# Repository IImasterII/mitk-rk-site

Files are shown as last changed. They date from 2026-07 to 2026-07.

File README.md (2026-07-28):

# Сайт проекта МИТК‑РК

**Гибридное рабочее колесо. Композитно‑металлическая архитектура для высоконапорных центробежных компрессоров.**

Завершённый многостраничный сайт конкурсного инженерного проекта МИТК‑РК.

## Запуск

Сайт автономный: откройте `index.html` в браузере. Интерактивные STL‑модели и визуальные материалы включены в пакет.

При необходимости используется локальный HTTP‑сервер:

```bash
python3 -m http.server 8080
```

После запуска откройте `http://localhost:8080`.

## Фактическая конфигурация проекта

- наружный диаметр рабочего колеса — 200 мм;
- РК‑200‑Э — 10 основных + 10 сплиттерных лопаток;
- РК‑200‑Д — 13 основных + 13 сплиттерных лопаток;
- расчётный режим — 12 000 мин⁻¹;
- стендовый режим — до 3 000 мин⁻¹;
- два варианта геометрии: РК‑200‑Э (приоритет КПД) и РК‑200‑Д (приоритет полного давления);
- два материальных исполнения: М1 — PA12‑CF10 с втулкой из стали 40Х Ø30/Ø22×49,5 мм; М2 — М1 с одним наружным слоем углеродной ткани 0,2 мм в эпоксидной матрице;
- команда — 8 участников, Санкт‑Петербург.

## Страницы

- `index.html` — главная и краткая сводка;
- `project.html` — задача, состав проекта, параметры и матрица образцов;
- `software.html` — параметрическое проектирование;
- `models.html` — конструкции РК‑200‑Э и РК‑200‑Д;
- `drawings.html` — галерея всех 9 чертежей с точными превью и скачиванием CDW/DWG;
- `stand.html` — архитектура испытательного стенда РК‑200;
- `stand-schemes.html` — электрическая и функциональная схемы с полноразмерным просмотром;
- `stand-budget.html` — ведомость из 41 позиции и подтверждённая смета проекта;
- `technology.html` — материалы и производственный маршрут;
- `validation.html` — расчёты, стендовый режим и контур верификации;
- `economics.html` — расчётная экономическая модель НИОКР;
- `documents.html` — полный комплект: 18 PDF, редактируемые DOCX, схемы, чертежи, CAD, STEP/STL, ANSYS и исходные материалы конкурса.

## Структура полного комплекта

- `documents/` — документация EMTH.19.01.02.59.00.000, позиции 0001–0018;
- `drawings/` — CDW и DWG;
- `cad/` — STEP, SLDPRT и производственные STL;
- `calculations/` — отчёты и видеоматериалы ANSYS;
- `project-materials/` — техническое задание, критерии оценивания и ведомость покупных изделий;
- `downloads/` — основные STEP‑модели и Python‑генератор.

Сайт не использует внешние CDN. Основной ракурс 3D‑моделей — сверху; также доступны вид спереди и свободное вращение.

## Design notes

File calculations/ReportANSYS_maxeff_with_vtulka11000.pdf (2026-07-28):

# Project

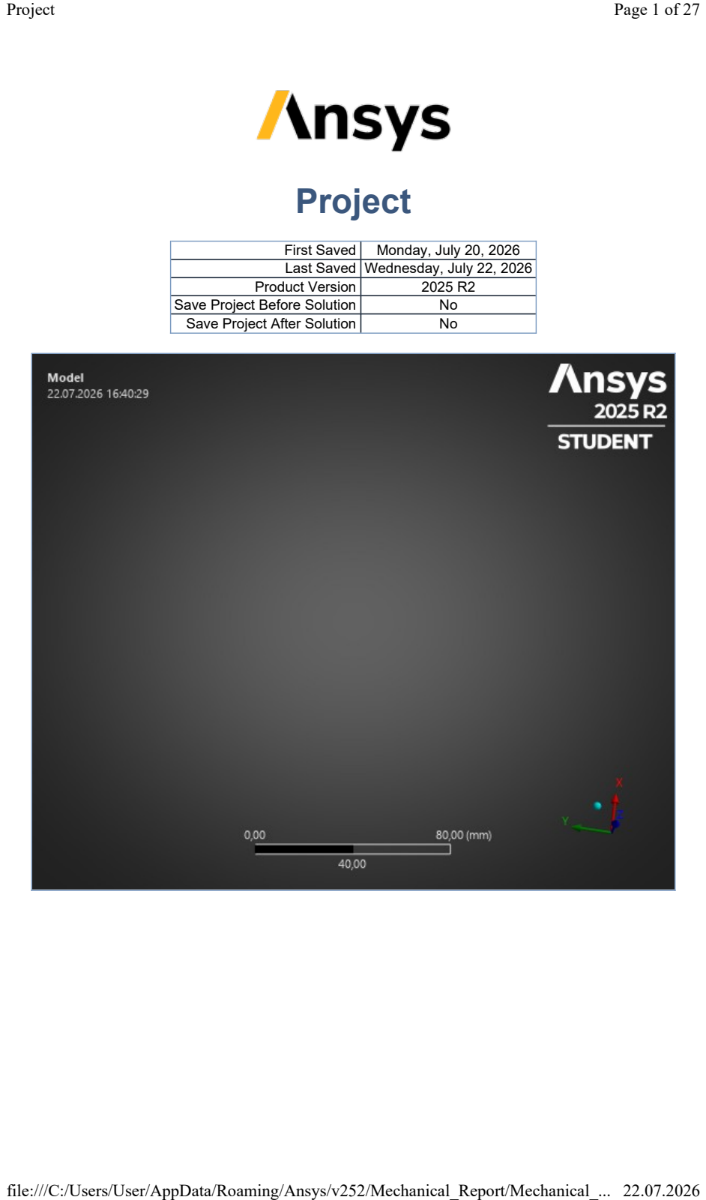
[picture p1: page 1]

First Saved | Monday, July 20, 2026
Last Saved | Wednesday, July 22, 2026
Product Version | 2025 R2
Save Project Before Solution | No
Save Project After Solution | No
Project | Page 1 of 27

file:///C:/Users/User/AppData/Roaming/Ansys/v252/Mechanical_Report/Mechanical_... 22.07.2026

# Contents

l Units

l Model (B4)
¡ Geometry Imports
n Geometry Import (B3)
¡ Geometry
n Parts
¡ Materials
¡ Coordinate Systems
¡ Connections
n Contacts
n Frictional - SYS-1\Твердое тело To Втулка\Solid ¡ Mesh
n Face Sizing
¡ Static Structural (B5)
n Analysis Settings
n Rotational Velocity
n Loads
n Solution (B6)
n Solution Information
n Results
n Stress Tool
n Safety Factor
n Stress Tool 2
n Safety Factor

l Material Data
¡ Steel 40X Gost
¡ PA12-CF10

# Units

TABLE 1

# Model (B4)

TABLE 2
Model (B4) > Geometry Imports

TABLE 3
Model (B4) > Geometry Imports > Geometry Import (B3)
Unit System | Metric (mm, kg, N, s, mV, mA) Degrees rad/s Celsius
Angle | Degrees
Rotational Velocity | rad/s
Temperature | Celsius
Object Name | Geometry Imports
State | Solved
Object Name | Geometry Import (B3)
State | Solved
Definition
Source | C:\Users\User\Desktop\Прочностные характеристики\All_work_files\dp0 \SYS-1\DM\SYS-1.scdocx
Project | Page 2 of 27

Type | SpaceClaim Basic Geometry Options
Solid Bodies | Yes
Surface Bodies | Yes
Line Bodies | Yes
Parameters | Independent
Parameter Key
Attributes | Yes
Attribute Key
Named Selections | Yes
Named Selection Key
Material Properties | Yes
Advanced Geometry Options
Use Associativity | Yes
Coordinate Systems | Yes
Coordinate System Key
Reader Mode Saves Updated File | No
Use Instances | Yes
Smart CAD Update | Yes
Compare Parts On Update | No
Analysis Type | 3-D
Mixed Import Resolution | None
Import Facet Quality | Source
Clean Bodies On Import | No
Stitch Surfaces On Import | None
Decompose Disjoint Geometry | Yes
Enclosure and Symmetry Processing | Yes

## Geometry

TABLE 4
Model (B4) > Geometry
Object Name | Geometry
State | Fully Defined
Definition
Source | C:\Users\User\Desktop\Прочностные характеристики\All_work_files\dp0\SYS-1\DM\SYS-1.scdocx
Type | SpaceClaim
Length Unit | Meters
Element Control | Program Controlled
Display Style | Body Color
Bounding Box
Length X | 200, mm
Length Y | 200, mm
Length Z | 50,512 mm
Properties
Volume | 6,9256e+005 mm³
Mass | 0,8257 kg
Scale Factor Value | 1,
Statistics
Bodies | 2
Active Bodies | 2
Nodes | 127233
Elements | 70153
Project | Page 3 of 27

TABLE 5
Model (B4) > Geometry > Parts
Mesh Metric | None
Update Options
Assign Default Material | No
Basic Geometry Options
Solid Bodies | Yes
Surface Bodies | Yes
Line Bodies | Yes
Parameters | Independent
Parameter Key
Attributes | Yes
Attribute Key
Named Selections | Yes
Named Selection Key
Material Properties | Yes
Advanced Geometry Options
Use Associativity | Yes
Coordinate Systems | Yes
Coordinate System Key
Reader Mode Saves Updated File | No
Use Instances | Yes
Smart CAD Update | Yes
Compare Parts On Update | No
Analysis Type | 3-D
Mixed Import Resolution | None
Import Facet Quality | Source
Clean Bodies On Import | No
Stitch Surfaces On Import | None
Decompose Disjoint Geometry | Yes
ID_GeometryPrefProcessPhysicsDefinition | No
Enclosure and Symmetry Processing | Yes
Object Name | Втулка\Solid | SYS-1\Твердое тело
State | Meshed
Graphics Properties
Visible | Yes
Transparency | 1
Definition
Suppressed | No
Stiffness Behavior | Flexible
Coordinate System | Default Coordinate System
Reference Temperature | By Environment
Treatment | None
Material
Assignment | Steel 40X Gost | PA12-CF10
Nonlinear Effects | Yes
Thermal Strain Effects | Yes
Bounding Box
Length X | 30,04 mm | 200, mm
Length Y | 30,04 mm | 200, mm
Length Z | 49,5 mm | 50,512 mm
Properties
Volume | 15483 mm³ | 6,7708e+005 mm³
Mass | 0,12154 kg | 0,70416 kg
Centroid X | -1,0201e-015 mm | -3,1788e-004 mm
Project | Page 4 of 27

TABLE 6
Model (B4) > Materials
Centroid Y | -0,61774 mm | -1,5158e-005 mm
Centroid Z | 21,75 mm | 12,6 mm
Moment of Inertia Ip1 | 34,891 kg·mm² | 1322,2 kg·mm²
Moment of Inertia Ip2 | 35,835 kg·mm² | 1322,2 kg·mm²
Moment of Inertia Ip3 | 21,119 kg·mm² | 2449,5 kg·mm²
Statistics
Nodes | 4113 | 123120
Elements | 731 | 69422
Mesh Metric | None
CAD Attributes
PartTolerance: | 0,00000001
Color:143.149.175
SCRootPartComponent
Object Name | Materials
State | Fully Defined
Statistics
Materials | 4
Material Assignments | 0

## Coordinate Systems

TABLE 7
Model (B4) > Coordinate Systems > Coordinate System
Object Name | Global Coordinate System
State | Fully Defined
Definition
Type | Cartesian
Coordinate System ID | 0,
Origin
Origin X | 0, mm
Origin Y | 0, mm
Origin Z | 0, mm
Directional Vectors
X Axis Data | [ 1, 0, 0, ]
Y Axis Data | [ 0, 1, 0, ]
Z Axis Data | [ 0, 0, 1, ]
Transfer Properties
Source
Read Only | No

## Connections

TABLE 8
Model (B4) > Connections
Object Name | Connections
State | Fully Defined
Auto Detection
Generate Automatic Connection On Refresh Yes Transparency
Enabled Yes
Statistics
Contacts | 1
Active Contacts | 1
Project | Page 5 of 27

TABLE 9
Model (B4) > Connections > Contacts

TABLE 10
Model (B4) > Connections > Contacts > Contact Regions
Joints | 0
Active Joints | 0
Beams | 0
Active Beams | 0
Bearings | 0
Active Bearings | 0
Springs | 0
Active Springs | 0
Body Interactions | 0
Active Body Interactions | 0
Object Name | Contacts
State | Fully Defined
Definition
Connection Type Contact
Scope
Scoping Method | Geometry Selection
Geometry | All Bodies
Auto Detection
Tolerance Type | Slider
Tolerance Slider | 0,
Tolerance Value | 0,71829 mm
Use Range | No
Face/Face | Yes
Face-Face Angle Tolerance | 75, °
Face Overlap Tolerance | Off
Cylindrical Faces | Include
Face/Edge | No
Edge/Edge | No
Priority | Include All
Group By | Bodies
Search Across | Bodies
Statistics
Connections | 1
Active Connections | 1
Object Name | Frictional - SYS-1\Твердое тело To Втулка\Solid
State | Fully Defined
Scope
Scoping Method | Geometry Selection
Contact | 2 Faces
Target | 1 Face
Contact Bodies | SYS-1\Твердое тело
Target Bodies | Втулка\Solid
Protected | No
Definition
Type | Frictional
Friction Coefficient | 0,2
Scope Mode | Manual
Behavior | Asymmetric
Trim Contact | Off
Contact APDL Name
Project | Page 6 of 27

Target APDL Name
Suppressed | No
Display
Element Normals | No
Advanced
Formulation | Program Controlled
Small Sliding | Program Controlled
Detection Method | Program Controlled
Penetration Tolerance | Program Controlled
Elastic Slip Tolerance | Program Controlled
Normal Stiffness | Program Controlled
Update Stiffness | Program Controlled
Stabilization Damping Factor | 0,
Pinball Region | Program Controlled
Time Step Controls | None
Geometric Modification
Interface Treatment | Add Offset, Ramped Effects
Offset | 0, mm
Contact Geometry Correction | None
Target Geometry Correction | None

## Mesh

TABLE 11
Model (B4) > Mesh
Object Name | Mesh
State | Solved
Display
Display Style Use Geometry Setting Defaults
Physics Preference | Mechanical
Element Order | Program Controlled
Element Size | 3,615 mm
Sizing
Use Adaptive Sizing | Yes
Resolution | Default (2)
Mesh Defeaturing | Yes
Defeature Size | Default
Transition | Fast
Span Angle Center | Coarse
Initial Size Seed | Assembly
Bounding Box Diagonal | 287,32 mm
Average Surface Area | 833,96 mm²
Minimum Edge Length | 2,3673e-004 mm
Quality
Check Mesh Quality | Yes, Errors
Error Limits | Aggressive Mechanical
Target Element Quality | Default (5,e-002)
Smoothing | Medium
Mesh Metric | None
Inflation
Use Automatic Inflation | None
Inflation Option | Smooth Transition
Transition Ratio | 0,272
Maximum Layers | 5
Growth Rate | 1,2
Project | Page 7 of 27

TABLE 12
Model (B4) > Mesh > Mesh Controls

# Static Structural (B5)

TABLE 13
Model (B4) > Analysis

TABLE 14
Model (B4) > Static Structural (B5) > Analysis Settings
Inflation Algorithm | Pre
Inflation Element Type | Wedges
View Advanced Options | No
Advanced
Number of CPUs for Parallel Part Meshing | Program Controlled
Straight Sided Elements | No
Rigid Body Behavior | Dimensionally Reduced
Triangle Surface Mesher | Program Controlled
Topology Checking | Yes
Pinch Tolerance | Please Define
Generate Pinch on Refresh | No
Auto-Map Fillets | No
Automatic Methods
Sheet Body Method | Prime Quad Dominant
Sweepable Body Method | Sweep
Statistics
Nodes | 127233
Elements | 70153
Show Detailed Statistics | No
Object Name | Face Sizing
State | Fully Defined
Scope
Scoping Method | Geometry Selection
Geometry | 60 Faces
Definition
Suppressed | No
Type | Element Size
Element Size | 2,52 mm
Advanced
Defeature Size | Default
Influence Volume | No
Behavior | Soft
Object Name | Static Structural (B5)
State | Solved
Definition
Physics Type | Structural
Analysis Type | Static Structural
Solver Target | Mechanical APDL
Options
Environment Temperature | 22, °C
Generate Input Only | No
Object Name | Analysis Settings
State | Fully Defined
Step Controls
Number Of Steps | 1,
Project | Page 8 of 27

Current Step Number | 1,
Step End Time | 1, s
Auto Time Stepping | On
Define By | Substeps
Initial Substeps | 20,
Minimum Substeps | 10,
Maximum Substeps | 200,
Solver Controls
Solver Type | Program Controlled
Weak Springs | Program Controlled
Solver Pivot Checking | Program Controlled
Large Deflection | On
Inertia Relief | Off
Quasi-Static Solution | On
Rotordynamics Controls
Coriolis Effect | Off
Restart Controls
Generate Restart Points | Program Controlled
Retain Files After Full Solve | No
Combine Restart Files | Program Controlled
Nonlinear Controls
Newton-Raphson Option | Program Controlled
Force Convergence | Program Controlled
Moment Convergence | Program Controlled
Displacement Convergence | Program Controlled
Rotation Convergence | Program Controlled
Line Search | Program Controlled
Stabilization | Program Controlled
Advanced
Inverse Option | No
Contact Split (DMP) | Program Controlled
Output Controls
Output Selection | None
Stress | Yes
Back Stress | No
Strain | Yes
Contact Data | Yes
Nonlinear Data | No
Nodal Forces | No
Volume and Energy | Yes
Euler Angles | Yes
General Miscellaneous | No
Contact Miscellaneous | No
Store Results At | All Time Points
Result File Compression | Program Controlled
Analysis Data Management
Solver Files Directory | C:\Users\User\Desktop\Прочностные характеристики\All_work_files\dp0\SYS-1\MECH\
Future Analysis | None
Scratch Solver Files Directory
Save MAPDL db | No
Contact Summary | Program Controlled
Delete Unneeded Files | Yes
Nonlinear Solution | Yes
Project | Page 9 of 27

TABLE 15
Model (B4) > Static Structural (B5) > Rotations

FIGURE 1
Model (B4) > Static Structural (B5) > Rotational Velocity

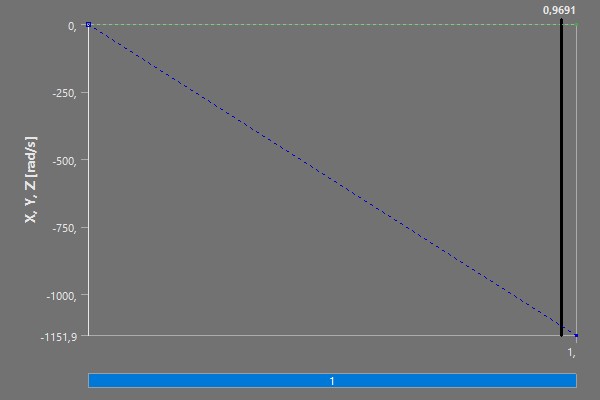
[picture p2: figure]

TABLE 16
Model (B4) > Static Structural (B5) > Loads
Solver Units | Active System
Solver Unit System | nmm
Object Name | Rotational Velocity
State | Fully Defined
Scope
Scoping Method | Geometry Selection
Geometry | All Bodies
Definition
Define By | Components
Coordinate System | Global Coordinate System
X Component | 0, rad/s (ramped)
Y Component | 0, rad/s (ramped)
Z Component | -1151,9 rad/s (ramped)
X Coordinate | 1,0191e-015 mm
Y Coordinate | -0,61961 mm
Z Coordinate | 46,5 mm
Suppressed | No
Object Name | Condition Thermal | Pressure | Cylindrical Support | Remote Displacement
State | Fully Defined | | Suppressed | Fully Defined
Scope
Scoping Method | Geometry Selection
Geometry | 2 Bodies | 60 Faces | 1 Face
Coordinate System | | Global Coordinate System
Project | Page 10 of 27

FIGURE 2
Model (B4) > Static Structural (B5) > Thermal Condition

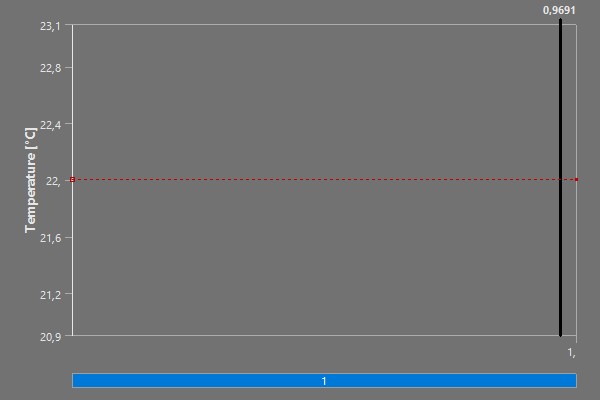
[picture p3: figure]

FIGURE 3
Model (B4) > Static Structural (B5) > Pressure
X Coordinate | 2,7818e-016 mm
Y Coordinate | 2,6427e-016 mm
Z Coordinate | 21,75 mm
Location | Defined
Definition
Type | Condition Thermal | Pressure | Cylindrical Support | Remote Displacement
Magnitude | 22, °C (ramped) | 0,10132 MPa (ramped)
Suppressed | No | | Yes | No
Define By | | Normal To
Applied By | | Surface Effect
Loaded Area | | Deformed
Radial | | | Fixed
Axial | | | Fixed
Tangential | | | Fixed
X Component | | | | 0, mm (ramped)
Y Component | | | | 0, mm (ramped)
Z Component | | | | 0, mm (ramped)
Rotation X | | | | 0, ° (ramped)
Rotation Y | | | | 0, ° (ramped)
Rotation Z | | | | 0, ° (ramped)
Behavior | | | | Deformable
Advanced
Pinball Region | All
Project | Page 11 of 27

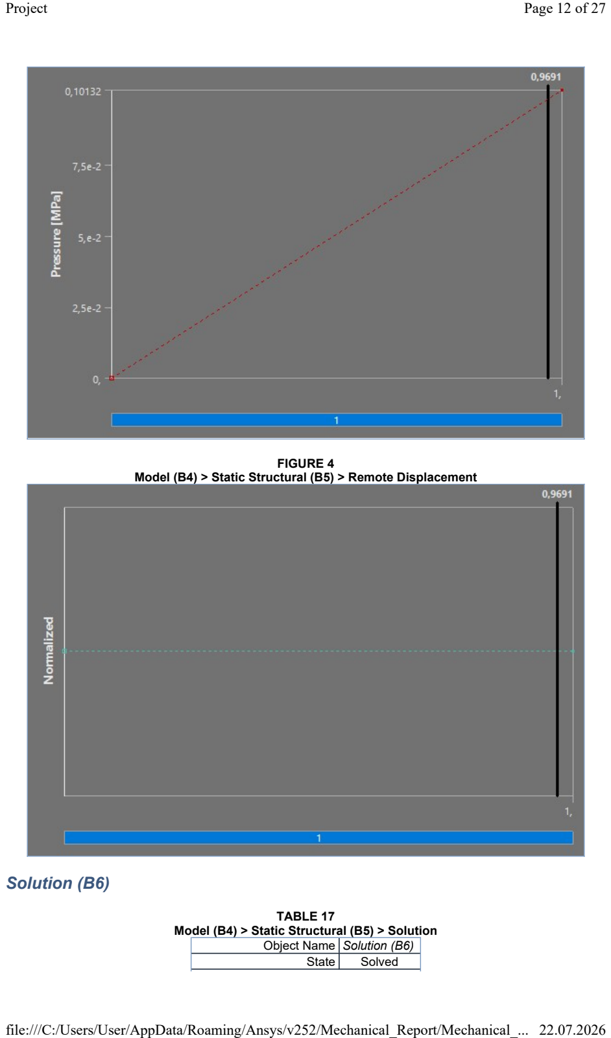
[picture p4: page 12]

FIGURE 4
Model (B4) > Static Structural (B5) > Remote Displacement

## Solution (B6)

TABLE 17
Model (B4) > Static Structural (B5) > Solution
Object Name | Solution (B6)
State | Solved
Project | Page 12 of 27

TABLE 18
Model (B4) > Static Structural (B5) > Solution (B6) > Solution Information

TABLE 19
Model (B4) > Static Structural (B5) > Solution (B6) > Results

Adaptive Mesh Refinement
Max Refinement Loops | 1,
Refinement Depth | 2,
Information
Status | Done
MAPDL Elapsed Time | 3 h 42 m
MAPDL Memory Used | 5,6309 GB
MAPDL Result File Size | 3,0167 GB
Post Processing
Beam Section Results | No
On Demand Stress/Strain | No
Object Name | Solution Information
State | Solved
Solution Information
Solution Output | Solver Output
Newton-Raphson Residuals | 0
Identify Element Violations | 5
Update Interval | 2,5 s
Display Points | All
FE Connection Visibility
Activate Visibility | Yes
Display | All FE Connectors
Draw Connections Attached To | All Nodes
Line Color | Connection Type
Visible on Results | No
Line Thickness | Single
Display Type | Lines
Object Name | Total Deformation | Equivalent Stress | Equivalent Stress 2
State | Solved
Scope
Scoping Method | Geometry Selection
Geometry | All Bodies | 148 Faces
Definition
Type | Total Deformation | Equivalent (von-Mises) Stress
By | Time
Display Time | Last
Separate Data by Entity | No
Calculate Time History | Yes
Identifier
Suppressed | No
Results
Minimum | 1,4279e-004 mm | 1,7846e-002 MPa
Maximum | 1,0777e+005 mm | 10,986 MPa
Average | 1,0429e+005 mm | 2,1044 MPa | 2,3405 MPa
Minimum Occurs On | Втулка\Solid | SYS-1\Твердое тело
Maximum Occurs On | SYS-1\Твердое тело
Minimum Value Over Time
Minimum | 1,2398e-006 mm | 7,3146e-005 MPa
Maximum | 1,4279e-004 mm | 1,7846e-002 MPa
Maximum Value Over Time
Project | Page 13 of 27

FIGURE 5
Model (B4) > Static Structural (B5) > Solution (B6) > Total Deformation

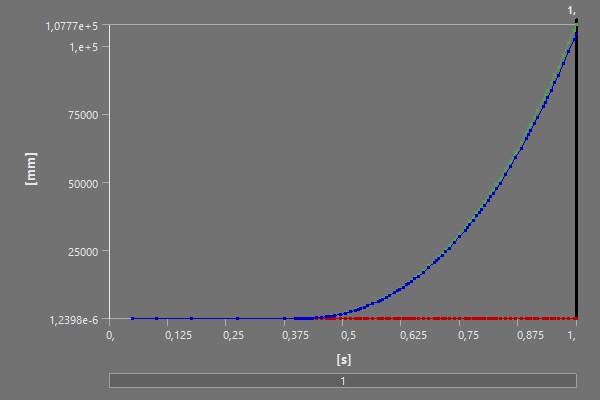
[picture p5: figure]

TABLE 20
Model (B4) > Static Structural (B5) > Solution (B6) > Total Deformation
Minimum | 1,4328e-003 mm | 1,9866 MPa | 0,23765 MPa
Maximum | 1,0777e+005 mm | 15,439 MPa | 10,986 MPa
Information
Time | 1, s
Load Step | 1
Substep | 84
Iteration Number | 1024
Integration Point Results
Display Option | Averaged
Average Across Bodies | No
Time [s] | Minimum [mm] | Maximum [mm] | Average [mm]
5,e-002 | 1,2398e-006 | 1,4328e-003 | 1,0855e-003
0,1 | 2,2123e-006 | 2,9874e-003 | 2,0608e-003
0,175 | 1,7719e-006 | 6,2115e-003 | 3,4405e-003
0,275 | 3,0775e-006 | 1,3459e-002 | 5,4998e-003
0,375 | 1,2482e-005 | 2,4413e-002 | 8,2398e-003
0,3975 | 1,425e-005 | 2,6847e-002 | 9,1412e-003
0,4025 | 2,0849e-006 | 1,0426 | 0,97608
0,4075 | 2,2201e-006 | 4,2316 | 4,004
0,4125 | 1,1519e-005 | 10,612 | 10,103
0,4175 | 1,1515e-005 | 21,418 | 20,468
0,4225 | 1,004e-005 | 38,019 | 36,283
0,4275 | 2,6089e-005 | 65,218 | 62,57
0,435 | 2,7002e-005 | 130,82 | 126,
0,4425 | 2,7931e-005 | 221,78 | 213,87
0,45375 | 2,9355e-005 | 416,49 | 402,03
0,465 | 3,0814e-005 | 670,76 | 647,87
Project | Page 14 of 27

0,47 | 3,1482e-005 | 795,7 | 768,66
0,475 | 3,2157e-005 | 932,68 | 901,11
0,4825 | 3,3183e-005 | 1165,6 | 1126,4
0,49375 | 3,4753e-005 | 1578,4 | 1525,5
0,505 | 3,6358e-005 | 2055,8 | 1987,3
0,51625 | 3,7999e-005 | 2599,2 | 2513,
0,5275 | 3,9677e-005 | 3210, | 3104,1
0,5325 | 4,0434e-005 | 3494,9 | 3379,8
0,5375 | 4,1199e-005 | 3793,4 | 3668,6
0,545 | 4,2359e-005 | 4272,1 | 4131,9
0,5525 | 4,3535e-005 | 4782,2 | 4625,6
0,56375 | 4,5329e-005 | 5619,4 | 5435,9
0,575 | 4,7159e-005 | 6530,1 | 6317,4
0,58 | 4,7984e-005 | 6949,5 | 6723,4
0,585 | 4,8816e-005 | 7383,7 | 7143,6
0,5925 | 5,0078e-005 | 8068,5 | 7806,5
0,6 | 5,1356e-005 | 8787,5 | 8502,5
0,61125 | 5,3303e-005 | 9944,1 | 9622,
0,61625 | 5,4179e-005 | 10474 | 10135
0,62125 | 5,5063e-005 | 11019 | 10662
0,62875 | 5,6403e-005 | 11873 | 11489
0,63625 | 5,7758e-005 | 12763 | 12350
0,64125 | 5,8671e-005 | 13372 | 12940
0,64625 | 5,9591e-005 | 13998 | 13545
0,65375 | 6,0984e-005 | 14974 | 14490
0,66125 | 6,2393e-005 | 15987 | 15470
0,6725 | 6,4536e-005 | 17593 | 17024
0,68375 | 6,6716e-005 | 19286 | 18663
0,695 | 6,8932e-005 | 21068 | 20387
0,7 | 6,9929e-005 | 21877 | 21170
0,705 | 7,0932e-005 | 22705 | 21970
0,7125 | 7,2451e-005 | 23986 | 23210
0,72 | 7,3986e-005 | 25307 | 24489
0,7275 | 7,5537e-005 | 26670 | 25808
0,73875 | 7,7893e-005 | 28809 | 27877
0,75 | 8,0286e-005 | 31042 | 30039
0,76125 | 8,2715e-005 | 33373 | 32293
0,76625 | 8,3806e-005 | 34427 | 33314
0,77125 | 8,4904e-005 | 35502 | 34354
0,77875 | 8,6565e-005 | 37157 | 35955
0,78625 | 8,8242e-005 | 38856 | 37600
0,79125 | 8,9369e-005 | 40009 | 38716
0,79625 | 9,0503e-005 | 41182 | 39850
0,80375 | 9,2217e-005 | 42986 | 41597
0,81125 | 9,3948e-005 | 44836 | 43387
0,81625 | 9,511e-005 | 46090 | 44600
0,82125 | 9,628e-005 | 47365 | 45833
0,82875 | 9,8048e-005 | 49323 | 47728
0,83625 | 9,9832e-005 | 51328 | 49669
0,8475 | 1,0254e-004 | 54443 | 52683
0,85875 | 1,0528e-004 | 57666 | 55802
0,87 | 1,0806e-004 | 60999 | 59028
0,88125 | 1,1087e-004 | 64444 | 62361
0,8925 | 1,1372e-004 | 68001 | 65802
0,8975 | 1,15e-004 | 69604 | 67354
0,9025 | 1,1629e-004 | 71230 | 68927
0,91
Project | Page 15 of 27

FIGURE 6
Model (B4) > Static Structural (B5) > Solution (B6) > Equivalent Stress

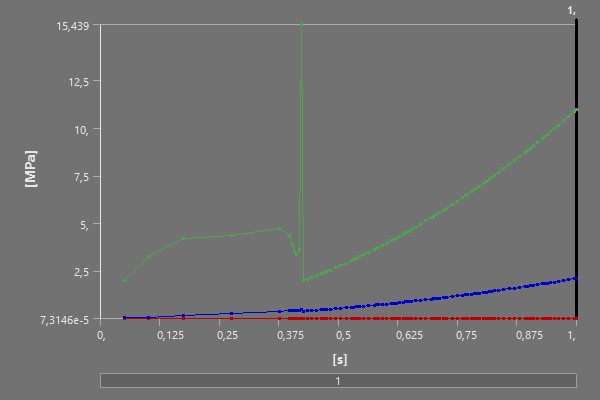
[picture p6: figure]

TABLE 21
Model (B4) > Static Structural (B5) > Solution (B6) > Equivalent Stress
1,1823e-004 | 73719 | 71336
0,9175 | 1,2019e-004 | 76260 | 73794
0,92875 | 1,2315e-004 | 80187 | 77595
0,93375 | 1,2448e-004 | 81956 | 79307
0,93875 | 1,2582e-004 | 83748 | 81041
0,94625 | 1,2784e-004 | 86489 | 83693
0,95375 | 1,2988e-004 | 89284 | 86397
0,96125 | 1,3193e-004 | 92131 | 89153
0,9725 | 1,3504e-004 | 96525 | 93405
0,98375 | 1,3818e-004 | 1,0104e+005 | 97776
0,995 | 1,4136e-004 | 1,0568e+005 | 1,0227e+005
1, | 1,4279e-004 | 1,0777e+005 | 1,0429e+005
Time [s] | Minimum [MPa] | Maximum [MPa] | Average [MPa]
5,e-002 | 7,3146e-005 | 1,9964 | 3,5494e-002
0,1 | 2,2397e-004 | 3,2765 | 7,2371e-002
0,175 | 3,6712e-004 | 4,2101 | 0,13727
0,275 | 8,8443e-004 | 4,3543 | 0,24391
0,375 | 1,8378e-003 | 4,7236 | 0,37386
0,3975 | 2,004e-003 | 4,3431 | 0,40014
0,4025 | 2,0147e-003 | 3,8929 | 0,40027
0,4075 | 2,1143e-003 | 3,5418 | 0,40188
0,4125 | 2,2809e-003 | 3,3372 | 0,40633
0,4175 | 2,3603e-003 | 3,6235 | 0,41341
0,4225 | 1,6322e-003 | 15,439 | 0,45151
0,4275 | 2,5876e-003 | 1,9866 | 0,38542
0,435 | 2,703e-003 | 2,0574 | 0,39897
0,4425 | 2,8822e-003 | 2,1298 | 0,41287
Project | Page 16 of 27

0,45375 | 2,9273e-003 | 2,2404 | 0,43415
0,465 | 3,2618e-003 | 2,3534 | 0,45632
0,47 | 3,144e-003 | 2,4069 | 0,466
0,475 | 3,2452e-003 | 2,4578 | 0,47569
0,4825 | 3,5754e-003 | 2,5366 | 0,49149
0,49375 | 3,495e-003 | 2,6572 | 0,51402
0,505 | 3,7197e-003 | 2,7818 | 0,53799
0,51625 | 3,9879e-003 | 2,9085 | 0,56232
0,5275 | 4,4284e-003 | 3,0384 | 0,58854
0,5325 | 4,4132e-003 | 3,0982 | 0,59852
0,5375 | 4,5706e-003 | 3,154 | 0,60894
0,545 | 4,6835e-003 | 3,2429 | 0,62594
0,5525 | 4,9027e-003 | 3,3348 | 0,64361
0,56375 | 5,3755e-003 | 3,4724 | 0,67036
0,575 | 5,6832e-003 | 3,6146 | 0,69757
0,58 | 5,6618e-003 | 3,6829 | 0,71047
0,585 | 5,5391e-003 | 3,7418 | 0,72162
0,5925 | 5,8065e-003 | 3,838 | 0,73994
0,6 | 6,3535e-003 | 3,9388 | 0,75973
0,61125 | 6,4307e-003 | 4,0867 | 0,78789
0,61625 | 6,3227e-003 | 4,1615 | 0,80168
0,62125 | 6,4632e-003 | 4,2237 | 0,8137
0,62875 | 6,893e-003 | 4,3259 | 0,83367
0,63625 | 7,0567e-003 | 4,4321 | 0,85397
0,64125 | 6,8828e-003 | 4,5046 | 0,86726
0,64625 | 6,9775e-003 | 4,573 | 0,88028
0,65375 | 7,2085e-003 | 4,6786 | 0,90065
0,66125 | 7,3746e-003 | 4,7891 | 0,92172
0,6725 | 7,8068e-003 | 4,952 | 0,95326
0,68375 | 8,2441e-003 | 5,1215 | 0,98602
0,695 | 8,2489e-003 | 5,2904 | 1,019
0,7 | 8,2747e-003 | 5,3711 | 1,0327
0,705 | 8,4189e-003 | 5,443 | 1,0473
0,7125 | 8,9486e-003 | 5,5596 | 1,0698
0,72 | 8,8011e-003 | 5,6789 | 1,0916
0,7275 | 9,2115e-003 | 5,7998 | 1,1156
0,73875 | 9,4895e-003 | 5,9787 | 1,1493
0,75 | 9,7908e-003 | 6,1651 | 1,1855
0,76125 | 9,6867e-003 | 6,3483 | 1,2205
0,76625 | 1,0067e-002 | 6,4382 | 1,2364
0,77125 | 1,0156e-002 | 6,5175 | 1,2524
0,77875 | 1,0587e-002 | 6,6449 | 1,2765
0,78625 | 1,0659e-002 | 6,776 | 1,3011
0,79125 | 1,0878e-002 | 6,8664 | 1,3185
0,79625 | 1,1036e-002 | 6,9515 | 1,3348
0,80375 | 1,1442e-002 | 7,0826 | 1,3605
0,81125 | 1,1338e-002 | 7,2191 | 1,3882
0,81625 | 1,1533e-002 | 7,3082 | 1,4026
0,82125 | 1,1809e-002 | 7,3964 | 1,4197
0,82875 | 1,22e-002 | 7,5313 | 1,446
0,83625 | 1,2089e-002 | 7,6724 | 1,4748
0,8475 | 1,269e-002 | 7,8761 | 1,5121
0,85875 | 1,3114e-002 | 8,0889 | 1,5524
0,87 | 1,2954e-002 | 8,3035 | 1,5944
0,88125 | 1,3458e-002 | 8,5197 | 1,6353
0,8925 | 1,3554e-002 | 8,7271 | 1,6745
0,8975
Project | Page 17 of 27

FIGURE 7
Model (B4) > Static Structural (B5) > Solution (B6) > Equivalent Stress 2

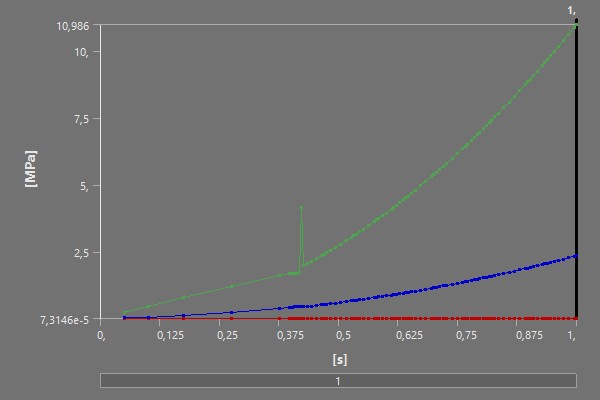
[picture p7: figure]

TABLE 22
Model (B4) > Static Structural (B5) > Solution (B6) > Equivalent Stress 2
1,4286e-002 | 8,8418 | 1,6953
0,9025 | 1,4356e-002 | 8,9351 | 1,7145
0,91 | 1,4663e-002 | 9,0836 | 1,7419
0,9175 | 1,4646e-002 | 9,2384 | 1,7723
0,92875 | 1,4937e-002 | 9,463 | 1,8161
0,93375 | 1,5381e-002 | 9,5729 | 1,8345
0,93875 | 1,5662e-002 | 9,6706 | 1,8537
0,94625 | 1,5841e-002 | 9,826 | 1,8843
0,95375 | 1,6046e-002 | 9,9845 | 1,9133
0,96125 | 1,6284e-002 | 10,146 | 1,9472
0,9725 | 1,6806e-002 | 10,38 | 1,99
0,98375 | 1,7114e-002 | 10,625 | 2,037
0,995 | 1,7241e-002 | 10,87 | 2,0839
1, | 1,7846e-002 | 10,986 | 2,1044
Time [s] | Minimum [MPa] | Maximum [MPa] | Average [MPa]
5,e-002 | 7,3146e-005 | 0,23765 | 2,0517e-002
0,1 | 2,2397e-004 | 0,45237 | 4,8273e-002
0,175 | 3,6712e-004 | 0,77114 | 0,10802
0,275 | 8,8443e-004 | 1,197 | 0,22325
0,375 | 1,8378e-003 | 1,6209 | 0,37955
0,3975 | 2,004e-003 | 1,6845 | 0,41792
0,4025 | 2,0147e-003 | 1,6709 | 0,42403
0,4075 | 2,1143e-003 | 1,6684 | 0,43017
0,4125 | 2,2809e-003 | 1,6835 | 0,43659
0,4175 | 2,3603e-003 | 1,7268 | 0,44262
0,4225 | 1,6322e-003 | 4,1404 | 0,46066
0,4275 | 2,5876e-003 | 1,9866 | 0,42996
Project | Page 18 of 27

0,435 | 2,703e-003 | 2,0574 | 0,44504
0,4425 | 2,8822e-003 | 2,1298 | 0,4605
0,45375 | 2,9273e-003 | 2,2404 | 0,48414
0,465 | 3,2618e-003 | 2,3534 | 0,50976
0,47 | 3,144e-003 | 2,4069 | 0,51958
0,475 | 3,2452e-003 | 2,4578 | 0,53037
0,4825 | 3,5754e-003 | 2,5366 | 0,54826
0,49375 | 3,495e-003 | 2,6572 | 0,57295
0,505 | 3,7197e-003 | 2,7818 | 0,59957
0,51625 | 3,9879e-003 | 2,9085 | 0,62661
0,5275 | 4,4284e-003 | 3,0384 | 0,65705
0,5325 | 4,4132e-003 | 3,0982 | 0,66692
0,5375 | 4,5706e-003 | 3,154 | 0,67861
0,545 | 4,6835e-003 | 3,2429 | 0,69741
0,5525 | 4,9027e-003 | 3,3348 | 0,71705
0,56375 | 5,3755e-003 | 3,4724 | 0,74665
0,575 | 5,6832e-003 | 3,6146 | 0,77689
0,58 | 5,6618e-003 | 3,6829 | 0,79137
0,585 | 5,5391e-003 | 3,7418 | 0,804
0,5925 | 5,8065e-003 | 3,838 | 0,82411
0,6 | 6,3535e-003 | 3,9388 | 0,84595
0,61125 | 6,4307e-003 | 4,0867 | 0,87732
0,61625 | 6,3227e-003 | 4,1615 | 0,89283
0,62125 | 6,4632e-003 | 4,2237 | 0,90611
0,62875 | 6,893e-003 | 4,3259 | 0,92818
0,63625 | 7,0567e-003 | 4,4321 | 0,95078
0,64125 | 6,8828e-003 | 4,5046 | 0,96571
0,64625 | 6,9775e-003 | 4,573 | 0,98017
0,65375 | 7,2085e-003 | 4,6786 | 1,0028
0,66125 | 7,3746e-003 | 4,7891 | 1,0262
0,6725 | 7,8068e-003 | 4,952 | 1,0612
0,68375 | 8,2441e-003 | 5,1215 | 1,0974
0,695 | 8,2489e-003 | 5,2904 | 1,1349
0,7 | 8,2747e-003 | 5,3711 | 1,1497
0,705 | 8,4189e-003 | 5,443 | 1,1662
0,7125 | 8,9486e-003 | 5,5596 | 1,1906
0,72 | 8,8011e-003 | 5,6789 | 1,2151
0,7275 | 9,2115e-003 | 5,7998 | 1,2415
0,73875 | 9,4895e-003 | 5,9787 | 1,2791
0,75 | 9,7908e-003 | 6,1651 | 1,3192
0,76125 | 9,6867e-003 | 6,3483 | 1,3598
0,76625 | 1,0067e-002 | 6,4382 | 1,376
0,77125 | 1,0156e-002 | 6,5175 | 1,3942
0,77875 | 1,0587e-002 | 6,6449 | 1,4205
0,78625 | 1,0659e-002 | 6,776 | 1,4479
0,79125 | 1,0878e-002 | 6,8664 | 1,4673
0,79625 | 1,1036e-002 | 6,9515 | 1,4853
0,80375 | 1,1442e-002 | 7,0826 | 1,5137
0,81125 | 1,1338e-002 | 7,2191 | 1,5464
0,81625 | 1,1533e-002 | 7,3082 | 1,5608
0,82125 | 1,1809e-002 | 7,3964 | 1,5797
0,82875 | 1,22e-002 | 7,5313 | 1,6088
0,83625 | 1,2089e-002 | 7,6724 | 1,6427
0,8475 | 1,269e-002 | 7,8761 | 1,6822
0,85875 | 1,3114e-002 | 8,0889 | 1,7271
0,87 | 1,2954e-002 | 8,3035 | 1,7734
0,88125
Project | Page 19 of 27

TABLE 23
Model (B4) > Static Structural (B5) > Solution (B6) > Stress Safety Tools

TABLE 24
Model (B4) > Static Structural (B5) > Solution (B6) > Stress Tool > Results
1,3458e-002 | 8,5197 | 1,819
0,8925 | 1,3554e-002 | 8,7271 | 1,865
0,8975 | 1,4286e-002 | 8,8418 | 1,8859
0,9025 | 1,4356e-002 | 8,9351 | 1,9079
0,91 | 1,4663e-002 | 9,0836 | 1,9376
0,9175 | 1,4646e-002 | 9,2384 | 1,9711
0,92875 | 1,4937e-002 | 9,463 | 2,0218
0,93375 | 1,5381e-002 | 9,5729 | 2,0407
0,93875 | 1,5662e-002 | 9,6706 | 2,0619
0,94625 | 1,5841e-002 | 9,826 | 2,0957
0,95375 | 1,6046e-002 | 9,9845 | 2,1282
0,96125 | 1,6284e-002 | 10,146 | 2,168
0,9725 | 1,6806e-002 | 10,38 | 2,2132
0,98375 | 1,7114e-002 | 10,625 | 2,2655
0,995 | 1,7241e-002 | 10,87 | 2,3173
1, | 1,7846e-002 | 10,986 | 2,3405
Object Name | Stress Tool
State | Solved
Definition
Theory | Max Equivalent Stress
Stress Limit Type | Tensile Yield Per Material
Object Name | Safety Factor
State | Solved
Scope
Scoping Method | Geometry Selection
Geometry | All Bodies
Definition
Type | Safety Factor
By | Time
Display Time | Last
Separate Data by Entity | No
Calculate Time History | Yes
Identifier
Suppressed | No
Integration Point Results
Display Option | Averaged
Average Across Bodies | No
Results
Minimum | 7,0455
Minimum Occurs On | SYS-1\Твердое тело
Minimum Value Over Time
Minimum | 7,0455
Maximum | 15,
Maximum Value Over Time
Minimum | 15,
Maximum | 15,
Information
Time | 1, s
Load Step | 1
Substep | 84
Project | Page 20 of 27

FIGURE 8
Model (B4) > Static Structural (B5) > Solution (B6) > Stress Tool > Safety Factor

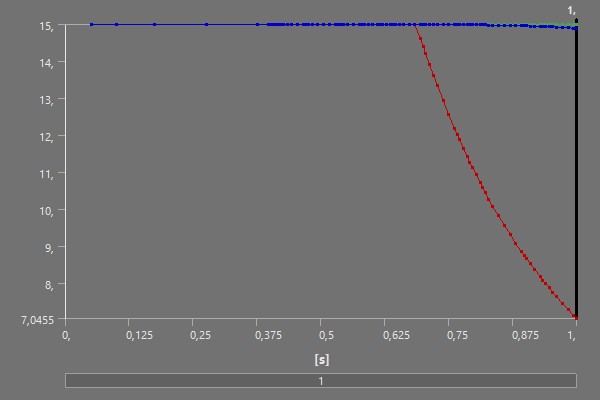
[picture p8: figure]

TABLE 25
Model (B4) > Static Structural (B5) > Solution (B6) > Stress Tool > Safety Factor
Iteration Number | 1024
Time [s] | Minimum | Maximum | Average
5,e-002
15, | 15,

0,1
0,175
0,275
0,375
0,3975
0,4025
0,4075
0,4125
0,4175
0,4225
0,4275
0,435
0,4425
0,45375
0,465
0,47
0,475
0,4825
0,49375
0,505
0,51625
0,5275
0,5325
0,5375
Project | Page 21 of 27

0,545

15,

0,5525
0,56375
0,575
0,58
0,585
0,5925
0,6
0,61125
0,61625
0,62125
0,62875
0,63625
0,64125
0,64625
0,65375
0,66125
0,6725
0,68375
0,695 | 14,63
0,7 | 14,41
0,705 | 14,22
0,7125 | 13,922
0,72 | 13,629 | 14,999
0,7275 | 13,345
0,73875 | 12,946 | 14,998
0,75 | 12,554 | 14,997
0,76125 | 12,192 | 14,996
0,76625 | 12,022 | 14,995 0,77125 | 11,876
0,77875 | 11,648 | 14,994
0,78625 | 11,423 | 14,993
0,79125 | 11,272 | 14,992
0,79625 | 11,134 | 14,991
0,80375 | 10,928 | 14,99
0,81125 | 10,722 | 14,988 0,81625 | 10,591
0,82125 | 10,465 | 14,987
0,82875 | 10,277 | 14,985
0,83625 | 10,088 | 14,983
0,8475 | 9,8272 | 14,981
0,85875 | 9,5687 | 14,978
0,87 | 9,3213 | 14,974
0,88125 | 9,0848 | 14,971
0,8925 | 8,8689 | 14,967
0,8975 | 8,7539 | 14,964
0,9025 | 8,6625 | 14,962
0,91 | 8,5208 | 14,959
0,9175 | 8,3781 | 14,955
0,92875 | 8,1792 | 14,949
0,93375 | 8,0853 | 14,946
0,93875 | 8,0036 | 14,944
0,94625 | 7,8771 | 14,939
0,95375 | 7,752 | 14,934
0,96125 | 7,6288 | 14,927
0,9725 | 7,4568 | 14,919
Project | Page 22 of 27

TABLE 26
Model (B4) > Static Structural (B5) > Solution (B6) > Stress Safety Tools

TABLE 27
Model (B4) > Static Structural (B5) > Solution (B6) > Stress Tool 2 > Results

FIGURE 9
Model (B4) > Static Structural (B5) > Solution (B6) > Stress Tool 2 > Safety Factor
0,98375 | 7,285 | 14,909
0,995 | 7,1208 | 14,898
1, | 7,0455 | 14,893
Object Name | Stress Tool 2
State | Solved
Definition
Theory | Max Equivalent Stress
Stress Limit Type | Tensile Yield Per Material
Object Name | Safety Factor
State | Solved
Scope
Scoping Method | Geometry Selection
Geometry | 148 Faces
Definition
Type | Safety Factor
By | Time
Display Time | Last
Separate Data by Entity | No
Calculate Time History | Yes
Identifier
Suppressed | No
Integration Point Results
Display Option | Averaged
Average Across Bodies | No
Results
Minimum | 7,0455
Minimum Occurs On | SYS-1\Твердое тело
Minimum Value Over Time
Minimum | 7,0455
Maximum | 15,
Maximum Value Over Time
Minimum | 15,
Maximum | 15,
Information
Time | 1, s
Load Step | 1
Substep | 84
Iteration Number | 1024
Project | Page 23 of 27

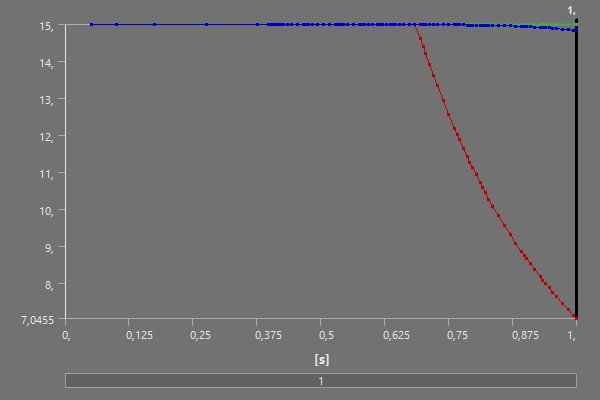
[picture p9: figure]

TABLE 28
Model (B4) > Static Structural (B5) > Solution (B6) > Stress Tool 2 > Safety Factor
Time [s] | Minimum | Maximum | Average
5,e-002
15, | 15,

0,1
0,175
0,275
0,375
0,3975
0,4025
0,4075
0,4125
0,4175
0,4225
0,4275
0,435
0,4425
0,45375
0,465
0,47
0,475
0,4825
0,49375
0,505
0,51625
0,5275
0,5325
0,5375
0,545
0,5525
0,56375
0,575
Project | Page 24 of 27

0,58

15,

0,585
0,5925
0,6
0,61125
0,61625
0,62125
0,62875
0,63625
0,64125
0,64625
0,65375
0,66125
0,6725
0,68375
0,695 | 14,63
0,7 | 14,41
0,705 | 14,22 | 14,999 0,7125 | 13,922
0,72 | 13,629 | 14,998
0,7275 | 13,345 | 14,997
0,73875 | 12,946 | 14,996
0,75 | 12,554 | 14,994
0,76125 | 12,192 | 14,992
0,76625 | 12,022 | 14,991
0,77125 | 11,876 | 14,99
0,77875 | 11,648 | 14,988
0,78625 | 11,423 | 14,986
0,79125 | 11,272 | 14,985
0,79625 | 11,134 | 14,984
0,80375 | 10,928 | 14,982
0,81125 | 10,722 | 14,98
0,81625 | 10,591 | 14,978
0,82125 | 10,465 | 14,977
0,82875 | 10,277 | 14,975
0,83625 | 10,088 | 14,972
0,8475 | 9,8272 | 14,968
0,85875 | 9,5687 | 14,964
0,87 | 9,3213 | 14,96
0,88125 | 9,0848 | 14,954
0,8925 | 8,8689 | 14,949
0,8975 | 8,7539 | 14,945
0,9025 | 8,6625 | 14,942
0,91 | 8,5208 | 14,938
0,9175 | 8,3781 | 14,932
0,92875 | 8,1792 | 14,922
0,93375 | 8,0853 | 14,919
0,93875 | 8,0036 | 14,914
0,94625 | 7,8771 | 14,906
0,95375 | 7,752 | 14,898
0,96125 | 7,6288 | 14,888
0,9725 | 7,4568 | 14,874
0,98375 | 7,285 | 14,858
0,995 | 7,1208 | 14,839
1, | 7,0455 | 14,83
Project | Page 25 of 27

# Material Data

## Steel 40X Gost

TABLE 29
Steel 40X Gost > Constants

TABLE 30
Steel 40X Gost > Color

TABLE 31
Steel 40X Gost > Isotropic Elasticity

TABLE 32
Steel 40X Gost > Tensile Yield Strength

TABLE 33
Steel 40X Gost > Compressive Yield Strength

TABLE 34
Steel 40X Gost > Tensile Ultimate Strength
Density | 7,85e-006 kg mm^-3
Coefficient of Thermal Expansion | 1,2e-005 K^-1
Red | Green | Blue
181, | 155, | 130,
Young's Modulus MPa | Poisson's Ratio | Bulk Modulus MPa | Shear Modulus MPa | Temperature K
2,e+005 | 0,3 | 1,6667e+005 | 76923

Tensile Yield Strength MPa 785,

Compressive Yield Strength MPa 785,

Tensile Ultimate Strength MPa 980,

## PA12-CF10

TABLE 35
PA12-CF10 > Constants

TABLE 36
PA12-CF10 > Color

TABLE 37
PA12-CF10 > Isotropic Elasticity

TABLE 38
PA12-CF10 > Tensile Yield Strength

TABLE 39

Density | 1,04e-006 kg mm^-3
Coefficient of Thermal Expansion | 7,e-005 K^-1
Red | Green | Blue
235, | 222, | 222,
Young's Modulus MPa | Poisson's Ratio | Bulk Modulus MPa | Shear Modulus MPa | Temperature K
3311, | 0,38 | 4598,6 | 1199,6

Tensile Yield Strength MPa 77,4

Project | Page 26 of 27

PA12-CF10 > Compressive Ultimate Strength Compressive Ultimate Strength MPa
90,
Project | Page 27 of 27

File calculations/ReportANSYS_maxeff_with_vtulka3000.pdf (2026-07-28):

# Project*

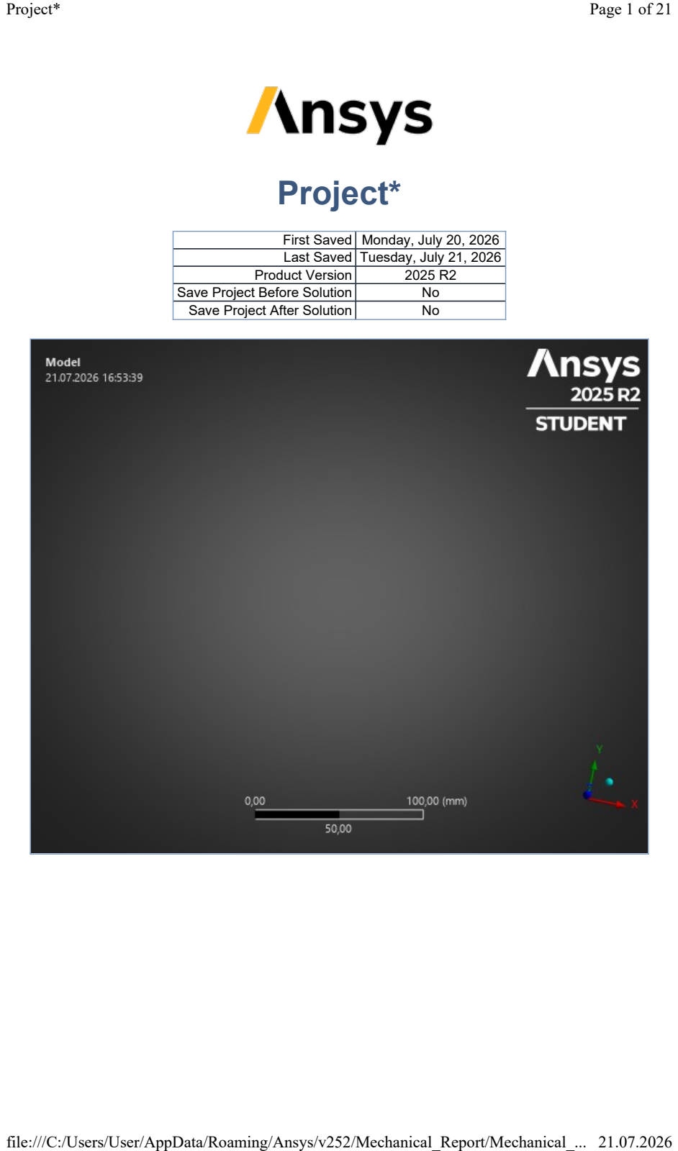
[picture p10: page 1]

First Saved | Monday, July 20, 2026
Last Saved | Tuesday, July 21, 2026
Product Version | 2025 R2
Save Project Before Solution | No
Save Project After Solution | No
Project* | Page 1 of 21

file:///C:/Users/User/AppData/Roaming/Ansys/v252/Mechanical_Report/Mechanical_... 21.07.2026

# Contents

l Units

l Model (B4)
¡ Geometry Imports
n Geometry Import (B3)
¡ Geometry
n Parts
¡ Materials
¡ Coordinate Systems
¡ Connections
n Contacts
n Frictional - SYS-1\Твердое тело To Втулка\Solid ¡ Mesh
n Face Sizing
¡ Static Structural (B5)
n Analysis Settings
n Rotational Velocity
n Loads
n Solution (B6)
n Solution Information
n Results
n Stress Tool
n Safety Factor
n Stress Tool 2
n Safety Factor

l Material Data
¡ Structural Steel
¡ PA12-CF10

# Units

TABLE 1

# Model (B4)

TABLE 2
Model (B4) > Geometry Imports

TABLE 3
Model (B4) > Geometry Imports > Geometry Import (B3)
Unit System | Metric (mm, kg, N, s, mV, mA) Degrees rad/s Celsius
Angle | Degrees
Rotational Velocity | rad/s
Temperature | Celsius
Object Name | Geometry Imports
State | Solved
Object Name | Geometry Import (B3)
State | Solved
Definition
Source | C:\Users\User\Desktop\Прочностные характеристики\All_work_files\dp0 \SYS-1\DM\SYS-1.scdocx
Project* | Page 2 of 21

Type | SpaceClaim Basic Geometry Options
Solid Bodies | Yes
Surface Bodies | Yes
Line Bodies | Yes
Parameters | Independent
Parameter Key
Attributes | Yes
Attribute Key
Named Selections | Yes
Named Selection Key
Material Properties | Yes
Advanced Geometry Options
Use Associativity | Yes
Coordinate Systems | Yes
Coordinate System Key
Reader Mode Saves Updated File | No
Use Instances | Yes
Smart CAD Update | Yes
Compare Parts On Update | No
Analysis Type | 3-D
Mixed Import Resolution | None
Import Facet Quality | Source
Clean Bodies On Import | No
Stitch Surfaces On Import | None
Decompose Disjoint Geometry | Yes
Enclosure and Symmetry Processing | Yes

## Geometry

TABLE 4
Model (B4) > Geometry
Object Name | Geometry
State | Fully Defined
Definition
Source | C:\Users\User\Desktop\Прочностные характеристики\All_work_files\dp0\SYS-1\DM\SYS-1.scdocx
Type | SpaceClaim
Length Unit | Meters
Element Control | Program Controlled
Display Style | Body Color
Bounding Box
Length X | 200, mm
Length Y | 200, mm
Length Z | 50,512 mm
Properties
Volume | 6,9256e+005 mm³
Mass | 0,8257 kg
Scale Factor Value | 1,
Statistics
Bodies | 2
Active Bodies | 2
Nodes | 127233
Elements | 70153
Project* | Page 3 of 21

TABLE 5
Model (B4) > Geometry > Parts
Mesh Metric | None
Update Options
Assign Default Material | No
Basic Geometry Options
Solid Bodies | Yes
Surface Bodies | Yes
Line Bodies | Yes
Parameters | Independent
Parameter Key
Attributes | Yes
Attribute Key
Named Selections | Yes
Named Selection Key
Material Properties | Yes
Advanced Geometry Options
Use Associativity | Yes
Coordinate Systems | Yes
Coordinate System Key
Reader Mode Saves Updated File | No
Use Instances | Yes
Smart CAD Update | Yes
Compare Parts On Update | No
Analysis Type | 3-D
Mixed Import Resolution | None
Import Facet Quality | Source
Clean Bodies On Import | No
Stitch Surfaces On Import | None
Decompose Disjoint Geometry | Yes
ID_GeometryPrefProcessPhysicsDefinition | No
Enclosure and Symmetry Processing | Yes
Object Name | Втулка\Solid | SYS-1\Твердое тело
State | Meshed
Graphics Properties
Visible | Yes
Transparency | 1
Definition
Suppressed | No
Stiffness Behavior | Flexible
Coordinate System | Default Coordinate System
Reference Temperature | By Environment
Treatment | None
Material
Assignment | Structural Steel | PA12-CF10
Nonlinear Effects | Yes
Thermal Strain Effects | Yes
Bounding Box
Length X | 30,04 mm | 200, mm
Length Y | 30,04 mm | 200, mm
Length Z | 49,5 mm | 50,512 mm
Properties
Volume | 15483 mm³ | 6,7708e+005 mm³
Mass | 0,12154 kg | 0,70416 kg
Centroid X | -1,0201e-015 mm | -3,1788e-004 mm
Project* | Page 4 of 21

TABLE 6
Model (B4) > Materials
Centroid Y | -0,61774 mm | -1,5158e-005 mm
Centroid Z | 21,75 mm | 12,6 mm
Moment of Inertia Ip1 | 34,891 kg·mm² | 1322,2 kg·mm²
Moment of Inertia Ip2 | 35,835 kg·mm² | 1322,2 kg·mm²
Moment of Inertia Ip3 | 21,119 kg·mm² | 2449,5 kg·mm²
Statistics
Nodes | 4113 | 123120
Elements | 731 | 69422
Mesh Metric | None
CAD Attributes
PartTolerance: | 0,00000001
Color:143.149.175
SCRootPartComponent
Object Name | Materials
State | Fully Defined
Statistics
Materials | 3
Material Assignments | 0

## Coordinate Systems

TABLE 7
Model (B4) > Coordinate Systems > Coordinate System
Object Name | Global Coordinate System
State | Fully Defined
Definition
Type | Cartesian
Coordinate System ID | 0,
Origin
Origin X | 0, mm
Origin Y | 0, mm
Origin Z | 0, mm
Directional Vectors
X Axis Data | [ 1, 0, 0, ]
Y Axis Data | [ 0, 1, 0, ]
Z Axis Data | [ 0, 0, 1, ]
Transfer Properties
Source
Read Only | No

## Connections

TABLE 8
Model (B4) > Connections
Object Name | Connections
State | Fully Defined
Auto Detection
Generate Automatic Connection On Refresh Yes Transparency
Enabled Yes
Statistics
Contacts | 1
Active Contacts | 1
Project* | Page 5 of 21

TABLE 9
Model (B4) > Connections > Contacts

TABLE 10
Model (B4) > Connections > Contacts > Contact Regions
Joints | 0
Active Joints | 0
Beams | 0
Active Beams | 0
Bearings | 0
Active Bearings | 0
Springs | 0
Active Springs | 0
Body Interactions | 0
Active Body Interactions | 0
Object Name | Contacts
State | Fully Defined
Definition
Connection Type Contact
Scope
Scoping Method | Geometry Selection
Geometry | All Bodies
Auto Detection
Tolerance Type | Slider
Tolerance Slider | 0,
Tolerance Value | 0,71829 mm
Use Range | No
Face/Face | Yes
Face-Face Angle Tolerance | 75, °
Face Overlap Tolerance | Off
Cylindrical Faces | Include
Face/Edge | No
Edge/Edge | No
Priority | Include All
Group By | Bodies
Search Across | Bodies
Statistics
Connections | 1
Active Connections | 1
Object Name | Frictional - SYS-1\Твердое тело To Втулка\Solid
State | Fully Defined
Scope
Scoping Method | Geometry Selection
Contact | 2 Faces
Target | 1 Face
Contact Bodies | SYS-1\Твердое тело
Target Bodies | Втулка\Solid
Protected | No
Definition
Type | Frictional
Friction Coefficient | 0,2
Scope Mode | Manual
Behavior | Asymmetric
Trim Contact | Off
Contact APDL Name
Project* | Page 6 of 21

Target APDL Name
Suppressed | No
Display
Element Normals | No
Advanced
Formulation | Program Controlled
Small Sliding | Program Controlled
Detection Method | Program Controlled
Penetration Tolerance | Program Controlled
Elastic Slip Tolerance | Program Controlled
Normal Stiffness | Program Controlled
Update Stiffness | Program Controlled
Stabilization Damping Factor | 0,
Pinball Region | Program Controlled
Time Step Controls | None
Geometric Modification
Interface Treatment | Add Offset, Ramped Effects
Offset | 0, mm
Contact Geometry Correction | None
Target Geometry Correction | None

## Mesh

TABLE 11
Model (B4) > Mesh
Object Name | Mesh
State | Solved
Display
Display Style Use Geometry Setting Defaults
Physics Preference | Mechanical
Element Order | Program Controlled
Element Size | 3,615 mm
Sizing
Use Adaptive Sizing | Yes
Resolution | Default (2)
Mesh Defeaturing | Yes
Defeature Size | Default
Transition | Fast
Span Angle Center | Coarse
Initial Size Seed | Assembly
Bounding Box Diagonal | 287,32 mm
Average Surface Area | 833,96 mm²
Minimum Edge Length | 2,3673e-004 mm
Quality
Check Mesh Quality | Yes, Errors
Error Limits | Aggressive Mechanical
Target Element Quality | Default (5,e-002)
Smoothing | Medium
Mesh Metric | None
Inflation
Use Automatic Inflation | None
Inflation Option | Smooth Transition
Transition Ratio | 0,272
Maximum Layers | 5
Growth Rate | 1,2
Project* | Page 7 of 21

TABLE 12
Model (B4) > Mesh > Mesh Controls

# Static Structural (B5)

TABLE 13
Model (B4) > Analysis

TABLE 14
Model (B4) > Static Structural (B5) > Analysis Settings
Inflation Algorithm | Pre
Inflation Element Type | Wedges
View Advanced Options | No
Advanced
Number of CPUs for Parallel Part Meshing | Program Controlled
Straight Sided Elements | No
Rigid Body Behavior | Dimensionally Reduced
Triangle Surface Mesher | Program Controlled
Topology Checking | Yes
Pinch Tolerance | Please Define
Generate Pinch on Refresh | No
Auto-Map Fillets | No
Automatic Methods
Sheet Body Method | Prime Quad Dominant
Sweepable Body Method | Sweep
Statistics
Nodes | 127233
Elements | 70153
Show Detailed Statistics | No
Object Name | Face Sizing
State | Fully Defined
Scope
Scoping Method | Geometry Selection
Geometry | 60 Faces
Definition
Suppressed | No
Type | Element Size
Element Size | 2,52 mm
Advanced
Defeature Size | Default
Influence Volume | No
Behavior | Soft
Object Name | Static Structural (B5)
State | Solved
Definition
Physics Type | Structural
Analysis Type | Static Structural
Solver Target | Mechanical APDL
Options
Environment Temperature | 22, °C
Generate Input Only | No
Object Name | Analysis Settings
State | Fully Defined
Step Controls
Number Of Steps | 1,
Project* | Page 8 of 21

Current Step Number | 1,
Step End Time | 1, s
Auto Time Stepping | On
Define By | Substeps
Initial Substeps | 20,
Minimum Substeps | 10,
Maximum Substeps | 200,
Solver Controls
Solver Type | Program Controlled
Weak Springs | Program Controlled
Solver Pivot Checking | Program Controlled
Large Deflection | On
Inertia Relief | Off
Quasi-Static Solution | On
Rotordynamics Controls
Coriolis Effect | Off
Restart Controls
Generate Restart Points | Program Controlled
Retain Files After Full Solve | No
Combine Restart Files | Program Controlled
Nonlinear Controls
Newton-Raphson Option | Program Controlled
Force Convergence | Program Controlled
Moment Convergence | Program Controlled
Displacement Convergence | Program Controlled
Rotation Convergence | Program Controlled
Line Search | Program Controlled
Stabilization | Program Controlled
Advanced
Inverse Option | No
Contact Split (DMP) | Program Controlled
Output Controls
Output Selection | None
Stress | Yes
Back Stress | No
Strain | Yes
Contact Data | Yes
Nonlinear Data | No
Nodal Forces | No
Volume and Energy | Yes
Euler Angles | Yes
General Miscellaneous | No
Contact Miscellaneous | No
Store Results At | All Time Points
Result File Compression | Program Controlled
Analysis Data Management
Solver Files Directory | C:\Users\User\Desktop\Прочностные характеристики\All_work_files\dp0\SYS-1\MECH\
Future Analysis | None
Scratch Solver Files Directory
Save MAPDL db | No
Contact Summary | Program Controlled
Delete Unneeded Files | Yes
Nonlinear Solution | Yes
Project* | Page 9 of 21

TABLE 15
Model (B4) > Static Structural (B5) > Rotations

FIGURE 1
Model (B4) > Static Structural (B5) > Rotational Velocity

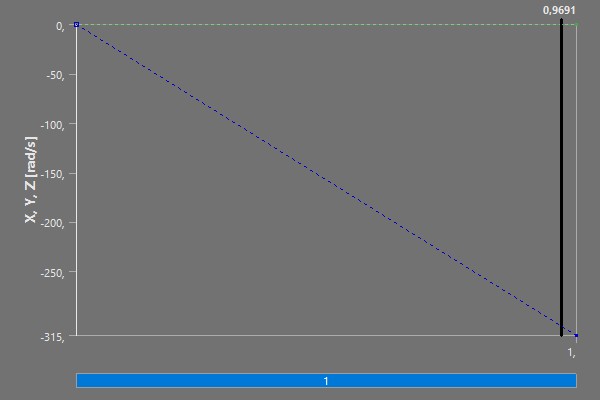
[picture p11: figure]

TABLE 16
Model (B4) > Static Structural (B5) > Loads
Solver Units | Active System
Solver Unit System | nmm
Object Name | Rotational Velocity
State | Fully Defined
Scope
Scoping Method | Geometry Selection
Geometry | All Bodies
Definition
Define By | Components
Coordinate System | Global Coordinate System
X Component | 0, rad/s (ramped)
Y Component | 0, rad/s (ramped)
Z Component | -315, rad/s (ramped)
X Coordinate | 1,0191e-015 mm
Y Coordinate | -0,61961 mm
Z Coordinate | 46,5 mm
Suppressed | No
Object Name | Condition Thermal | Pressure | Cylindrical Support | Remote Displacement
State | Fully Defined | | Suppressed | Fully Defined
Scope
Scoping Method | Geometry Selection
Geometry | 2 Bodies | 60 Faces | 1 Face
Coordinate System | | Global Coordinate System
Project* | Page 10 of 21

FIGURE 2
Model (B4) > Static Structural (B5) > Thermal Condition


FIGURE 3
Model (B4) > Static Structural (B5) > Pressure
X Coordinate | 2,7818e-016 mm
Y Coordinate | 2,6427e-016 mm
Z Coordinate | 21,75 mm
Location | Defined
Definition
Type | Condition Thermal | Pressure | Cylindrical Support | Remote Displacement
Magnitude | 22, °C (ramped) | 0,10132 MPa (ramped)
Suppressed | No | | Yes | No
Define By | | Normal To
Applied By | | Surface Effect
Loaded Area | | Deformed
Radial | | | Fixed
Axial | | | Fixed
Tangential | | | Fixed
X Component | | | | 0, mm (ramped)
Y Component | | | | 0, mm (ramped)
Z Component | | | | 0, mm (ramped)
Rotation X | | | | 0, ° (ramped)
Rotation Y | | | | 0, ° (ramped)
Rotation Z | | | | 0, ° (ramped)
Behavior | | | | Deformable
Advanced
Pinball Region | All
Project* | Page 11 of 21

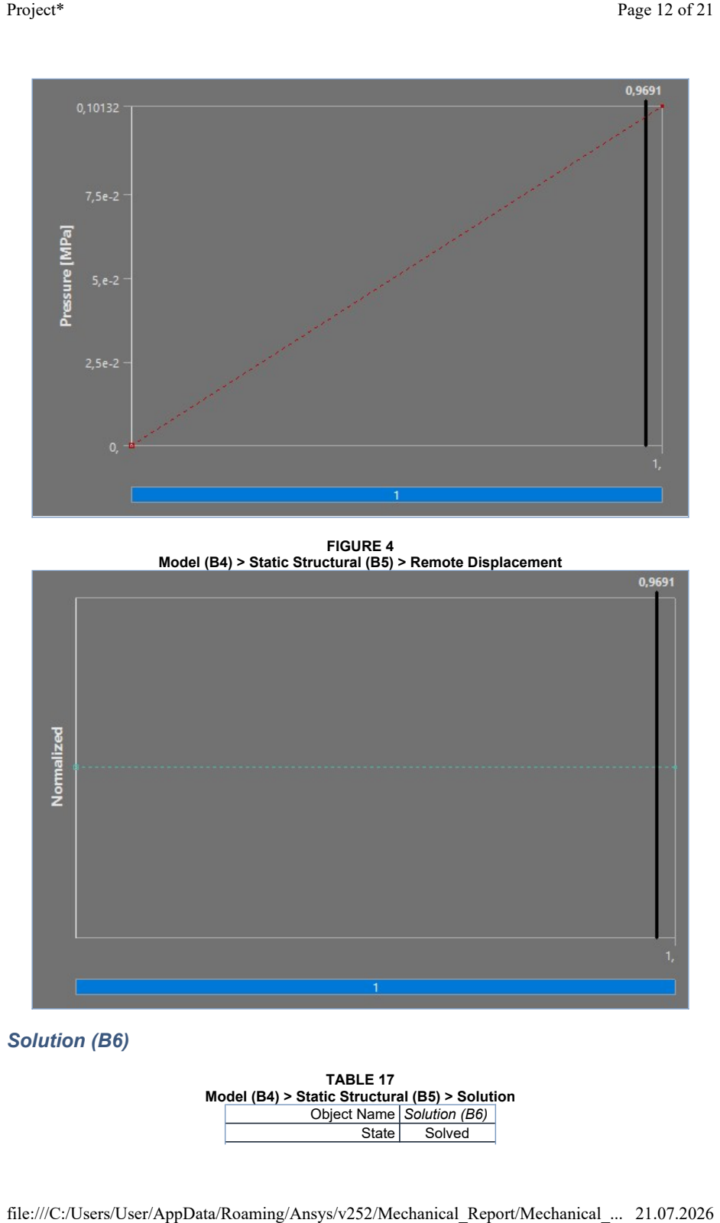
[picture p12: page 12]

FIGURE 4
Model (B4) > Static Structural (B5) > Remote Displacement

## Solution (B6)

TABLE 17
Model (B4) > Static Structural (B5) > Solution
Object Name | Solution (B6)
State | Solved
Project* | Page 12 of 21

TABLE 18
Model (B4) > Static Structural (B5) > Solution (B6) > Solution Information

TABLE 19
Model (B4) > Static Structural (B5) > Solution (B6) > Results

Adaptive Mesh Refinement
Max Refinement Loops | 1,
Refinement Depth | 2,
Information
Status | Done
MAPDL Elapsed Time | 11 m 57 s
MAPDL Memory Used | 5,4404 GB
MAPDL Result File Size | 461,5 MB
Post Processing
Beam Section Results | No
On Demand Stress/Strain | No
Object Name | Solution Information
State | Solved
Solution Information
Solution Output | Solver Output
Newton-Raphson Residuals | 0
Identify Element Violations | 0
Update Interval | 2,5 s
Display Points | All
FE Connection Visibility
Activate Visibility | Yes
Display | All FE Connectors
Draw Connections Attached To | All Nodes
Line Color | Connection Type
Visible on Results | No
Line Thickness | Single
Display Type | Lines
Object Name | Total Deformation | Equivalent Stress | Equivalent Stress 2
State | Solved
Scope
Scoping Method | Geometry Selection
Geometry | All Bodies | 148 Faces
Definition
Type | Total Deformation | Equivalent (von-Mises) Stress
By | Time
Display Time | Last
Separate Data by Entity | No
Calculate Time History | Yes
Identifier
Suppressed | No
Results
Minimum | 8,3535e-006 mm | 1,8623e-003 MPa
Maximum | 2,8294e-002 mm | 39,295 MPa | 4,9873 MPa
Average | 2,0327e-002 mm | 0,76225 MPa | 0,46475 MPa
Minimum Occurs On | Втулка\Solid | SYS-1\Твердое тело
Maximum Occurs On | SYS-1\Твердое тело | Втулка\Solid | SYS-1\Твердое тело
Minimum Value Over Time
Minimum | 1,0707e-006 mm | 7,8788e-005 MPa
Maximum | 3,2091e-005 mm | 1,8623e-003 MPa
Maximum Value Over Time
Project* | Page 13 of 21

FIGURE 5
Model (B4) > Static Structural (B5) > Solution (B6) > Total Deformation

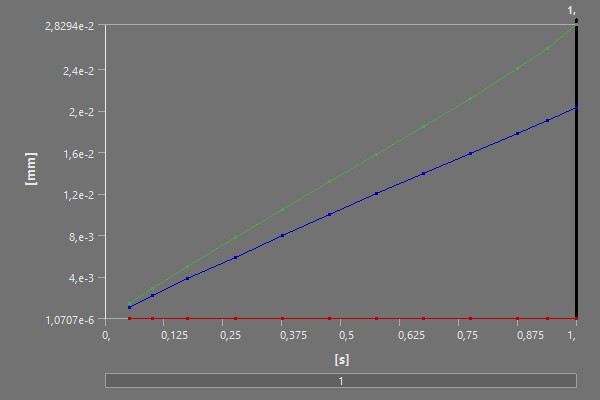
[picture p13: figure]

TABLE 20
Model (B4) > Static Structural (B5) > Solution (B6) > Total Deformation

FIGURE 6
Model (B4) > Static Structural (B5) > Solution (B6) > Equivalent Stress
Minimum | 1,469e-003 mm | 2,3274 MPa | 0,25458 MPa
Maximum | 2,8294e-002 mm | 39,295 MPa | 4,9873 MPa
| Information
Time | 1, s
Load Step | 1
Substep | 12
Iteration Number | 25
Integration Point Results
Display Option | Averaged
Average Across Bodies | No
Time [s] | Minimum [mm] | Maximum [mm] | Average [mm]
5,e-002 | 1,0707e-006 | 1,469e-003 | 1,0997e-003
0,1 | 3,3619e-006 | 2,9138e-003 | 2,1889e-003
0,175 | 6,8908e-006 | 5,0325e-003 | 3,8099e-003
0,275 | 1,1479e-005 | 7,7791e-003 | 5,9182e-003
0,375 | 1,6851e-005 | 1,0486e-002 | 7,9898e-003
0,475 | 2,2356e-005 | 1,315e-002 | 1,0018e-002
0,575 | 2,7312e-005 | 1,5794e-002 | 1,2006e-002
0,675 | 3,0931e-005 | 1,844e-002 | 1,3958e-002
0,775 | 3,2091e-005 | 2,1132e-002 | 1,5886e-002
0,875 | 2,8663e-005 | 2,4052e-002 | 1,7811e-002
0,9375 | 2,6014e-005 | 2,5982e-002 | 1,9007e-002
1, | 8,3535e-006 | 2,8294e-002 | 2,0327e-002
Project* | Page 14 of 21

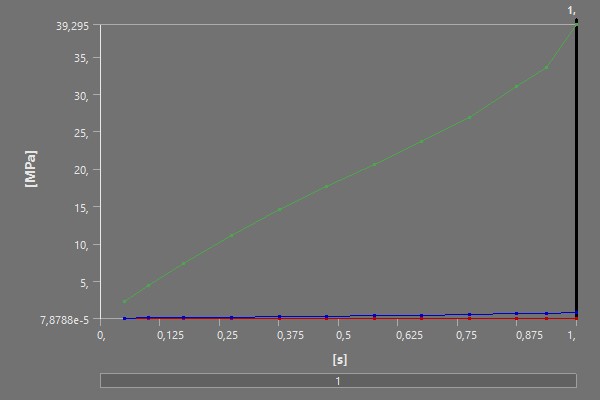
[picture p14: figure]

TABLE 21
Model (B4) > Static Structural (B5) > Solution (B6) > Equivalent Stress

FIGURE 7
Model (B4) > Static Structural (B5) > Solution (B6) > Equivalent Stress 2
Time [s] | Minimum [MPa] | Maximum [MPa] | Average [MPa]
5,e-002 | 7,8788e-005 | 2,3274 | 3,6153e-002
0,1 | 1,5849e-004 | 4,3944 | 6,9296e-002
0,175 | 2,5413e-004 | 7,3688 | 0,11846
0,275 | 3,4877e-004 | 11,132 | 0,18359
0,375 | 4,3608e-004 | 14,513 | 0,24636
0,475 | 5,2916e-004 | 17,625 | 0,30853
0,575 | 7,2954e-004 | 20,603 | 0,37201
0,675 | 9,811e-004 | 23,614 | 0,43919
0,775 | 8,7457e-004 | 26,908 | 0,51355
0,875 | 1,2404e-003 | 30,948 | 0,60154
0,9375 | 1,5947e-003 | 33,536 | 0,65902
1, | 1,8623e-003 | 39,295 | 0,76225
Project* | Page 15 of 21

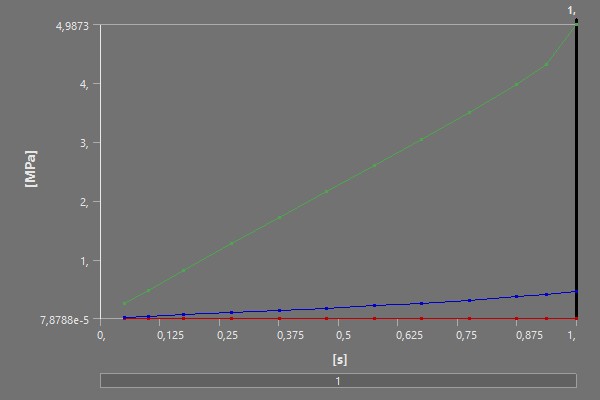
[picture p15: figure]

TABLE 22
Model (B4) > Static Structural (B5) > Solution (B6) > Equivalent Stress 2

TABLE 23
Model (B4) > Static Structural (B5) > Solution (B6) > Stress Safety Tools

TABLE 24
Model (B4) > Static Structural (B5) > Solution (B6) > Stress Tool > Results
Time [s] | Minimum [MPa] | Maximum [MPa] | Average [MPa]
5,e-002 | 7,8788e-005 | 0,25458 | 1,8493e-002
0,1 | 1,5849e-004 | 0,4794 | 3,5984e-002
0,175 | 2,5413e-004 | 0,81825 | 6,2564e-002
0,275 | 3,4877e-004 | 1,2653 | 9,9136e-002
0,375 | 4,3608e-004 | 1,7133 | 0,13637
0,475 | 5,2916e-004 | 2,1548 | 0,17516
0,575 | 7,2954e-004 | 2,5935 | 0,21644
0,675 | 9,811e-004 | 3,0356 | 0,26126
0,775 | 8,7457e-004 | 3,4908 | 0,31112
0,875 | 1,2404e-003 | 3,9767 | 0,36874
0,9375 | 1,5947e-003 | 4,3088 | 0,40686
1, | 1,8623e-003 | 4,9873 | 0,46475
Object Name | Stress Tool
State | Solved
Definition
Theory | Max Equivalent Stress
Stress Limit Type | Tensile Yield Per Material
Object Name | Safety Factor
State | Solved
Scope
Scoping Method | Geometry Selection
Geometry | All Bodies
Definition
Project* | Page 16 of 21

FIGURE 8
Model (B4) > Static Structural (B5) > Solution (B6) > Stress Tool > Safety Factor

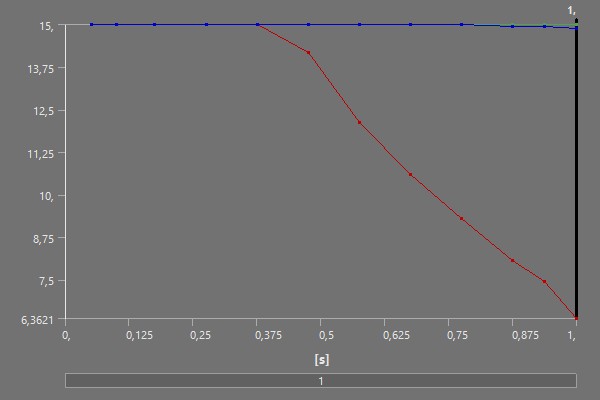
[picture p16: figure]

TABLE 25
Model (B4) > Static Structural (B5) > Solution (B6) > Stress Tool > Safety Factor
Type | Safety Factor
By | Time
Display Time | Last
Separate Data by Entity | No
Calculate Time History | Yes
Identifier
Suppressed | No
Integration Point Results
Display Option | Averaged
Average Across Bodies | No
Results
Minimum | 6,3621
Minimum Occurs On | Втулка\Solid
Minimum Value Over Time
Minimum | 6,3621
Maximum | 15,
Maximum Value Over Time
Minimum | 15,
Maximum | 15,
Information
Time | 1, s
Load Step | 1
Substep | 12
Iteration Number | 25
Time [s] | Minimum | Maximum | Average
5,e-002
0,1
Project* | Page 17 of 21

TABLE 26
Model (B4) > Static Structural (B5) > Solution (B6) > Stress Safety Tools

TABLE 27
Model (B4) > Static Structural (B5) > Solution (B6) > Stress Tool 2 > Results

FIGURE 9
Model (B4) > Static Structural (B5) > Solution (B6) > Stress Tool 2 > Safety Factor

0,175
15,

15,

15,

0,275
0,375
0,475 | 14,184
0,575 | 12,134
0,675 | 10,587 | 14,999
0,775 | 9,2911 | 14,988
0,875 | 8,0779 | 14,955
0,9375 | 7,4547 | 14,93
1, | 6,3621 | 14,882
Object Name | Stress Tool 2
State | Solved
Definition
Theory | Max Equivalent Stress
Stress Limit Type | Tensile Yield Per Material
Object Name | Safety Factor
State | Solved
Scope
Scoping Method | Geometry Selection
Geometry | 148 Faces
Definition
Type | Safety Factor
By | Time
Display Time | Last
Separate Data by Entity | No
Calculate Time History | Yes
Identifier
Suppressed | No
Integration Point Results
Display Option | Averaged
Average Across Bodies | No
Results
Minimum | 9,0229
Minimum Occurs On | SYS-1\Твердое тело
Minimum Value Over Time
Minimum | 9,0229
Maximum | 15,
Maximum Value Over Time
Minimum | 15,
Maximum | 15,
Information
Time | 1, s
Load Step | 1
Substep | 12
Iteration Number | 25
Project* | Page 18 of 21

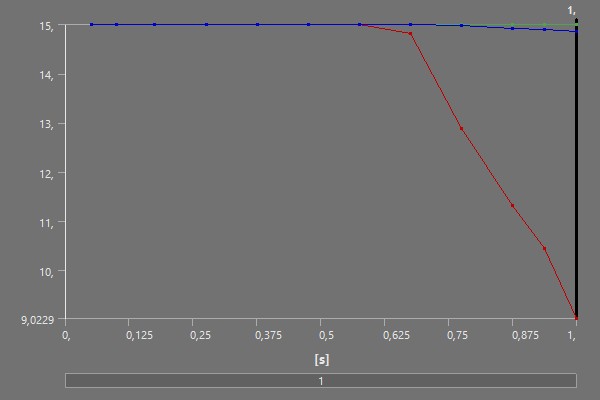
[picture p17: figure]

TABLE 28
Model (B4) > Static Structural (B5) > Solution (B6) > Stress Tool 2 > Safety Factor

# Material Data

Time [s] | Minimum | Maximum | Average
5,e-002 | 15, | 15, | 15,
0,1
0,175
0,275
0,375
0,475
0,575
0,675 | 14,824
0,775 | 12,891 | 14,978
0,875 | 11,316 | 14,925
0,9375 | 10,444 | 14,897
1, | 9,0229 | 14,853

## Structural Steel

TABLE 29
Structural Steel > Constants

TABLE 30
Structural Steel > Color
Density | 7,85e-006 kg mm^-3
Coefficient of Thermal Expansion | 1,2e-005 K^-1
Specific Heat | 4,34e+005 mJ kg^-1 K^-1
Thermal Conductivity | 6,05e-002 W mm^-1 K^-1
Resistivity | 1,7e-004 ohm mm
Red | Green | Blue
Project* | Page 19 of 21

TABLE 31
Structural Steel > Compressive Ultimate Strength

TABLE 32
Structural Steel > Compressive Yield Strength

TABLE 33
Structural Steel > Tensile Yield Strength

TABLE 34
Structural Steel > Tensile Ultimate Strength

TABLE 35
Structural Steel > Isotropic Secant Coefficient of Thermal Expansion

TABLE 36
Structural Steel > S-N Curve

TABLE 37
Structural Steel > Strain-Life Parameters

TABLE 38
Structural Steel > Isotropic Elasticity

TABLE 39
Structural Steel > Isotropic Relative Permeability
132, | 139, | 179,

Compressive Ultimate Strength MPa 0,

Compressive Yield Strength MPa 250,

Tensile Yield Strength MPa 250,

Tensile Ultimate Strength MPa 460,

Zero-Thermal-Strain Reference Temperature K 295,15

Alternating Stress MPa | Cycles | Mean Stress MPa
3999, | 10, | 0,
2827, | 20, | 0,
1896, | 50, | 0,
1413, | 100, | 0,
1069, | 200, | 0,
441, | 2000, | 0,
262, | 10000 | 0,
214, | 20000 | 0,
138, | 1,e+005 | 0,
114, | 2,e+005 | 0,
86,2 | 1,e+006 | 0,
Strength Coefficient MPa | Strength Exponent | Ductility Coefficient | Ductility Exponent | Cyclic Strength Coefficient MPa | Cyclic Strain Hardening Exponent
920, | -0,106 | 0,213 | -0,47 | 1000, | 0,2
Young's Modulus MPa | Poisson's Ratio | Bulk Modulus MPa | Shear Modulus MPa | Temperature K
2,e+005 | 0,3 | 1,6667e+005 | 76923

Relative Permeability
10000
Project* | Page 20 of 21

## PA12-CF10

TABLE 40
PA12-CF10 > Constants

TABLE 41
PA12-CF10 > Color

TABLE 42
PA12-CF10 > Isotropic Elasticity

TABLE 43
PA12-CF10 > Tensile Yield Strength

TABLE 44
PA12-CF10 > Compressive Ultimate Strength
Density | 1,04e-006 kg mm^-3
Coefficient of Thermal Expansion | 7,e-005 K^-1
Red | Green | Blue
235, | 222, | 222,
Young's Modulus MPa | Poisson's Ratio | Bulk Modulus MPa | Shear Modulus MPa | Temperature K
3500, | 0,38 | 4861,1 | 1268,1

Tensile Yield Strength MPa 45,

Compressive Ultimate Strength MPa 90,

Project* | Page 21 of 21

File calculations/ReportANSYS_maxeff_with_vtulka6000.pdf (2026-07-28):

# Project*

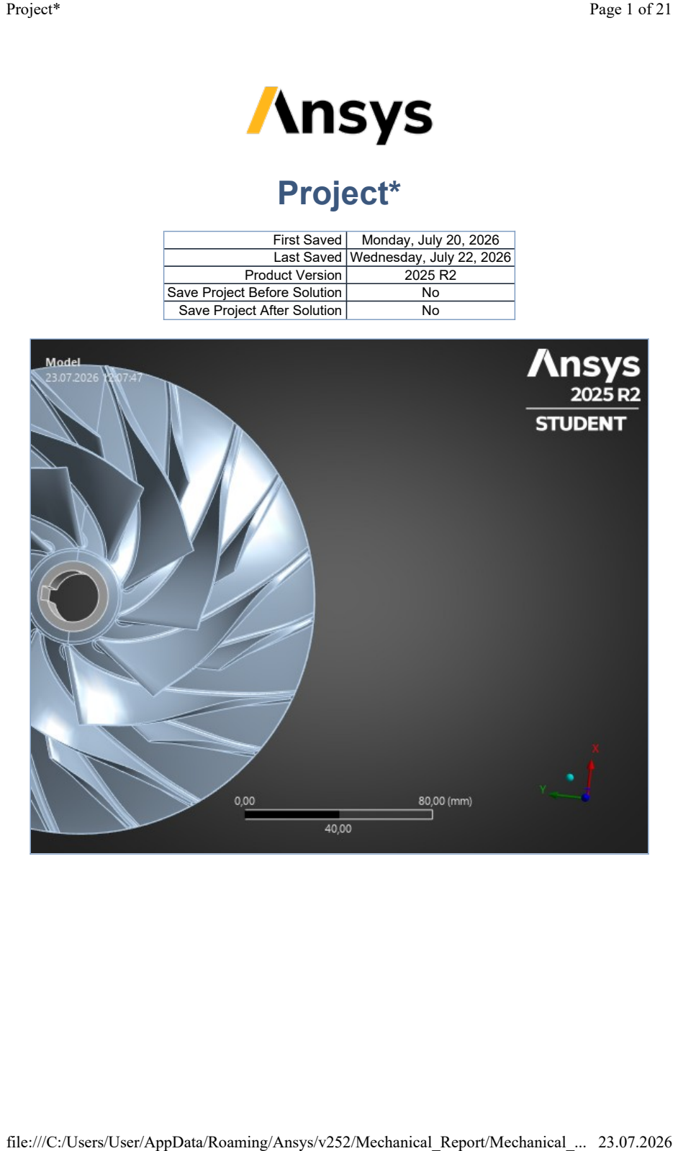
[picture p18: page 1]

First Saved | Monday, July 20, 2026
Last Saved | Wednesday, July 22, 2026
Product Version | 2025 R2
Save Project Before Solution | No
Save Project After Solution | No
Project* | Page 1 of 21

file:///C:/Users/User/AppData/Roaming/Ansys/v252/Mechanical_Report/Mechanical_... 23.07.2026

# Contents

l Units

l Model (B4)
¡ Geometry Imports
n Geometry Import (B3)
¡ Geometry
n Parts
¡ Materials
¡ Coordinate Systems
¡ Connections
n Contacts
n Frictional - SYS-1\Твердое тело To Втулка\Solid ¡ Mesh
n Face Sizing
¡ Static Structural (B5)
n Analysis Settings
n Rotational Velocity
n Loads
n Solution (B6)
n Solution Information
n Results
n Stress Tool
n Safety Factor
n Stress Tool 2
n Safety Factor

l Material Data
¡ Steel 40X Gost
¡ PA12-CF10

# Units

TABLE 1

# Model (B4)

TABLE 2
Model (B4) > Geometry Imports

TABLE 3
Model (B4) > Geometry Imports > Geometry Import (B3)
Unit System | Metric (mm, kg, N, s, mV, mA) Degrees rad/s Celsius
Angle | Degrees
Rotational Velocity | rad/s
Temperature | Celsius
Object Name | Geometry Imports
State | Solved
Object Name | Geometry Import (B3)
State | Solved
Definition
Source | C:\Users\User\Desktop\Прочностные характеристики\All_work_files\dp0 \SYS-1\DM\SYS-1.scdocx
Project* | Page 2 of 21

Type | SpaceClaim Basic Geometry Options
Solid Bodies | Yes
Surface Bodies | Yes
Line Bodies | Yes
Parameters | Independent
Parameter Key
Attributes | Yes
Attribute Key
Named Selections | Yes
Named Selection Key
Material Properties | Yes
Advanced Geometry Options
Use Associativity | Yes
Coordinate Systems | Yes
Coordinate System Key
Reader Mode Saves Updated File | No
Use Instances | Yes
Smart CAD Update | Yes
Compare Parts On Update | No
Analysis Type | 3-D
Mixed Import Resolution | None
Import Facet Quality | Source
Clean Bodies On Import | No
Stitch Surfaces On Import | None
Decompose Disjoint Geometry | Yes
Enclosure and Symmetry Processing | Yes

## Geometry

TABLE 4
Model (B4) > Geometry
Object Name | Geometry
State | Fully Defined
Definition
Source | C:\Users\User\Desktop\Прочностные характеристики\All_work_files\dp0\SYS-1\DM\SYS-1.scdocx
Type | SpaceClaim
Length Unit | Meters
Element Control | Program Controlled
Display Style | Body Color
Bounding Box
Length X | 200, mm
Length Y | 200, mm
Length Z | 50,512 mm
Properties
Volume | 6,9256e+005 mm³
Mass | 0,8257 kg
Scale Factor Value | 1,
Statistics
Bodies | 2
Active Bodies | 2
Nodes | 127233
Elements | 70153
Project* | Page 3 of 21

TABLE 5
Model (B4) > Geometry > Parts
Mesh Metric | None
Update Options
Assign Default Material | No
Basic Geometry Options
Solid Bodies | Yes
Surface Bodies | Yes
Line Bodies | Yes
Parameters | Independent
Parameter Key
Attributes | Yes
Attribute Key
Named Selections | Yes
Named Selection Key
Material Properties | Yes
Advanced Geometry Options
Use Associativity | Yes
Coordinate Systems | Yes
Coordinate System Key
Reader Mode Saves Updated File | No
Use Instances | Yes
Smart CAD Update | Yes
Compare Parts On Update | No
Analysis Type | 3-D
Mixed Import Resolution | None
Import Facet Quality | Source
Clean Bodies On Import | No
Stitch Surfaces On Import | None
Decompose Disjoint Geometry | Yes
ID_GeometryPrefProcessPhysicsDefinition | No
Enclosure and Symmetry Processing | Yes
Object Name | Втулка\Solid | SYS-1\Твердое тело
State | Meshed
Graphics Properties
Visible | Yes
Transparency | 1
Definition
Suppressed | No
Stiffness Behavior | Flexible
Coordinate System | Default Coordinate System
Reference Temperature | By Environment
Treatment | None
Material
Assignment | Steel 40X Gost | PA12-CF10
Nonlinear Effects | Yes
Thermal Strain Effects | Yes
Bounding Box
Length X | 30,04 mm | 200, mm
Length Y | 30,04 mm | 200, mm
Length Z | 49,5 mm | 50,512 mm
Properties
Volume | 15483 mm³ | 6,7708e+005 mm³
Mass | 0,12154 kg | 0,70416 kg
Centroid X | -1,0201e-015 mm | -3,1788e-004 mm
Project* | Page 4 of 21

TABLE 6
Model (B4) > Materials
Centroid Y | -0,61774 mm | -1,5158e-005 mm
Centroid Z | 21,75 mm | 12,6 mm
Moment of Inertia Ip1 | 34,891 kg·mm² | 1322,2 kg·mm²
Moment of Inertia Ip2 | 35,835 kg·mm² | 1322,2 kg·mm²
Moment of Inertia Ip3 | 21,119 kg·mm² | 2449,5 kg·mm²
Statistics
Nodes | 4113 | 123120
Elements | 731 | 69422
Mesh Metric | None
CAD Attributes
PartTolerance: | 0,00000001
Color:143.149.175
SCRootPartComponent
Object Name | Materials
State | Fully Defined
Statistics
Materials | 4
Material Assignments | 0

## Coordinate Systems

TABLE 7
Model (B4) > Coordinate Systems > Coordinate System
Object Name | Global Coordinate System
State | Fully Defined
Definition
Type | Cartesian
Coordinate System ID | 0,
Origin
Origin X | 0, mm
Origin Y | 0, mm
Origin Z | 0, mm
Directional Vectors
X Axis Data | [ 1, 0, 0, ]
Y Axis Data | [ 0, 1, 0, ]
Z Axis Data | [ 0, 0, 1, ]
Transfer Properties
Source
Read Only | No

## Connections

TABLE 8
Model (B4) > Connections
Object Name | Connections
State | Fully Defined
Auto Detection
Generate Automatic Connection On Refresh Yes Transparency
Enabled Yes
Statistics
Contacts | 1
Active Contacts | 1
Project* | Page 5 of 21

TABLE 9
Model (B4) > Connections > Contacts

TABLE 10
Model (B4) > Connections > Contacts > Contact Regions
Joints | 0
Active Joints | 0
Beams | 0
Active Beams | 0
Bearings | 0
Active Bearings | 0
Springs | 0
Active Springs | 0
Body Interactions | 0
Active Body Interactions | 0
Object Name | Contacts
State | Fully Defined
Definition
Connection Type Contact
Scope
Scoping Method | Geometry Selection
Geometry | All Bodies
Auto Detection
Tolerance Type | Slider
Tolerance Slider | 0,
Tolerance Value | 0,71829 mm
Use Range | No
Face/Face | Yes
Face-Face Angle Tolerance | 75, °
Face Overlap Tolerance | Off
Cylindrical Faces | Include
Face/Edge | No
Edge/Edge | No
Priority | Include All
Group By | Bodies
Search Across | Bodies
Statistics
Connections | 1
Active Connections | 1
Object Name | Frictional - SYS-1\Твердое тело To Втулка\Solid
State | Fully Defined
Scope
Scoping Method | Geometry Selection
Contact | 2 Faces
Target | 1 Face
Contact Bodies | SYS-1\Твердое тело
Target Bodies | Втулка\Solid
Protected | No
Definition
Type | Frictional
Friction Coefficient | 0,2
Scope Mode | Manual
Behavior | Asymmetric
Trim Contact | Off
Contact APDL Name
Project* | Page 6 of 21

Target APDL Name
Suppressed | No
Display
Element Normals | No
Advanced
Formulation | Program Controlled
Small Sliding | Program Controlled
Detection Method | Program Controlled
Penetration Tolerance | Program Controlled
Elastic Slip Tolerance | Program Controlled
Normal Stiffness | Program Controlled
Update Stiffness | Each Iteration
Stabilization Damping Factor | 0,
Pinball Region | Radius
Pinball Radius | 3, mm
Time Step Controls | None
Geometric Modification
Interface Treatment | Add Offset, Ramped Effects
Offset | 0, mm
Contact Geometry Correction | None
Target Geometry Correction | None

## Mesh

TABLE 11
Model (B4) > Mesh
Object Name | Mesh
State | Solved
Display
Display Style Use Geometry Setting Defaults
Physics Preference | Mechanical
Element Order | Program Controlled
Element Size | 3,615 mm
Sizing
Use Adaptive Sizing | Yes
Resolution | Default (2)
Mesh Defeaturing | Yes
Defeature Size | Default
Transition | Fast
Span Angle Center | Coarse
Initial Size Seed | Assembly
Bounding Box Diagonal | 287,32 mm
Average Surface Area | 833,96 mm²
Minimum Edge Length | 2,3673e-004 mm
Quality
Check Mesh Quality | Yes, Errors
Error Limits | Aggressive Mechanical
Target Element Quality | Default (5,e-002)
Smoothing | Medium
Mesh Metric | None
Inflation
Use Automatic Inflation | None
Inflation Option | Smooth Transition
Transition Ratio | 0,272
Maximum Layers | 5
Project* | Page 7 of 21

TABLE 12
Model (B4) > Mesh > Mesh Controls

# Static Structural (B5)

TABLE 13
Model (B4) > Analysis

TABLE 14
Model (B4) > Static Structural (B5) > Analysis Settings
Growth Rate | 1,2
Inflation Algorithm | Pre
Inflation Element Type | Wedges
View Advanced Options | No
Advanced
Number of CPUs for Parallel Part Meshing | Program Controlled
Straight Sided Elements | No
Rigid Body Behavior | Dimensionally Reduced
Triangle Surface Mesher | Program Controlled
Topology Checking | Yes
Pinch Tolerance | Please Define
Generate Pinch on Refresh | No
Auto-Map Fillets | No
Automatic Methods
Sheet Body Method | Prime Quad Dominant
Sweepable Body Method | Sweep
Statistics
Nodes | 127233
Elements | 70153
Show Detailed Statistics | No
Object Name | Face Sizing
State | Fully Defined
Scope
Scoping Method | Geometry Selection
Geometry | 60 Faces
Definition
Suppressed | No
Type | Element Size
Element Size | 2,52 mm
Advanced
Defeature Size | Default
Influence Volume | No
Behavior | Soft
Object Name | Static Structural (B5)
State | Solved
Definition
Physics Type | Structural
Analysis Type | Static Structural
Solver Target | Mechanical APDL
Options
Environment Temperature | 22, °C
Generate Input Only | No
Object Name | Analysis Settings
State | Fully Defined
Step Controls
Project* | Page 8 of 21

Number Of Steps | 1,
Current Step Number | 1,
Step End Time | 1, s
Auto Time Stepping | On
Define By | Substeps
Initial Substeps | 20,
Minimum Substeps | 10,
Maximum Substeps | 100,
Solver Controls
Solver Type | Program Controlled
Weak Springs | Program Controlled
Solver Pivot Checking | Program Controlled
Large Deflection | On
Inertia Relief | Off
Quasi-Static Solution | On
Rotordynamics Controls
Coriolis Effect | Off
Restart Controls
Generate Restart Points | Program Controlled
Retain Files After Full Solve | No
Combine Restart Files | Program Controlled
Nonlinear Controls
Newton-Raphson Option | Program Controlled
Force Convergence | Program Controlled
Moment Convergence | Program Controlled
Displacement Convergence | Program Controlled
Rotation Convergence | Program Controlled
Line Search | Program Controlled
Stabilization | Constant
--Method | Energy
--Energy Dissipation Ratio | 1,e-004
--Activation For First Substep | No
--Stabilization Force Limit | 0,2
Advanced
Inverse Option | No
Contact Split (DMP) | Program Controlled
Output Controls
Output Selection | None
Stress | Yes
Back Stress | No
Strain | Yes
Contact Data | Yes
Nonlinear Data | No
Nodal Forces | No
Volume and Energy | Yes
Euler Angles | Yes
General Miscellaneous | No
Contact Miscellaneous | No
Store Results At | All Time Points
Result File Compression | Program Controlled
Analysis Data Management
Solver Files Directory | C:\Users\User\Desktop\Прочностные характеристики\All_work_files\dp0\SYS-1\MECH\
Future Analysis | None
Project* | Page 9 of 21

TABLE 15
Model (B4) > Static Structural (B5) > Rotations

FIGURE 1
Model (B4) > Static Structural (B5) > Rotational Velocity

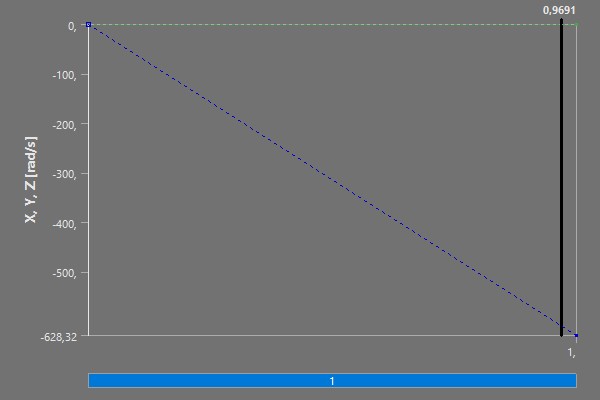
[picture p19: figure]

TABLE 16
Model (B4) > Static Structural (B5) > Loads

Scratch Solver Files
Directory
Save MAPDL db | No
Contact Summary | Program Controlled
Delete Unneeded Files | Yes
Nonlinear Solution | Yes
Solver Units | Active System
Solver Unit System | nmm
Object Name | Rotational Velocity
State | Fully Defined
Scope
Scoping Method | Geometry Selection
Geometry | All Bodies
Definition
Define By | Components
Coordinate System | Global Coordinate System
X Component | 0, rad/s (ramped)
Y Component | 0, rad/s (ramped)
Z Component | -628,32 rad/s (ramped)
X Coordinate | 1,0191e-015 mm
Y Coordinate | -0,61961 mm
Z Coordinate | 46,5 mm
Suppressed | No
Object Name | Thermal
Condition | Pressure | Cylindrical
Support | Remote Displacement
Project* | Page 10 of 21

FIGURE 2
Model (B4) > Static Structural (B5) > Thermal Condition
State | Fully Defined | Suppressed | Fully Defined
Scope
Scoping Method | Geometry Selection
Geometry | 2 Bodies | 60 Faces | 1 Face
Coordinate System | | Global Coordinate System
X Coordinate | | 2,7818e-016 mm
Y Coordinate | | 2,6427e-016 mm
Z Coordinate | | 21,75 mm
Location | | Defined
Definition
Type | Condition Thermal | Pressure | Cylindrical Support | Remote Displacement
Magnitude | 22, °C (ramped) | 0,10132 MPa (ramped)
Suppressed | No | | Yes | No
Define By | | Normal To
Applied By | | Surface Effect
Loaded Area | | Deformed
Radial | | | Fixed
Axial | | | Fixed
Tangential | | | Fixed
X Component | | | | 0, mm (ramped)
Y Component | | | | 0, mm (ramped)
Z Component | | | | 0, mm (ramped)
Rotation X | | | | 0, ° (ramped)
Rotation Y | | | | 0, ° (ramped)
Rotation Z | | | | 0, ° (ramped)
Behavior | | | | Deformable
Advanced
Pinball Region | All
Project* | Page 11 of 21

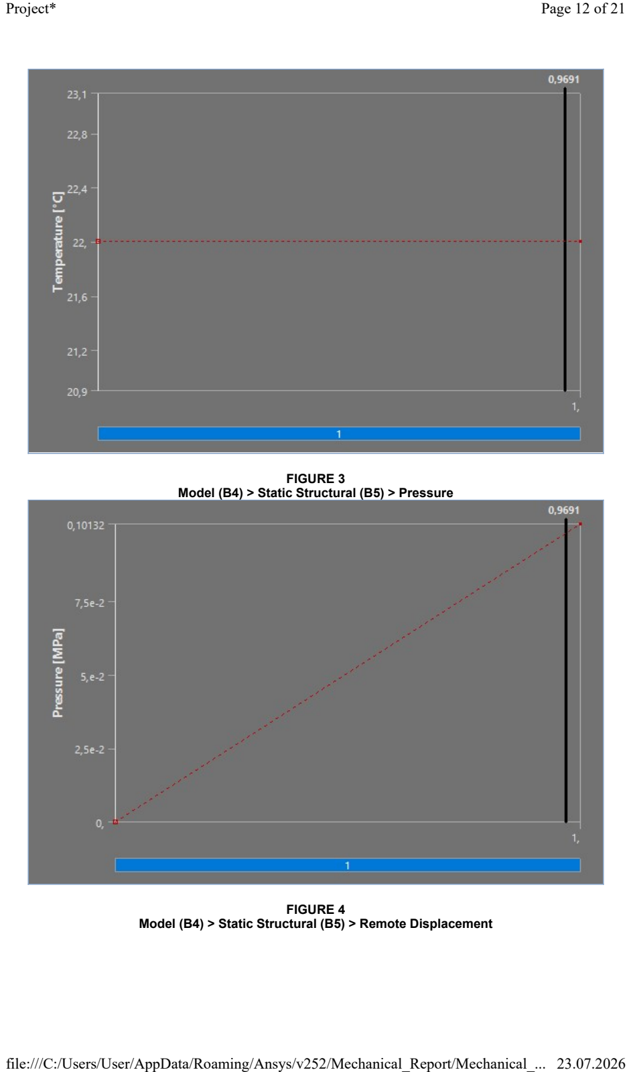
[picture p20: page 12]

FIGURE 3
Model (B4) > Static Structural (B5) > Pressure

FIGURE 4
Model (B4) > Static Structural (B5) > Remote Displacement
Project* | Page 12 of 21

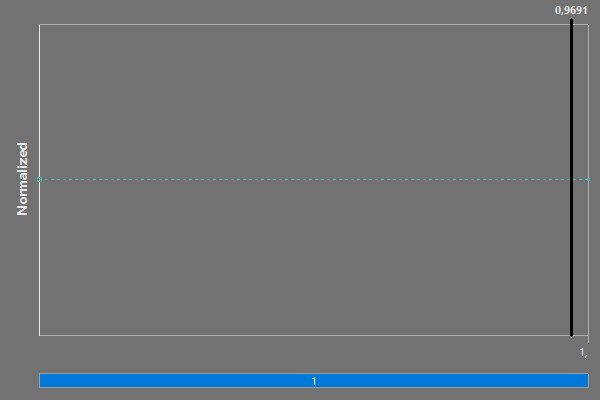
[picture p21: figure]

## Solution (B6)

TABLE 17
Model (B4) > Static Structural (B5) > Solution

TABLE 18
Model (B4) > Static Structural (B5) > Solution (B6) > Solution Information
Object Name | Solution (B6)
State | Solved
Adaptive Mesh Refinement
Max Refinement Loops | 1,
Refinement Depth | 2,
Information
Status | Done
MAPDL Elapsed Time | 11 m 3 s
MAPDL Memory Used | 5,4551 GB
MAPDL Result File Size | 461,5 MB
Post Processing
Beam Section Results | No
On Demand Stress/Strain | No
Object Name | Solution Information
State | Solved
Solution Information
Solution Output | Solver Output
Newton-Raphson Residuals | 0
Identify Element Violations | 5
Update Interval | 2,5 s
Display Points | All
FE Connection Visibility
Activate Visibility | Yes
Display | All FE Connectors
Draw Connections Attached To | All Nodes
Project* | Page 13 of 21

TABLE 19
Model (B4) > Static Structural (B5) > Solution (B6) > Results

FIGURE 5
Model (B4) > Static Structural (B5) > Solution (B6) > Total Deformation
Line Color | Connection Type
Visible on Results | No
Line Thickness | Single
Display Type | Lines
Object Name | Total Deformation | Equivalent Stress | Equivalent Stress 2
State | Solved
Scope
Scoping Method | Geometry Selection
Geometry | All Bodies | 148 Faces
Definition
Type | Total Deformation | Equivalent (von-Mises) Stress
By | Time
Display Time | Last
Separate Data by Entity | No
Calculate Time History | Yes
Identifier
Suppressed | No
Results
Minimum | 2,3121e-005 mm | 3,5258e-003 MPa
Maximum | 5,2585e-002 mm | 17,297 MPa | 4,6726 MPa
Average | 2,0714e-002 mm | 0,95557 MPa | 0,87365 MPa
Minimum Occurs On | Втулка\Solid | SYS-1\Твердое тело
Maximum Occurs On | SYS-1\Твердое тело | Втулка\Solid | SYS-1\Твердое тело
Minimum Value Over Time
Minimum | 1,623e-006 mm | 7,0064e-005 MPa
Maximum | 2,3121e-005 mm | 3,5258e-003 MPa
Maximum Value Over Time
Minimum | 1,4904e-003 mm | 2,1789 MPa | 0,24052 MPa
Maximum | 5,2585e-002 mm | 17,297 MPa | 4,6726 MPa
Information
Time | 1, s
Load Step | 1
Substep | 12
Iteration Number | 26
Integration Point Results
Display Option | Averaged
Average Across Bodies | No
Project* | Page 14 of 21

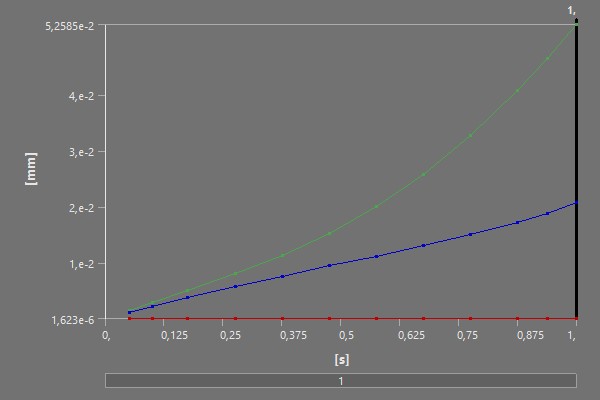
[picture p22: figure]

TABLE 20
Model (B4) > Static Structural (B5) > Solution (B6) > Total Deformation

FIGURE 6
Model (B4) > Static Structural (B5) > Solution (B6) > Equivalent Stress
Time [s] | Minimum [mm] | Maximum [mm] | Average [mm]
5,e-002 | 1,623e-006 | 1,4904e-003 | 1,1308e-003
0,1 | 4,0104e-006 | 2,9123e-003 | 2,2199e-003
0,175 | 6,9682e-006 | 5,0007e-003 | 3,7812e-003
0,275 | 9,7892e-006 | 7,9918e-003 | 5,7464e-003
0,375 | 1,1996e-005 | 1,1264e-002 | 7,6029e-003
0,475 | 1,3124e-005 | 1,521e-002 | 9,394e-003
0,575 | 1,2028e-005 | 2,0022e-002 | 1,1177e-002
0,675 | 7,9596e-006 | 2,5845e-002 | 1,3024e-002
0,775 | 4,3726e-006 | 3,2751e-002 | 1,5018e-002
0,875 | 8,4246e-006 | 4,0829e-002 | 1,7261e-002
0,9375 | 1,1812e-005 | 4,6442e-002 | 1,8778e-002
1, | 2,3121e-005 | 5,2585e-002 | 2,0714e-002
Project* | Page 15 of 21

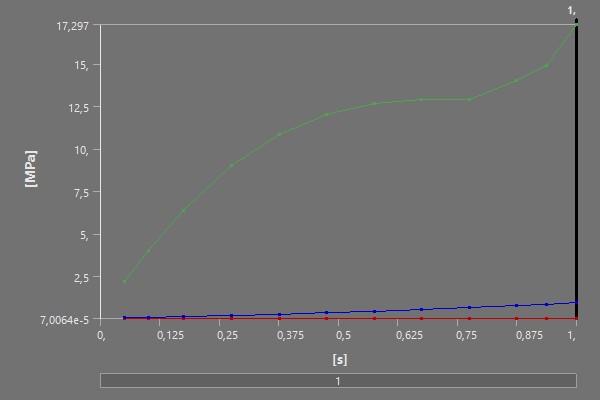
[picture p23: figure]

TABLE 21
Model (B4) > Static Structural (B5) > Solution (B6) > Equivalent Stress

FIGURE 7
Model (B4) > Static Structural (B5) > Solution (B6) > Equivalent Stress 2
Time [s] | Minimum [MPa] | Maximum [MPa] | Average [MPa]
5,e-002 | 7,0064e-005 | 2,1789 | 3,4574e-002
0,1 | 1,1576e-004 | 3,992 | 6,6908e-002
0,175 | 2,6434e-004 | 6,3787 | 0,11677
0,275 | 5,1849e-004 | 8,9832 | 0,18729
0,375 | 7,7865e-004 | 10,81 | 0,26143
0,475 | 9,3213e-004 | 11,983 | 0,3412
0,575 | 1,165e-003 | 12,628 | 0,42843
0,675 | 1,5183e-003 | 12,877 | 0,52506
0,775 | 2,0048e-003 | 12,898 | 0,6336
0,875 | 2,6166e-003 | 13,976 | 0,7582
0,9375 | 3,0588e-003 | 14,895 | 0,84144
1, | 3,5258e-003 | 17,297 | 0,95557
Project* | Page 16 of 21

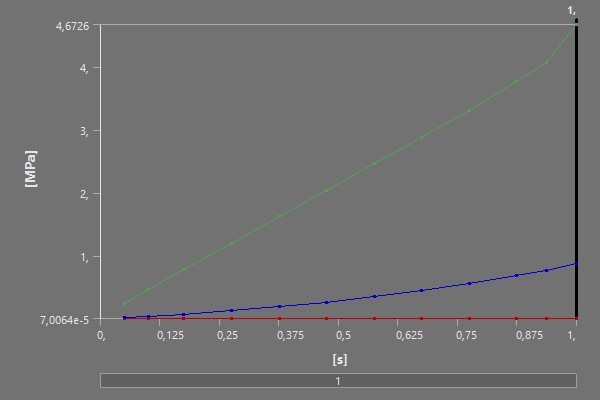
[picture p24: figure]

TABLE 22
Model (B4) > Static Structural (B5) > Solution (B6) > Equivalent Stress 2

TABLE 23
Model (B4) > Static Structural (B5) > Solution (B6) > Stress Safety Tools

TABLE 24
Model (B4) > Static Structural (B5) > Solution (B6) > Stress Tool > Results
Time [s] | Minimum [MPa] | Maximum [MPa] | Average [MPa]
5,e-002 | 7,0064e-005 | 0,24052 | 1,8217e-002
0,1 | 1,1576e-004 | 0,45359 | 3,6973e-002
0,175 | 2,6434e-004 | 0,77406 | 6,9157e-002
0,275 | 5,1849e-004 | 1,198 | 0,12101
0,375 | 7,7865e-004 | 1,622 | 0,18315
0,475 | 9,3213e-004 | 2,0399 | 0,25668
0,575 | 1,165e-003 | 2,4557 | 0,34245
0,675 | 1,5183e-003 | 2,8741 | 0,44132
0,775 | 2,0048e-003 | 3,3041 | 0,5543
0,875 | 2,6166e-003 | 3,7628 | 0,68304
0,9375 | 3,0588e-003 | 4,076 | 0,77039
1, | 3,5258e-003 | 4,6726 | 0,87365
Object Name | Stress Tool
State | Solved
Definition
Theory | Max Equivalent Stress
Stress Limit Type | Tensile Yield Per Material
Object Name | Safety Factor
State | Solved
Scope
Scoping Method | Geometry Selection
Geometry | All Bodies
Definition
Project* | Page 17 of 21

FIGURE 8
Model (B4) > Static Structural (B5) > Solution (B6) > Stress Tool > Safety Factor


TABLE 25
Model (B4) > Static Structural (B5) > Solution (B6) > Stress Tool > Safety Factor
Type | Safety Factor
By | Time
Display Time | Last
Separate Data by Entity | No
Calculate Time History | Yes
Identifier
Suppressed | No
Integration Point Results
Display Option | Averaged
Average Across Bodies | No
Results
Minimum | > 10
Minimum Occurs On | Втулка\Solid
Minimum Value Over Time
Minimum | 15,
Maximum | 15,
Maximum Value Over Time
Minimum | 15,
Maximum | 15,
Information
Time | 1, s
Load Step | 1
Substep | 12
Iteration Number | 26
Time [s] | Minimum | Maximum | Average
5,e-002
0,1
Project* | Page 18 of 21

TABLE 26
Model (B4) > Static Structural (B5) > Solution (B6) > Stress Safety Tools

TABLE 27
Model (B4) > Static Structural (B5) > Solution (B6) > Stress Tool 2 > Results

FIGURE 9
Model (B4) > Static Structural (B5) > Solution (B6) > Stress Tool 2 > Safety Factor

0,175

15, | 15, | 15,

0,275
0,375
0,475
0,575
0,675
0,775
0,875
0,9375
1,
Object Name | Stress Tool 2
State | Solved
Definition
Theory | Max Equivalent Stress
Stress Limit Type | Tensile Yield Per Material
Object Name | Safety Factor
State | Solved
Scope
Scoping Method | Geometry Selection
Geometry | 148 Faces
Definition
Type | Safety Factor
By | Time
Display Time | Last
Separate Data by Entity | No
Calculate Time History | Yes
Identifier
Suppressed | No
Integration Point Results
Display Option | Averaged
Average Across Bodies | No
Results
Minimum | > 10
Minimum Occurs On | SYS-1\Твердое тело
Minimum Value Over Time
Minimum | 15,
Maximum | 15,
Maximum Value Over Time
Minimum | 15,
Maximum | 15,
Information
Time | 1, s
Load Step | 1
Substep | 12
Iteration Number | 26
Project* | Page 19 of 21

TABLE 28
Model (B4) > Static Structural (B5) > Solution (B6) > Stress Tool 2 > Safety Factor

# Material Data

Time [s] | Minimum | Maximum | Average
5,e-002 | 15, | 15, | 15,
0,1
0,175
0,275
0,375
0,475
0,575
0,675
0,775
0,875
0,9375
1,

## Steel 40X Gost

TABLE 29
Steel 40X Gost > Constants

TABLE 30
Steel 40X Gost > Color

TABLE 31
Steel 40X Gost > Isotropic Elasticity
Density | 7,85e-006 kg mm^-3
Coefficient of Thermal Expansion | 1,2e-005 K^-1
Red | Green | Blue
181, | 155, | 130,
Project* | Page 20 of 21

TABLE 32
Steel 40X Gost > Tensile Yield Strength

TABLE 33
Steel 40X Gost > Compressive Yield Strength

TABLE 34
Steel 40X Gost > Tensile Ultimate Strength
Young's Modulus MPa | Poisson's Ratio | Bulk Modulus MPa | Shear Modulus MPa | Temperature K
2,e+005 | 0,3 | 1,6667e+005 | 76923

Tensile Yield Strength MPa 785,

Compressive Yield Strength MPa 785,

Tensile Ultimate Strength MPa 980,

## PA12-CF10

TABLE 35
PA12-CF10 > Constants

TABLE 36
PA12-CF10 > Color

TABLE 37
PA12-CF10 > Isotropic Elasticity

TABLE 38
PA12-CF10 > Tensile Yield Strength

TABLE 39
PA12-CF10 > Compressive Ultimate Strength
Density | 1,04e-006 kg mm^-3
Coefficient of Thermal Expansion | 7,e-005 K^-1
Red | Green | Blue
235, | 222, | 222,
Young's Modulus MPa | Poisson's Ratio | Bulk Modulus MPa | Shear Modulus MPa | Temperature K
3311, | 0,38 | 4598,6 | 1199,6

Tensile Yield Strength MPa 77,4

Compressive Ultimate Strength MPa 90,

Project* | Page 21 of 21

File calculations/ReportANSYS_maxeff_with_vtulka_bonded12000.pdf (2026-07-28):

# Project*


First Saved | Monday, July 20, 2026
Last Saved | Wednesday, July 22, 2026
Product Version | 2025 R2
Save Project Before Solution | No
Save Project After Solution | No
Project* | Page 1 of 20

file:///C:/Users/User/AppData/Roaming/Ansys/v252/Mechanical_Report/Mechanical_... 23.07.2026

# Contents

l Units

l Model (B4)
¡ Geometry Imports
n Geometry Import (B3)
¡ Geometry
n Parts
¡ Materials
¡ Coordinate Systems
¡ Connections
n Contacts
n Bonded - SYS-1\Твердое тело To Втулка\Solid ¡ Mesh
n Face Sizing
¡ Static Structural (B5)
n Analysis Settings
n Rotational Velocity
n Loads
n Solution (B6)
n Solution Information
n Results
n Stress Tool
n Safety Factor
n Stress Tool 2
n Safety Factor

l Material Data
¡ Steel 40X Gost
¡ PA12-CF10

# Units

TABLE 1

# Model (B4)

TABLE 2
Model (B4) > Geometry Imports

TABLE 3
Model (B4) > Geometry Imports > Geometry Import (B3)
Unit System | Metric (mm, kg, N, s, mV, mA) Degrees rad/s Celsius
Angle | Degrees
Rotational Velocity | rad/s
Temperature | Celsius
Object Name | Geometry Imports
State | Solved
Object Name | Geometry Import (B3)
State | Solved
Definition
Source | C:\Users\User\Desktop\Прочностные характеристики\All_work_files\dp0 \SYS-1\DM\SYS-1.scdocx
Project* | Page 2 of 20

Type | SpaceClaim Basic Geometry Options
Solid Bodies | Yes
Surface Bodies | Yes
Line Bodies | Yes
Parameters | Independent
Parameter Key
Attributes | Yes
Attribute Key
Named Selections | Yes
Named Selection Key
Material Properties | Yes
Advanced Geometry Options
Use Associativity | Yes
Coordinate Systems | Yes
Coordinate System Key
Reader Mode Saves Updated File | No
Use Instances | Yes
Smart CAD Update | Yes
Compare Parts On Update | No
Analysis Type | 3-D
Mixed Import Resolution | None
Import Facet Quality | Source
Clean Bodies On Import | No
Stitch Surfaces On Import | None
Decompose Disjoint Geometry | Yes
Enclosure and Symmetry Processing | Yes

## Geometry

TABLE 4
Model (B4) > Geometry
Object Name | Geometry
State | Fully Defined
Definition
Source | C:\Users\User\Desktop\Прочностные характеристики\All_work_files\dp0\SYS-1\DM\SYS-1.scdocx
Type | SpaceClaim
Length Unit | Meters
Element Control | Program Controlled
Display Style | Body Color
Bounding Box
Length X | 200, mm
Length Y | 200, mm
Length Z | 50,512 mm
Properties
Volume | 6,9256e+005 mm³
Mass | 0,8257 kg
Scale Factor Value | 1,
Statistics
Bodies | 2
Active Bodies | 2
Nodes | 127233
Elements | 70153
Project* | Page 3 of 20

TABLE 5
Model (B4) > Geometry > Parts
Mesh Metric | None
Update Options
Assign Default Material | No
Basic Geometry Options
Solid Bodies | Yes
Surface Bodies | Yes
Line Bodies | Yes
Parameters | Independent
Parameter Key
Attributes | Yes
Attribute Key
Named Selections | Yes
Named Selection Key
Material Properties | Yes
Advanced Geometry Options
Use Associativity | Yes
Coordinate Systems | Yes
Coordinate System Key
Reader Mode Saves Updated File | No
Use Instances | Yes
Smart CAD Update | Yes
Compare Parts On Update | No
Analysis Type | 3-D
Mixed Import Resolution | None
Import Facet Quality | Source
Clean Bodies On Import | No
Stitch Surfaces On Import | None
Decompose Disjoint Geometry | Yes
ID_GeometryPrefProcessPhysicsDefinition | No
Enclosure and Symmetry Processing | Yes
Object Name | Втулка\Solid | SYS-1\Твердое тело
State | Meshed
Graphics Properties
Visible | Yes
Transparency | 1
Definition
Suppressed | No
Stiffness Behavior | Flexible
Coordinate System | Default Coordinate System
Reference Temperature | By Environment
Treatment | None
Material
Assignment | Steel 40X Gost | PA12-CF10
Nonlinear Effects | Yes
Thermal Strain Effects | Yes
Bounding Box
Length X | 30,04 mm | 200, mm
Length Y | 30,04 mm | 200, mm
Length Z | 49,5 mm | 50,512 mm
Properties
Volume | 15483 mm³ | 6,7708e+005 mm³
Mass | 0,12154 kg | 0,70416 kg
Centroid X | -1,0201e-015 mm | -3,1788e-004 mm
Project* | Page 4 of 20

TABLE 6
Model (B4) > Materials
Centroid Y | -0,61774 mm | -1,5158e-005 mm
Centroid Z | 21,75 mm | 12,6 mm
Moment of Inertia Ip1 | 34,891 kg·mm² | 1322,2 kg·mm²
Moment of Inertia Ip2 | 35,835 kg·mm² | 1322,2 kg·mm²
Moment of Inertia Ip3 | 21,119 kg·mm² | 2449,5 kg·mm²
Statistics
Nodes | 4113 | 123120
Elements | 731 | 69422
Mesh Metric | None
CAD Attributes
PartTolerance: | 0,00000001
Color:143.149.175
SCRootPartComponent
Object Name | Materials
State | Fully Defined
Statistics
Materials | 4
Material Assignments | 0

## Coordinate Systems

TABLE 7
Model (B4) > Coordinate Systems > Coordinate System
Object Name | Global Coordinate System
State | Fully Defined
Definition
Type | Cartesian
Coordinate System ID | 0,
Origin
Origin X | 0, mm
Origin Y | 0, mm
Origin Z | 0, mm
Directional Vectors
X Axis Data | [ 1, 0, 0, ]
Y Axis Data | [ 0, 1, 0, ]
Z Axis Data | [ 0, 0, 1, ]
Transfer Properties
Source
Read Only | No

## Connections

TABLE 8
Model (B4) > Connections
Object Name | Connections
State | Fully Defined
Auto Detection
Generate Automatic Connection On Refresh Yes Transparency
Enabled Yes
Statistics
Contacts | 1
Active Contacts | 1
Project* | Page 5 of 20

TABLE 9
Model (B4) > Connections > Contacts

TABLE 10
Model (B4) > Connections > Contacts > Contact Regions
Joints | 0
Active Joints | 0
Beams | 0
Active Beams | 0
Bearings | 0
Active Bearings | 0
Springs | 0
Active Springs | 0
Body Interactions | 0
Active Body Interactions | 0
Object Name | Contacts
State | Fully Defined
Definition
Connection Type Contact
Scope
Scoping Method | Geometry Selection
Geometry | All Bodies
Auto Detection
Tolerance Type | Slider
Tolerance Slider | 0,
Tolerance Value | 0,71829 mm
Use Range | No
Face/Face | Yes
Face-Face Angle Tolerance | 75, °
Face Overlap Tolerance | Off
Cylindrical Faces | Include
Face/Edge | No
Edge/Edge | No
Priority | Include All
Group By | Bodies
Search Across | Bodies
Statistics
Connections | 1
Active Connections | 1
Object Name | Bonded - SYS-1\Твердое тело To Втулка\Solid
State | Fully Defined
Scope
Scoping Method | Geometry Selection
Contact | 2 Faces
Target | 1 Face
Contact Bodies | SYS-1\Твердое тело
Target Bodies | Втулка\Solid
Protected | No
Definition
Type | Bonded
Scope Mode | Manual
Behavior | Program Controlled
Trim Contact | Off
Contact APDL Name
Target APDL Name
Project* | Page 6 of 20

Suppressed | No
Display
Element Normals | No
Advanced
Formulation | Program Controlled
Small Sliding | Program Controlled
Detection Method | Program Controlled
Penetration Tolerance | Program Controlled
Elastic Slip Tolerance | Program Controlled
Normal Stiffness | Program Controlled
Update Stiffness | Program Controlled
Pinball Region | Program Controlled
Geometric Modification
Contact Geometry Correction | None
Target Geometry Correction | None

## Mesh

TABLE 11
Model (B4) > Mesh
Object Name | Mesh
State | Solved
Display
Display Style Use Geometry Setting Defaults
Physics Preference | Mechanical
Element Order | Program Controlled
Element Size | 3,615 mm
Sizing
Use Adaptive Sizing | Yes
Resolution | Default (2)
Mesh Defeaturing | Yes
Defeature Size | Default
Transition | Fast
Span Angle Center | Coarse
Initial Size Seed | Assembly
Bounding Box Diagonal | 287,32 mm
Average Surface Area | 833,96 mm²
Minimum Edge Length | 2,3673e-004 mm
Quality
Check Mesh Quality | Yes, Errors
Error Limits | Aggressive Mechanical
Target Element Quality | Default (5,e-002)
Smoothing | Medium
Mesh Metric | None
Inflation
Use Automatic Inflation | None
Inflation Option | Smooth Transition
Transition Ratio | 0,272
Maximum Layers | 5
Growth Rate | 1,2
Inflation Algorithm | Pre
Inflation Element Type | Wedges
View Advanced Options | No
Advanced
Number of CPUs for Parallel Part Meshing | Program Controlled
Project* | Page 7 of 20

TABLE 12
Model (B4) > Mesh > Mesh Controls

# Static Structural (B5)

TABLE 13
Model (B4) > Analysis

TABLE 14
Model (B4) > Static Structural (B5) > Analysis Settings
Straight Sided Elements | No
Rigid Body Behavior | Dimensionally Reduced
Triangle Surface Mesher | Program Controlled
Topology Checking | Yes
Pinch Tolerance | Please Define
Generate Pinch on Refresh | No
Auto-Map Fillets | No
Automatic Methods
Sheet Body Method | Prime Quad Dominant
Sweepable Body Method | Sweep
Statistics
Nodes | 127233
Elements | 70153
Show Detailed Statistics | No
Object Name | Face Sizing
State | Fully Defined
Scope
Scoping Method | Geometry Selection
Geometry | 60 Faces
Definition
Suppressed | No
Type | Element Size
Element Size | 2,52 mm
Advanced
Defeature Size | Default
Influence Volume | No
Behavior | Soft
Object Name | Static Structural (B5)
State | Solved
Definition
Physics Type | Structural
Analysis Type | Static Structural
Solver Target | Mechanical APDL
Options
Environment Temperature | 22, °C
Generate Input Only | No
Object Name | Analysis Settings
State | Fully Defined
Step Controls
Number Of Steps | 1,
Current Step Number | 1,
Step End Time | 1, s
Auto Time Stepping | On
Define By | Substeps
Initial Substeps | 20,
Project* | Page 8 of 20

Minimum Substeps | 10,
Maximum Substeps | 100,
Solver Controls
Solver Type | Program Controlled
Weak Springs | Program Controlled
Solver Pivot Checking | Program Controlled
Large Deflection | On
Inertia Relief | Off
Quasi-Static Solution | On
Rotordynamics Controls
Coriolis Effect | Off
Restart Controls
Generate Restart Points | Program Controlled
Retain Files After Full Solve | No
Combine Restart Files | Program Controlled
Nonlinear Controls
Newton-Raphson Option | Program Controlled
Force Convergence | Program Controlled
Moment Convergence | Program Controlled
Displacement Convergence | Program Controlled
Rotation Convergence | Program Controlled
Line Search | Program Controlled
Stabilization | Constant
--Method | Energy
--Energy Dissipation Ratio | 1,e-004
--Activation For First Substep | No
--Stabilization Force Limit | 0,2
Advanced
Inverse Option | No
Contact Split (DMP) | Program Controlled
Output Controls
Output Selection | None
Stress | Yes
Back Stress | No
Strain | Yes
Contact Data | Yes
Nonlinear Data | No
Nodal Forces | No
Volume and Energy | Yes
Euler Angles | Yes
General Miscellaneous | No
Contact Miscellaneous | No
Store Results At | All Time Points
Result File Compression | Program Controlled
Analysis Data Management
Solver Files Directory | C:\Users\User\Desktop\Прочностные характеристики\All_work_files\dp0\SYS-1\MECH\
Future Analysis | None
Scratch Solver Files Directory
Save MAPDL db | No
Contact Summary | Program Controlled
Delete Unneeded Files | Yes
Nonlinear Solution | Yes
Project* | Page 9 of 20

TABLE 15
Model (B4) > Static Structural (B5) > Rotations

FIGURE 1
Model (B4) > Static Structural (B5) > Rotational Velocity


TABLE 16
Model (B4) > Static Structural (B5) > Loads
Solver Units | Active System
Solver Unit System | nmm
Object Name | Rotational Velocity
State | Fully Defined
Scope
Scoping Method | Geometry Selection
Geometry | All Bodies
Definition
Define By | Components
Coordinate System | Global Coordinate System
X Component | 0, rad/s (ramped)
Y Component | 0, rad/s (ramped)
Z Component | -1256,6 rad/s (ramped)
X Coordinate | 0,5 mm
Y Coordinate | -0,61961 mm
Z Coordinate | 46,5 mm
Suppressed | No
Object Name | Condition Thermal | Pressure | Cylindrical Support | Remote Displacement
State | Fully Defined | | Suppressed | Fully Defined
Scope
Scoping Method | Geometry Selection
Geometry | 2 Bodies | 60 Faces | 1 Face
Coordinate System | | Global Coordinate System
Project* | Page 10 of 20

FIGURE 2
Model (B4) > Static Structural (B5) > Thermal Condition


FIGURE 3
Model (B4) > Static Structural (B5) > Pressure
X Coordinate | 2,7818e-016 mm
Y Coordinate | 2,6427e-016 mm
Z Coordinate | 21,75 mm
Location | Defined
Definition
Type | Condition Thermal | Pressure | Cylindrical Support | Remote Displacement
Magnitude | 75, °C (ramped) | 0,10132 MPa (ramped)
Suppressed | No | | Yes | No
Define By | | Normal To
Applied By | | Surface Effect
Loaded Area | | Deformed
Radial | | | Fixed
Axial | | | Fixed
Tangential | | | Fixed
X Component | | | | 0, mm (ramped)
Y Component | | | | 0, mm (ramped)
Z Component | | | | 0, mm (ramped)
Rotation X | | | | 0, ° (ramped)
Rotation Y | | | | 0, ° (ramped)
Rotation Z | | | | 0, ° (ramped)
Behavior | | | | Deformable
Advanced
Pinball Region | All
Project* | Page 11 of 20


FIGURE 4
Model (B4) > Static Structural (B5) > Remote Displacement

## Solution (B6)

TABLE 17
Model (B4) > Static Structural (B5) > Solution
Object Name | Solution (B6)
State | Solved
Project* | Page 12 of 20

TABLE 18
Model (B4) > Static Structural (B5) > Solution (B6) > Solution Information

TABLE 19
Model (B4) > Static Structural (B5) > Solution (B6) > Results

Adaptive Mesh Refinement
Max Refinement Loops | 1,
Refinement Depth | 2,
Information
Status | Done
MAPDL Elapsed Time | 48 m 7 s
MAPDL Memory Used | 5,3555 GB
MAPDL Result File Size | 516,75 MB
Post Processing
Beam Section Results | No
On Demand Stress/Strain | No
Object Name | Solution Information
State | Solved
Solution Information
Solution Output | Solver Output
Newton-Raphson Residuals | 0
Identify Element Violations | 5
Update Interval | 2,5 s
Display Points | All
FE Connection Visibility
Activate Visibility | Yes
Display | All FE Connectors
Draw Connections Attached To | All Nodes
Line Color | Connection Type
Visible on Results | No
Line Thickness | Single
Display Type | Lines
Object Name | Total Deformation | Equivalent Stress | Equivalent Stress 2
State | Solved
Scope
Scoping Method | Geometry Selection
Geometry | All Bodies | 148 Faces
Definition
Type | Total Deformation | Equivalent (von-Mises) Stress
By | Time
Display Time | Last
Separate Data by Entity | No
Calculate Time History | Yes
Identifier
Suppressed | No
Results
Minimum | 6,0788e-003 mm | 2,378e-002 MPa
Maximum | 0,73563 mm | 149,84 MPa | 11,604 MPa
Average | 0,30514 mm | 3,3955 MPa | 2,7255 MPa
Minimum Occurs On | Втулка\Solid | SYS-1\Твердое тело
Maximum Occurs On | SYS-1\Твердое тело | Втулка\Solid | SYS-1\Твердое тело
Minimum Value Over Time
Minimum | 3,6331e-004 mm | 3,9814e-005 MPa
Maximum | 6,0788e-003 mm | 2,378e-002 MPa
Maximum Value Over Time
Project* | Page 13 of 20

FIGURE 5
Model (B4) > Static Structural (B5) > Solution (B6) > Total Deformation


TABLE 20
Model (B4) > Static Structural (B5) > Solution (B6) > Total Deformation

FIGURE 6
Model (B4) > Static Structural (B5) > Solution (B6) > Equivalent Stress
Minimum | 1,8919e-002 mm | 6,0304 MPa | 1,1359 MPa
Maximum | 0,73563 mm | 149,84 MPa | 11,604 MPa
| Information
Time | 1, s
Load Step | 1
Substep | 12
Iteration Number | 23
Integration Point Results
Display Option | Averaged
Average Across Bodies | No
Time [s] | Minimum [mm] | Maximum [mm] | Average [mm]
5,e-002 | 3,6331e-004 | 1,8919e-002 | 1,1376e-002
0,1 | 7,2324e-004 | 3,837e-002 | 2,2908e-002
0,175 | 1,2563e-003 | 6,9285e-002 | 4,0553e-002
0,275 | 1,9536e-003 | 0,11392 | 6,4846e-002
0,375 | 2,6338e-003 | 0,1638 | 9,026e-002
0,475 | 3,2952e-003 | 0,22074 | 0,11715
0,575 | 3,9354e-003 | 0,28721 | 0,14604
0,675 | 4,5087e-003 | 0,36671 | 0,17766
0,775 | 5,0383e-003 | 0,46424 | 0,21315
0,875 | 5,5126e-003 | 0,58729 | 0,25425
0,9375 | 5,7965e-003 | 0,66591 | 0,28057
1, | 6,0788e-003 | 0,73563 | 0,30514
Project* | Page 14 of 20


TABLE 21
Model (B4) > Static Structural (B5) > Solution (B6) > Equivalent Stress

FIGURE 7
Model (B4) > Static Structural (B5) > Solution (B6) > Equivalent Stress 2
Time [s] | Minimum [MPa] | Maximum [MPa] | Average [MPa]
5,e-002 | 3,9814e-005 | 6,0304 | 0,10376
0,1 | 9,1428e-005 | 11,7 | 0,20626
0,175 | 4,5784e-004 | 19,503 | 0,36564
0,275 | 7,0309e-004 | 30,056 | 0,59598
0,375 | 2,1268e-003 | 41,604 | 0,85311
0,475 | 3,4545e-003 | 53,513 | 1,1417
0,575 | 7,0261e-003 | 66,04 | 1,4661
0,675 | 1,0395e-002 | 80,188 | 1,8301
0,775 | 1,4446e-002 | 95,215 | 2,2375
0,875 | 1,854e-002 | 112,61 | 2,6912
0,9375 | 1,9395e-002 | 129,99 | 3,0215
1, | 2,378e-002 | 149,84 | 3,3955
Project* | Page 15 of 20


TABLE 22
Model (B4) > Static Structural (B5) > Solution (B6) > Equivalent Stress 2

TABLE 23
Model (B4) > Static Structural (B5) > Solution (B6) > Stress Safety Tools

TABLE 24
Model (B4) > Static Structural (B5) > Solution (B6) > Stress Tool > Results
Time [s] | Minimum [MPa] | Maximum [MPa] | Average [MPa]
5,e-002 | 3,9814e-005 | 1,1359 | 5,2525e-002
0,1 | 9,1428e-005 | 2,2054 | 0,10766
0,175 | 4,5784e-004 | 3,6826 | 0,20396
0,275 | 7,0309e-004 | 5,4202 | 0,36122
0,375 | 2,1268e-003 | 6,9065 | 0,5559
0,475 | 3,4545e-003 | 8,1229 | 0,7899
0,575 | 7,0261e-003 | 9,0711 | 1,0642
0,675 | 1,0395e-002 | 9,7611 | 1,3795
0,775 | 1,4446e-002 | 10,191 | 1,736
0,875 | 1,854e-002 | 10,379 | 2,1338
0,9375 | 1,9395e-002 | 10,796 | 2,4145
1, | 2,378e-002 | 11,604 | 2,7255
Object Name | Stress Tool
State | Solved
Definition
Theory | Max Equivalent Stress
Stress Limit Type | Tensile Yield Per Material
Object Name | Safety Factor
State | Solved
Scope
Scoping Method | Geometry Selection
Geometry | All Bodies
Definition
Project* | Page 16 of 20

FIGURE 8
Model (B4) > Static Structural (B5) > Solution (B6) > Stress Tool > Safety Factor


TABLE 25
Model (B4) > Static Structural (B5) > Solution (B6) > Stress Tool > Safety Factor
Type | Safety Factor
By | Time
Display Time | Last
Separate Data by Entity | No
Calculate Time History | Yes
Identifier
Suppressed | No
Integration Point Results
Display Option | Averaged
Average Across Bodies | No
Results
Minimum | 5,2388
Minimum Occurs On | Втулка\Solid
Minimum Value Over Time
Minimum | 5,2388
Maximum | 15,
Maximum Value Over Time
Minimum | 15,
Maximum | 15,
Information
Time | 1, s
Load Step | 1
Substep | 12
Iteration Number | 23
Time [s] | Minimum | Maximum | Average
5,e-002
0,1 | 15, | 15,
Project* | Page 17 of 20

TABLE 26
Model (B4) > Static Structural (B5) > Solution (B6) > Stress Safety Tools

TABLE 27
Model (B4) > Static Structural (B5) > Solution (B6) > Stress Tool 2 > Results

FIGURE 9
Model (B4) > Static Structural (B5) > Solution (B6) > Stress Tool 2 > Safety Factor

0,175

15,

0,275 | 14,28
0,375 | 11,207 | 14,986
0,475 | 9,5286 | 14,954
0,575 | 8,5326 | 14,925
0,675 | 7,9294 | 14,902
0,775 | 7,5949 | 14,883
0,875 | 6,9707 | 14,851
0,9375 | 6,0388 | 14,796
1, | 5,2388 | 14,704
Object Name | Stress Tool 2
State | Solved
Definition
Theory | Max Equivalent Stress
Stress Limit Type | Tensile Yield Per Material
Object Name | Safety Factor
State | Solved
Scope
Scoping Method | Geometry Selection
Geometry | 148 Faces
Definition
Type | Safety Factor
By | Time
Display Time | Last
Separate Data by Entity | No
Calculate Time History | Yes
Identifier
Suppressed | No
Integration Point Results
Display Option | Averaged
Average Across Bodies | No
Results
Minimum | 6,6699
Minimum Occurs On | SYS-1\Твердое тело
Minimum Value Over Time
Minimum | 6,6699
Maximum | 15,
Maximum Value Over Time
Minimum | 15,
Maximum | 15,
Information
Time | 1, s
Load Step | 1
Substep | 12
Iteration Number | 23
Project* | Page 18 of 20


TABLE 28
Model (B4) > Static Structural (B5) > Solution (B6) > Stress Tool 2 > Safety Factor

# Material Data

Time [s] | Minimum | Maximum | Average
5,e-002 | 15, | 15, | 15, 0,1

0,175
0,275 | 14,28
0,375 | 11,207 | 14,969
0,475 | 9,5286 | 14,917
0,575 | 8,5326 | 14,884
0,675 | 7,9294 | 14,863
0,775 | 7,5949 | 14,848
0,875 | 7,4577 | 14,807
0,9375 | 7,1692 | 14,718
1, | 6,6699 | 14,565

## Steel 40X Gost

TABLE 29
Steel 40X Gost > Constants

TABLE 30
Steel 40X Gost > Color

TABLE 31
Steel 40X Gost > Isotropic Elasticity
Density | 7,85e-006 kg mm^-3
Coefficient of Thermal Expansion | 1,2e-005 K^-1
Red | Green | Blue
181, | 155, | 130,
Project* | Page 19 of 20

TABLE 32
Steel 40X Gost > Tensile Yield Strength

TABLE 33
Steel 40X Gost > Compressive Yield Strength

TABLE 34
Steel 40X Gost > Tensile Ultimate Strength
Young's Modulus MPa | Poisson's Ratio | Bulk Modulus MPa | Shear Modulus MPa | Temperature K
2,e+005 | 0,3 | 1,6667e+005 | 76923

Tensile Yield Strength MPa 785,

Compressive Yield Strength MPa 785,

Tensile Ultimate Strength MPa 980,

## PA12-CF10

TABLE 35
PA12-CF10 > Constants

TABLE 36
PA12-CF10 > Color

TABLE 37
PA12-CF10 > Isotropic Elasticity

TABLE 38
PA12-CF10 > Tensile Yield Strength

TABLE 39
PA12-CF10 > Compressive Ultimate Strength
Density | 1,04e-006 kg mm^-3
Coefficient of Thermal Expansion | 7,e-005 K^-1
Red | Green | Blue
235, | 222, | 222,
Young's Modulus MPa | Poisson's Ratio | Bulk Modulus MPa | Shear Modulus MPa | Temperature K
3311, | 0,38 | 4598,6 | 1199,6 | 295,15
1500, | 0,4 | 2500, | 535,71 | 343,15

Tensile Yield Strength MPa 77,4

Compressive Ultimate Strength MPa 90,

Project* | Page 20 of 20

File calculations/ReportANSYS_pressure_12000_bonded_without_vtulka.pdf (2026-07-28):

# Project*


First Saved | Monday, July 20, 2026
Last Saved | Thursday, July 23, 2026
Product Version | 2025 R2
Save Project Before Solution | No
Save Project After Solution | No
Project* | Page 1 of 16

file:///C:/Users/User/AppData/Roaming/Ansys/v252/Mechanical_Report/Mechanical_... 24.07.2026

# Contents

l Units

l Model (B4)
¡ Geometry Imports
n Geometry Import (B3)
¡ Geometry
n max_pressure|Вырез-Вытянуть2 ¡ Materials
¡ Coordinate Systems
¡ Connections
¡ Mesh
n Face Sizing
¡ Named Selections
¡ Static Structural (B5)
n Analysis Settings
n Rotational Velocity
n Loads
n Solution (B6)
n Solution Information
n Results
n Stress Tool
n Safety Factor

l Material Data
¡ PA12-CF10

# Units

TABLE 1

# Model (B4)

TABLE 2
Model (B4) > Geometry Imports

TABLE 3
Model (B4) > Geometry Imports > Geometry Import (B3)
Unit System | Metric (mm, kg, N, s, mV, mA) Degrees rad/s Celsius
Angle | Degrees
Rotational Velocity | rad/s
Temperature | Celsius
Object Name | Geometry Imports
State | Solved
Object Name | Geometry Import (B3)
State | Solved
Definition
Source | C:\Users\User\Desktop\Прочностные характеристики\max_pressure\max_pressure.step
Type | Step
Basic Geometry Options
Solid Bodies | Yes
Surface Bodies | Yes
Project* | Page 2 of 16

Line Bodies | No
Parameters | Independent
Parameter Key | ANS;DS
Attributes | No
Named Selections | No
Material Properties | No
Advanced Geometry Options
Use Associativity | Yes
Coordinate Systems | No
Reader Mode Saves Updated File | No
Use Instances | Yes
Smart CAD Update | Yes
Compare Parts On Update | No
Analysis Type | 3-D
Mixed Import Resolution | None
Import Facet Quality | Source
Clean Bodies On Import | No
Stitch Surfaces On Import | None
Decompose Disjoint Geometry | Yes
Enclosure and Symmetry Processing | Yes

## Geometry

TABLE 4
Model (B4) > Geometry
Object Name | Geometry
State | Fully Defined
Definition
Source | C:\Users\User\Desktop\Прочностные характеристики\max_pressure\max_pressure.step
Type | Step
Length Unit | Millimeters
Element Control | Program Controlled
Display Style | Body Color
Bounding Box
Length X | 200, mm
Length Y | 200, mm
Length Z | 51,025 mm
Properties
Volume | 6,9549e+005 mm³
Mass | 0,72331 kg
Scale Factor Value | 1,
Statistics
Bodies | 1
Active Bodies | 1
Nodes | 127598
Elements | 72770
Mesh Metric | None
Update Options
Assign Default Material | No
Basic Geometry Options
Solid Bodies | Yes
Surface Bodies | Yes
Line Bodies | No
Project* | Page 3 of 16

TABLE 5
Model (B4) > Geometry > Parts
Parameters | Independent
Parameter Key | ANS;DS
Attributes | No
Named Selections | No
Material Properties | No
Advanced Geometry Options
Use Associativity | Yes
Coordinate Systems | No
Reader Mode Saves Updated File | No
Use Instances | Yes
Smart CAD Update | Yes
Compare Parts On Update | No
Analysis Type | 3-D
Mixed Import Resolution | None
Import Facet Quality | Source
Clean Bodies On Import | No
Stitch Surfaces On Import | None
Decompose Disjoint Geometry | Yes
ID_GeometryPrefProcessPhysicsDefinition | No
Enclosure and Symmetry Processing | Yes
Object Name | max_pressure|Вырез-Вытянуть2
State | Meshed
Graphics Properties
Visible | Yes
Transparency | 1
Definition
Suppressed | No
Stiffness Behavior | Flexible
Coordinate System | Default Coordinate System
Reference Temperature | By Environment
Treatment | None
Material
Assignment | PA12-CF10
Nonlinear Effects | Yes
Thermal Strain Effects | Yes
Bounding Box
Length X | 200, mm
Length Y | 200, mm
Length Z | 51,025 mm
Properties
Volume | 6,9549e+005 mm³
Mass | 0,72331 kg
Centroid X | -4,5014e-003 mm
Centroid Y | 9,8156e-004 mm
Centroid Z | 13,043 mm
Moment of Inertia Ip1 | 1361,4 kg·mm²
Moment of Inertia Ip2 | 1361, kg·mm²
Moment of Inertia Ip3 | 2513,2 kg·mm²
Statistics
Nodes | 127598
Elements | 72770
Mesh Metric | None
Project* | Page 4 of 16

TABLE 6
Model (B4) > Materials
Object Name | Materials
State | Fully Defined
Statistics
Materials | 4
Material Assignments | 0

## Coordinate Systems

TABLE 7
Model (B4) > Coordinate Systems > Coordinate System
Object Name | Global Coordinate System
State | Fully Defined
Definition
Type | Cartesian
Coordinate System ID | 0,
Origin
Origin X | 0, mm
Origin Y | 0, mm
Origin Z | 0, mm
Directional Vectors
X Axis Data | [ 1, 0, 0, ]
Y Axis Data | [ 0, 1, 0, ]
Z Axis Data | [ 0, 0, 1, ]
Transfer Properties
Source
Read Only | No

## Connections

TABLE 8
Model (B4) > Connections
Object Name | Connections
State | Fully Defined
Auto Detection
Generate Automatic Connection On Refresh Yes Transparency
Enabled Yes
Statistics
Contacts | 0
Active Contacts | 0
Joints | 0
Active Joints | 0
Beams | 0
Active Beams | 0
Bearings | 0
Active Bearings | 0
Springs | 0
Active Springs | 0
Body Interactions | 0
Active Body Interactions | 0

## Mesh

TABLE 9

Project* | Page 5 of 16

Model (B4) > Mesh

TABLE 10
Model (B4) > Mesh > Mesh Controls
Object Name | Mesh
State | Solved
Display
Display Style Use Geometry Setting Defaults
Physics Preference | Mechanical
Element Order | Program Controlled
Element Size | 3,39 mm
Sizing
Use Adaptive Sizing | Yes
Resolution | Default (2)
Mesh Defeaturing | Yes
Defeature Size | Default
Transition | Fast
Span Angle Center | Coarse
Initial Size Seed | Assembly
Bounding Box Diagonal | 287,41 mm
Average Surface Area | 531,5 mm²
Minimum Edge Length | 7,3636e-004 mm
Quality
Check Mesh Quality | Yes, Errors
Error Limits | Aggressive Mechanical
Target Element Quality | Default (5,e-002)
Smoothing | Medium
Mesh Metric | None
Inflation
Use Automatic Inflation | None
Inflation Option | Smooth Transition
Transition Ratio | 0,272
Maximum Layers | 5
Growth Rate | 1,2
Inflation Algorithm | Pre
Inflation Element Type | Wedges
View Advanced Options | No
Advanced
Number of CPUs for Parallel Part Meshing | Program Controlled
Straight Sided Elements | No
Rigid Body Behavior | Dimensionally Reduced
Triangle Surface Mesher | Program Controlled
Topology Checking | Yes
Pinch Tolerance | Please Define
Generate Pinch on Refresh | No
Auto-Map Fillets | No
Automatic Methods
Sheet Body Method | Prime Quad Dominant
Sweepable Body Method | Sweep
Statistics
Nodes | 127598
Elements | 72770
Show Detailed Statistics | No
Object Name | Face Sizing
State | Fully Defined
Scope
Project* | Page 6 of 16

Scoping Method | Geometry Selection
Geometry | 78 Faces
Definition
Suppressed | No
Type | Element Size
Element Size | 2,8 mm
Advanced
Defeature Size | Default
Influence Volume | No
Behavior | Soft

## Named Selections
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

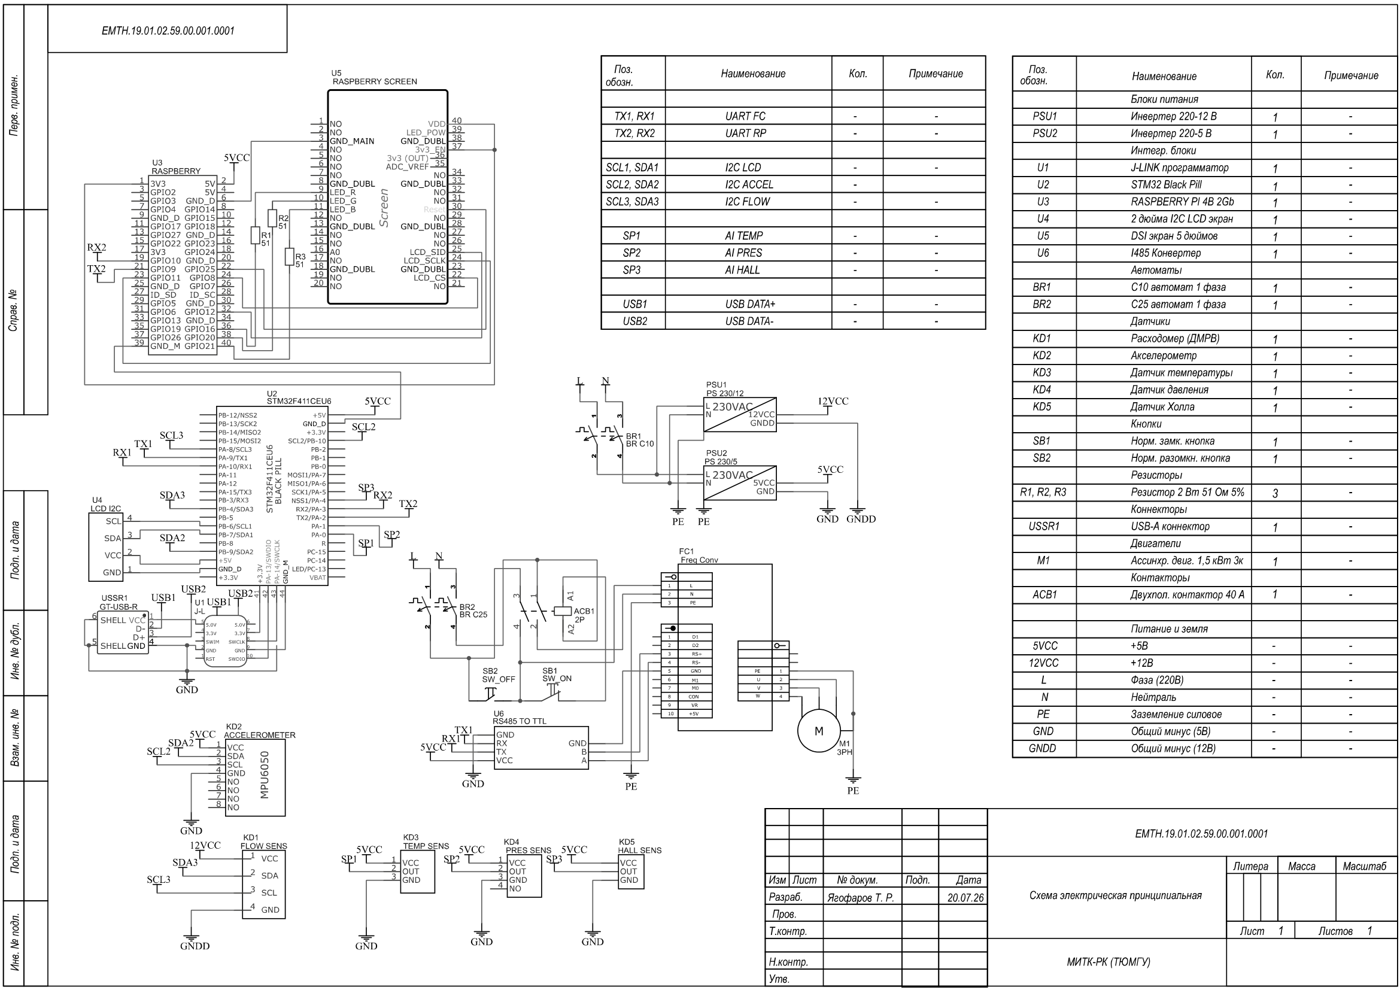
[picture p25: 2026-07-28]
assets/stand/electrical-schematic.png

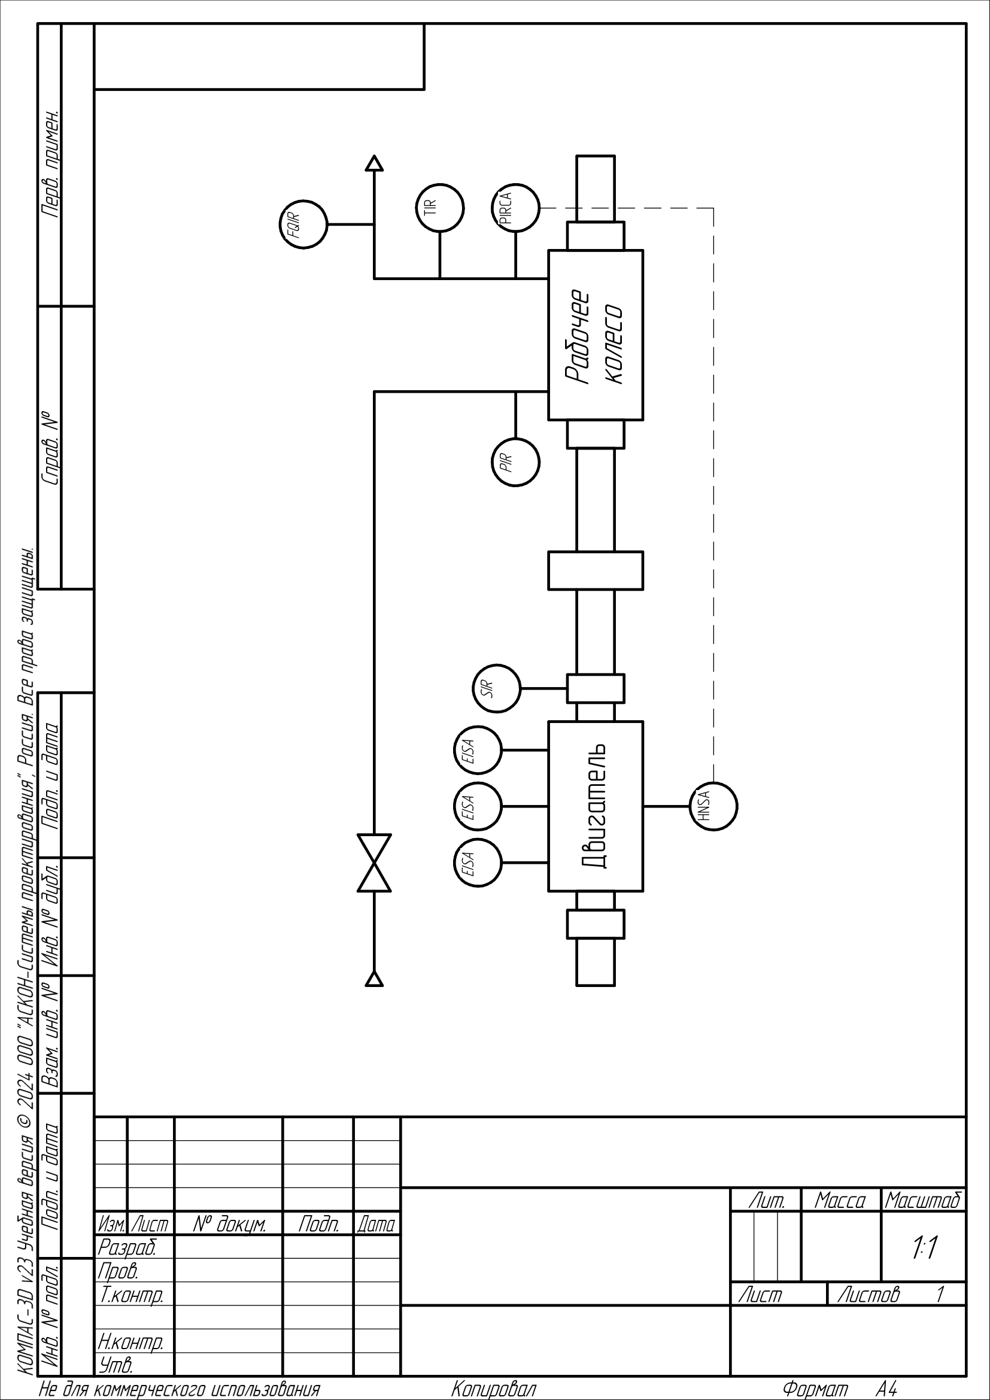
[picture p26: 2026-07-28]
assets/stand/functional-schematic.png

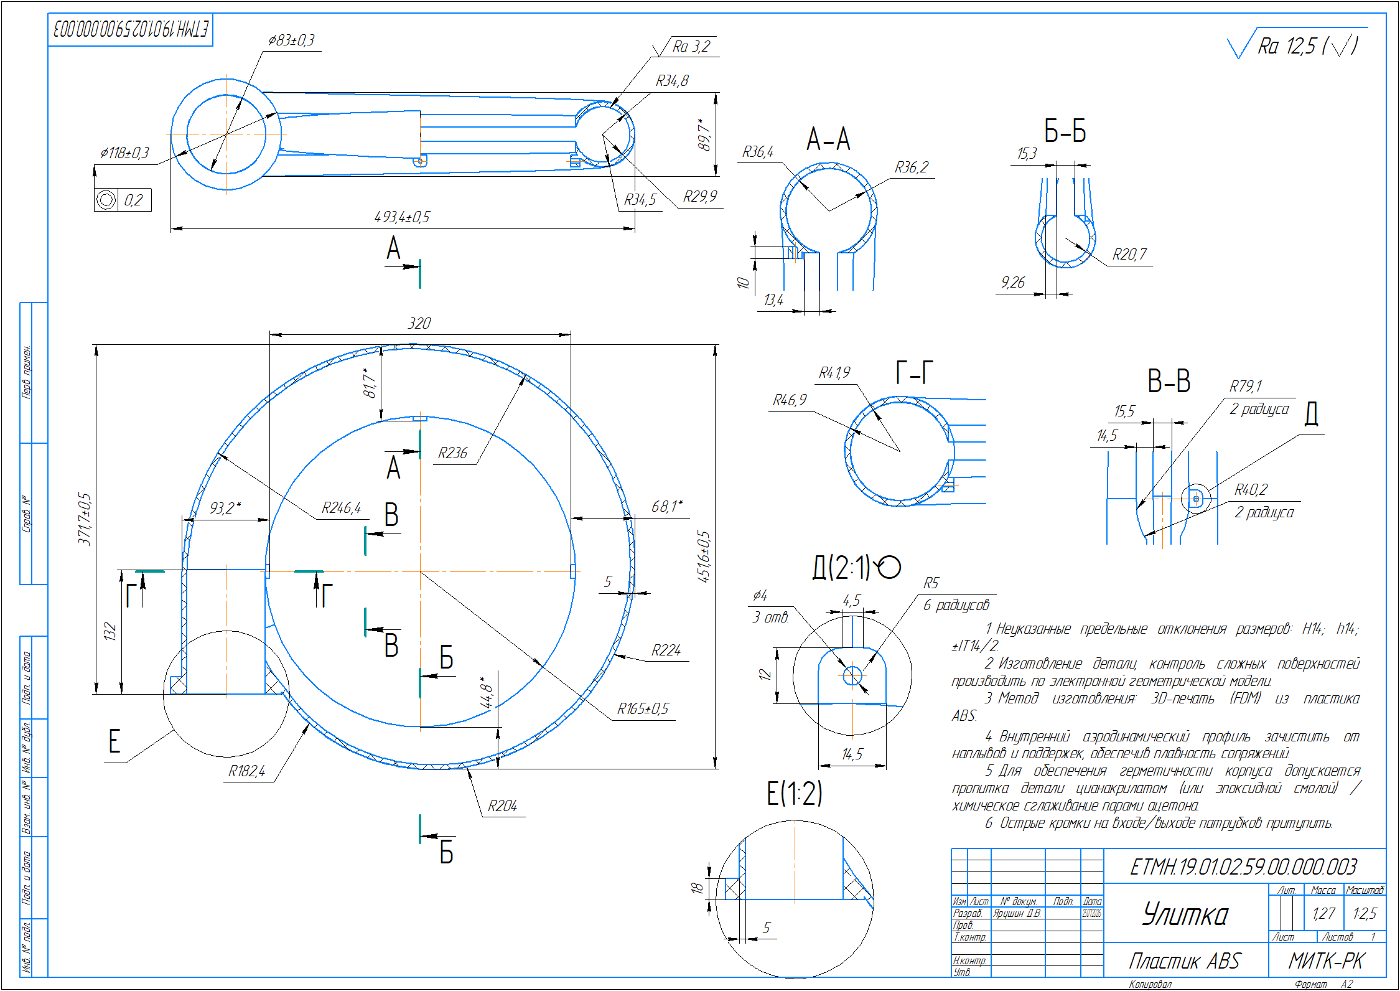
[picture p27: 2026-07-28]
assets/drawing-previews/cdw-volute.png

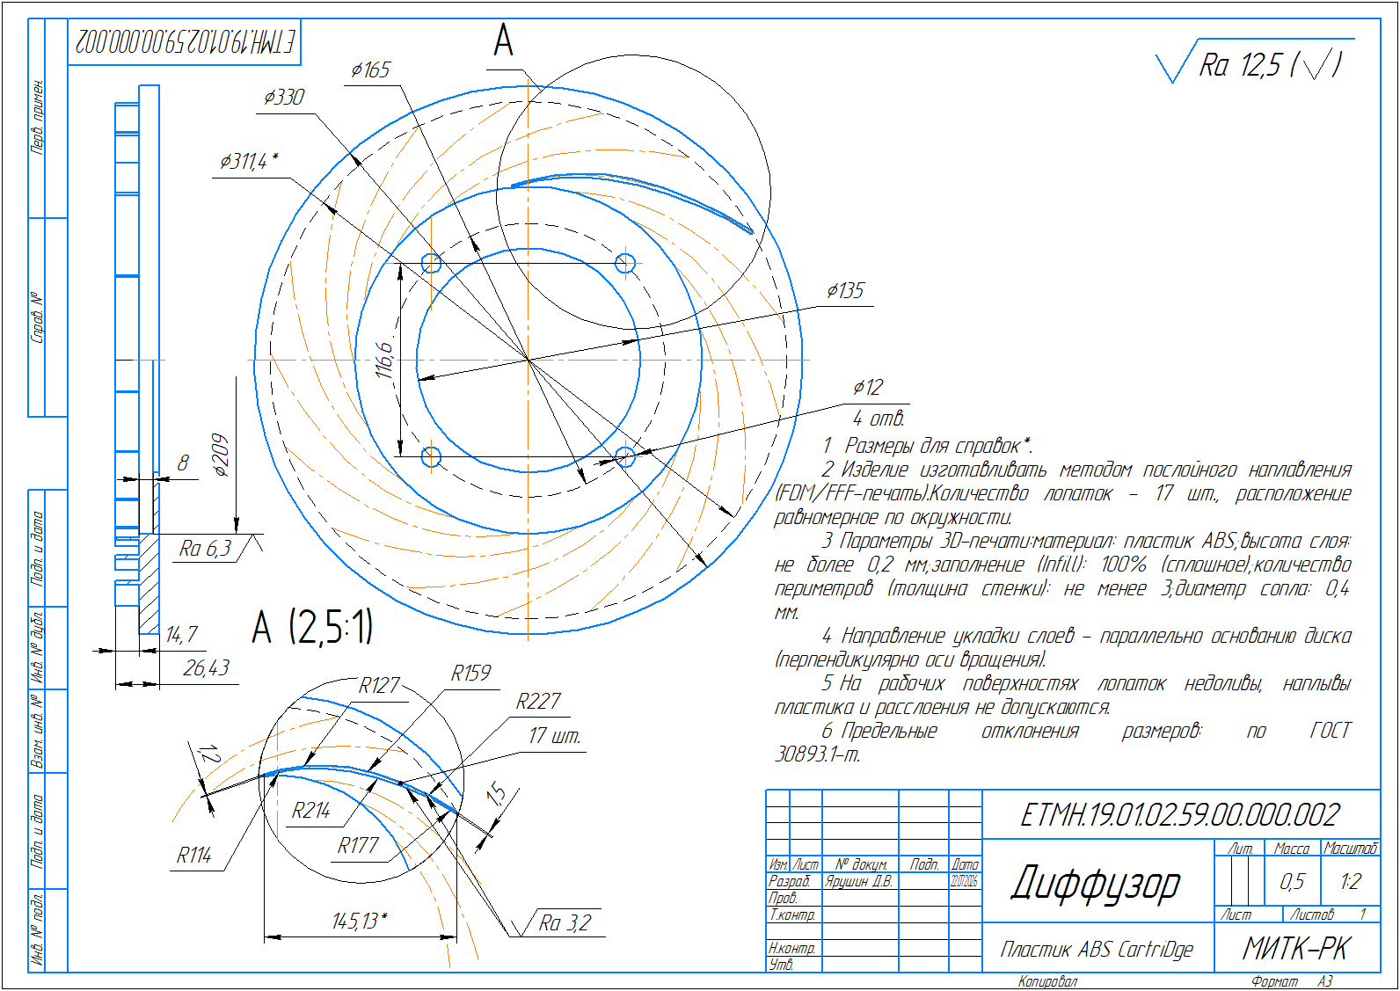
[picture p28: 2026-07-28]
assets/drawing-previews/cdw-diffuser.png

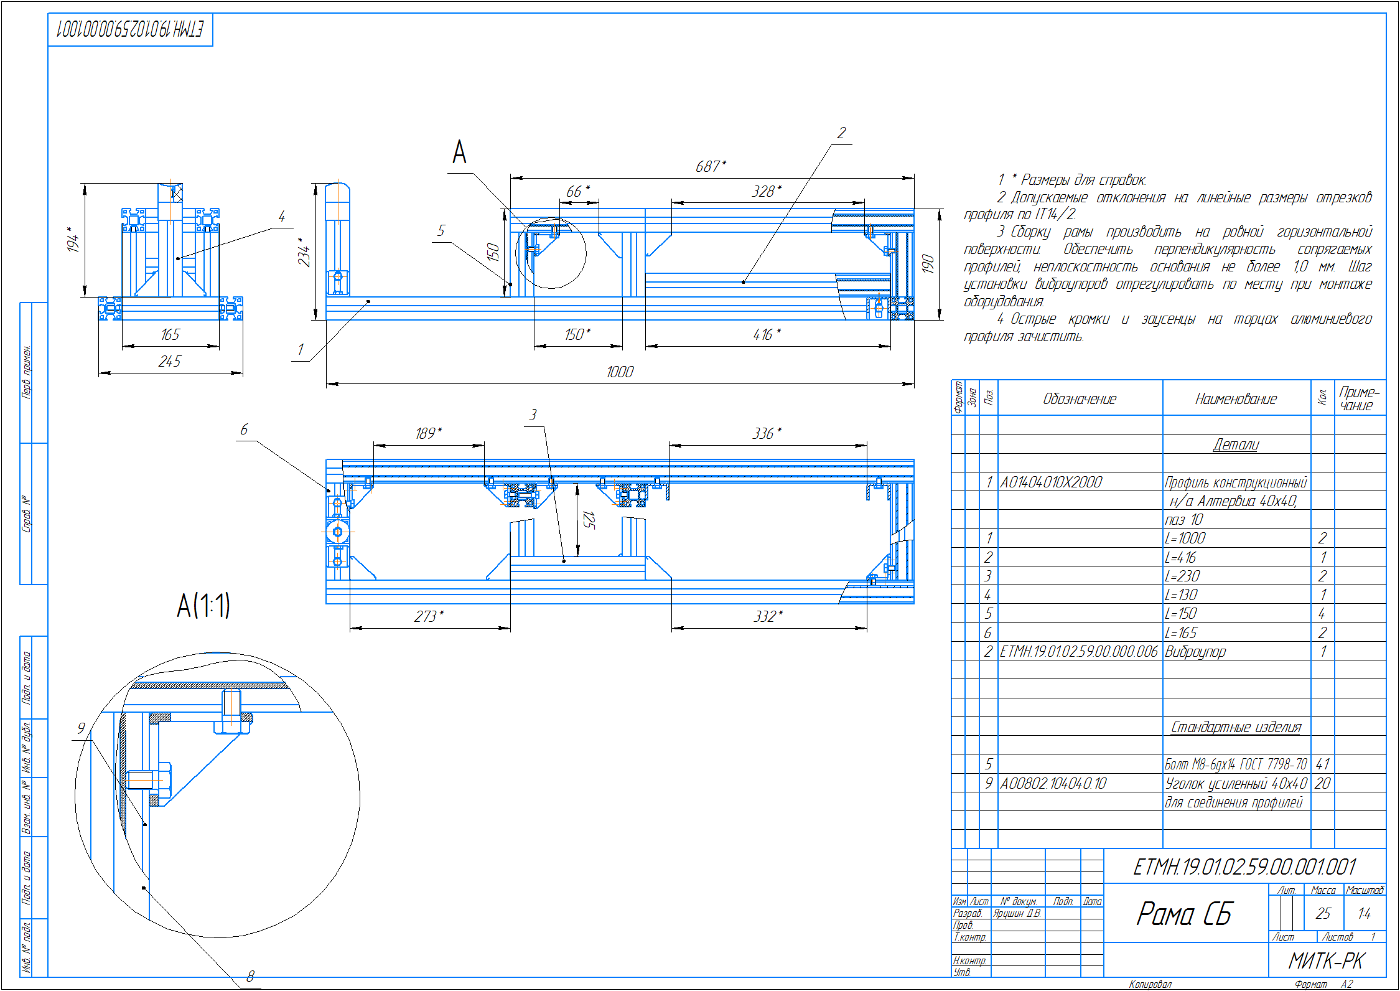
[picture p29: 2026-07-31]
assets/drawing-previews/cdw-frame.png

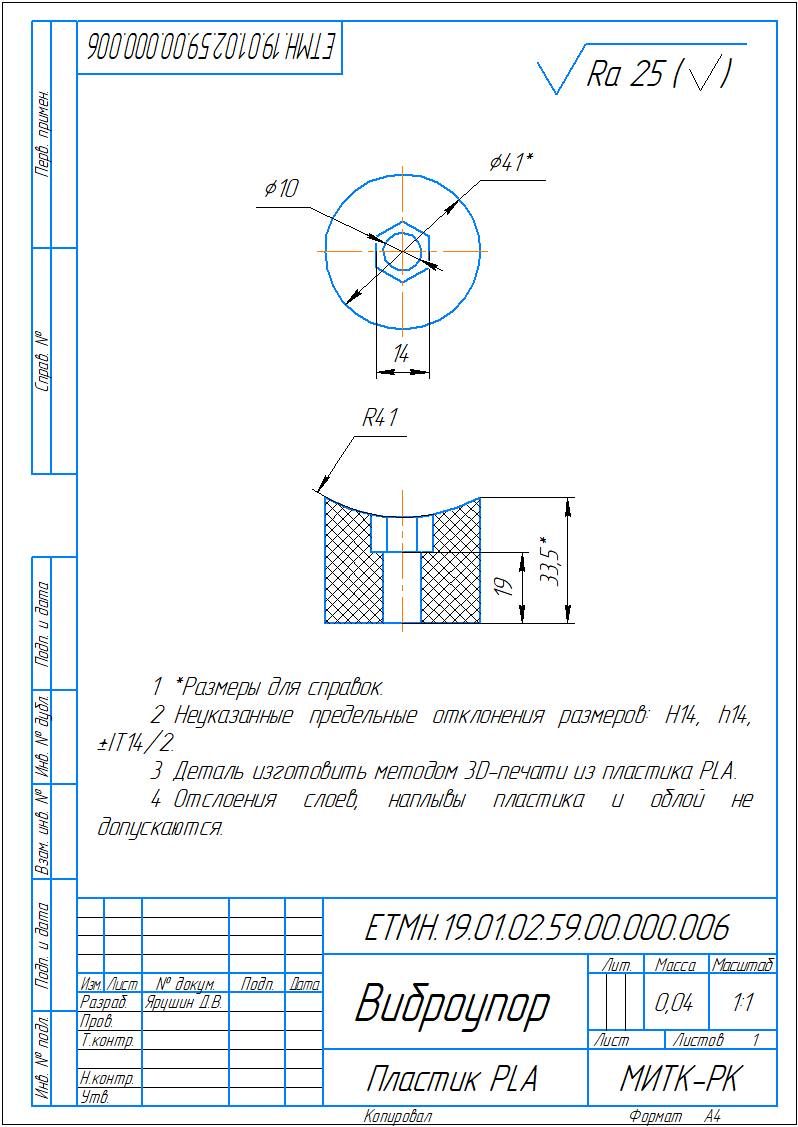
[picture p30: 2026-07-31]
assets/drawing-previews/cdw-vibrostop.png

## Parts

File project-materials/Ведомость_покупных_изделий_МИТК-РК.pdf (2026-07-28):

technicaldocs.ru

Подпись и дата Взам. инв. № Инв. № дубл. Инв. № подл. Подпись и дата

УТВЕРЖДЕН

ЕМТН.19.01.02.60.00.000.0000.ВП-ЛУ

Наименование вида АС

Гибридное рабочее колесо

Сокращенное наименование АС

ВЕДОМОСТЬ ПОКУПНЫХ ИЗДЕЛИЙ

ЕМТН.19.01.02.60.00.000.0001.ВП

Подпись и дата Взам. инв. № Инв. № дубл. Инв. № подл. Подпись и дата

Изм. | Лист | № докум. | Подп. | Дата

Разраб.

Пров.

Н. контр.

Утв.

## ЕМТН.19.01.02.60.00.000.0001.ВП

Гибридное рабочее колесо

Ведомость покупных изделий

Лит. | Лист | Листов
| 2 | 7

Наименование исполнителя

№ строки
Наименование | Код
продукции

Обозначение
документа
на поставку
Поставщик | Куда входит
(обозначение)

Количество

Приме-
на из- | чание
делие

в комплекты

на регулир.

Всего

1

Электродвигатель 5АИ 80 А2

1.5/3000 IM 2081

01.01.213539

23536479 | ВсеИнструменты.ру | ЕМТН.19.01.02.60.00.000.0101 | 1 | 1
2 | Преобразователь частоты

Systeme Electric STV050

Hertz 2,2 кВт, 220 В, ЭМС, С3

+ LED панель оператора

STV050U22M2

38297088 | ВсеИнструменты.ру | ЕМТН.19.01.02.60.00.000.0102 | 1 | 1
3 | Провод Кабель-Арсенал ПВС

3x2,5 ГОСТ DIY 10 м KARS-

54648

16381628 | ВсеИнструменты.ру | ЕМТН.19.01.02.60.00.000.0103 | 1 | 1
4 | Кабель ВВГ-ПНГ А - LS

Камкабель 3x2.5 мм 5 м

ГОСТ

1157К30HG00070А0005М

21431824 | ВсеИнструменты.ру | ЕМТН.19.01.02.60.00.000.0104 | 1 | 1
5 | Автоматический 3-полюсный

выключатель, 16А, С ВА47-

29 4.5кА IEK MVA20-3-016-C

15164448 | ВсеИнструменты.ру | ЕМТН.19.01.02.60.00.000.0105 | 1 | 1
6 | Контактор IEK КМИ-22510

25А 220В ИЭК KKM21-025-

230-10

15165144 | ВсеИнструменты.ру | ЕМТН.19.01.02.60.00.000.0106 | 1 | 1
7 | Кнопка ANDELI XB2-EA131

Пуск Возвратная Зеленая

NO - НО D22мм 230В ADL10-

094

17373108 | ВсеИнструменты.ру | ЕМТН.19.01.02.60.00.000.0107 | 1 | 1

Подпись и дата Взам. инв. № Инв. № дубл. Инв. № подл. Подпись и дата

Изм. | Лист | № докум. | Подп. | Дата

## ЕМТН.19.01.02.60.00.000.0001.ВП

Лист

№ строки
Наименование | Код
продукции

Обозначение
документа
на поставку
| Поставщик | Куда входит (обозначение)
Приме-
на из- | чание
| | | делие

в комплекты

на регулир.

| | | | Всего
8 | Кнопка аварийного стопа

Emas 240В, 0,3А. 1НЗ

MB200E

16294255 | ВсеИнструменты.ру | ЕМТН.19.01.02.60.00.000.0108 | 1 | 1
9 | Корпус IEK KREPTA 3 ЩРН-

П-8 IP41, черный,

пластиковый MKP12-N-08-41-

K02

16523599 | ВсеИнструменты.ру | ЕМТН.19.01.02.60.00.000.0109 | 1 | 1
10 | Наконечник КВТ НШВИ2 2,5-

10 (100шт/уп) 79468

16052910 | ВсеИнструменты.ру | ЕМТН.19.01.02.60.00.000.0110 | 1 | 1
11 | Угловая вилка MAKEL с

заземлением 16 А 250 В с

кольцом белая 10037

34458001 | ВсеИнструменты.ру | ЕМТН.19.01.02.60.00.000.0111 | 5 | 5
12 | Распределительная коробка

FORTISFLEX герметичная

mg box s-4 ip68 89511

31679115 | ВсеИнструменты.ру | ЕМТН.19.01.02.60.00.000.0112 | 2 | 2
13 | Провод ПВС АЛЬФАКАБЕЛЬ

4х2,5 мм ГОСТ 5 м 05067

16423497 | ВсеИнструменты.ру | ЕМТН.19.01.02.60.00.000.0113 | 1 | 1
14 | Угленаполненный нейлон

Solution print Nylon-12 Carbon

Fiber (PA12-CF) черный,

CartriDge 361801

43417336 | ВсеИнструменты.ру | ЕМТН.19.01.02.60.00.000.0114 | 1 | 1
15 | 5inch DSI LCD (Rev2.2), TFT

дисплей 800x480 px с

емкостной сенсорной

панелью для Raspberry Pi,

DSI

9000791753 | Сhipdip | ЕМТН.19.01.02.60.00.000.0115 | 1 | 1
16 | Raspberry Pi 4 Model B 2GB,

Одноплатный компьютер на

базе процессора Broadcom

BCM2711, Wi-Fi, Bluetooth

9000609664 | Сhipdip | ЕМТН.19.01.02.60.00.000.0116 | 1 | 1

Подпись и дата Взам. инв. № Инв. № дубл. Инв. № подл. Подпись и дата

№ строки
Наименование | Код
продукции

Обозначение
документа
на поставку
Поставщик | Куда входит
(обозначение)

Приме-
на из- | чание
делие

в комплекты

на регулир.

Всего

17 802.11b/g/n 150Mbps Wireless

USB Adapter, USB модуль

для подключения Raspberry

Pi

9000184964 | Сhipdip | ЕМТН.19.01.02.60.00.000.0117 | 1 | 1
18 | SB64GBSDCL10U3-01, Карта

памяти MicroSDXC 64ГБ

Class10 PRO U3 R/W:90/70

MB/s + SD адаптер

9000944758 | Сhipdip | ЕМТН.19.01.02.60.00.000.0118 | 1 | 1
19 | Отладочная плата на базе

MCU STM32F411CEU6

9001922977 | Сhipdip | ЕМТН.19.01.02.60.00.000.0119 | 1 | 1
20 | SS461A, Датчик Холла

биполярный защ цифровой

110G TO92

609423910 | Сhipdip | ЕМТН.19.01.02.60.00.000.0120 | 3 | 3
21 | ДМРВ Э116, Датчик

массового расхода воздуха

8033535243 | Chipdip | ЕМТН.19.01.02.60.00.000.0121 | 1 | 1
22 | DL-25W-V12-EXC, Блок

питания, 12В, 2.09А, 25Вт

9002077127 | Chipdip | ЕМТН.19.01.02.60.00.000.0122 | 1 | 1
23 | BB-801, Плата макетная

беспаечная 55х82х8.5 мм

9000297314 | Chipdip | ЕМТН.19.01.02.60.00.000.0123 | 1 | 1
24 | CHARGER65-CB, Блок

питания с разъемом USB

Type-C, GAN, PD 65Вт, макс.

3.25А (адаптер) черный

9002009304 | Chipdip | ЕМТН.19.01.02.60.00.000.0124 | 1 | 1
25 | plc-smk-413, Строительно-

монтажная клемма СМК 222-

413 с рычагом 3 отверстия

0,08-2,5мм2 PROxima

9000534750 | Chipdip | ЕМТН.19.01.02.60.00.000.0125 | 12 | 12

Подпись и дата Взам. инв. № Инв. № дубл. Инв. № подл. Подпись и дата

№ строки
Наименование | Код
продукции

Обозначение
документа
на поставку
Поставщик | Куда входит
(обозначение)

Приме-
на из- | чание
делие

в комплекты

на регулир.

Всего

26 DS18B20A10,

Влагозащищенный датчик

температуры с интерфейсом

1-Wire, гильза Ф6х50мм,

кабедь 1М

9001333337 | Chipdip | ЕМТН.19.01.02.60.00.000.0126 | 1 | 1
27 | 1.8inch LCD Module, 1,8-

дюймовый ЖК-дисплей,

128x160 пикселей,

интерфейс SPI

9001319628 | Chipdip | ЕМТН.19.01.02.60.00.000.0127 | 1 | 1
28 | ММП (АМП)-H30-0.2, Набор

монтажного провода 0,2мм,

30 метров

9000053517 | Chipdip | ЕМТН.19.01.02.60.00.000.0128 | 1 | 1
29 | DL-25W-V5-EXC, Блок

питания, 5В, 5А, 25Вт

9002077126 | Chipdip | ЕМТН.19.01.02.60.00.000.0129 | 1 | 1
30 | Комплект Виброопор

RF00V40P

8011089624 | Chipdip | ЕМТН.19.01.02.60.00.000.0130 | 1 | 1
31 | PT1200-A-2-B-0.5CN1G,

датчик давления 2 Bar 0-5В

1/4"NPT 10-30VDC кабель

0.5м

8017301432 | Chipdip | ЕМТН.19.01.02.60.00.000.0131 | 1 | 1
32 | Неодимовый магнит - диск

10×1 мм (50 шт)

9000305543 | Chipdip | ЕМТН.19.01.02.60.00.000.0132 | 1 | 1
33 | Болт с полной резьбой

МЕТАЛЛСЕРВИС m8x30, din

933, цинк, 1 кг, пакет мс

1245605

26505404 | ВсеИнструменты.ру | ЕМТН.19.01.02.60.00.000.0133 | 1 | 1
34 | Gigant Шайба DIN9021

кузовная оцинк. М8 100 шт

124072

40695455 | ВсеИнструменты.ру | ЕМТН.19.01.02.60.00.000.0134 | 1 | 1

Подпись и дата Взам. инв. № Инв. № дубл. Инв. № подл. Подпись и дата

№ строки
Наименование | Код
продукции

Обозначение
документа
на поставку
| Поставщик | Куда входит (обозначение)

Количество

Приме-
на из- | чание
| | | делие

в комплекты

на регулир.

| | | | Всего
35 | Сухарь пазовый 10 шт Dogus

Kalip 2.1.001.10.08.10

31429647 | ВсеИнструменты.ру | ЕМТН.19.01.02.60.00.000.0135 | 2 | 2
36 | Профиль конструкционный

н/а Алтервиа 40x40, паз 10

A01404010X2000

39702060 | ВсеИнструменты.ру | ЕМТН.19.01.02.60.00.000.0136 | 4 | 4
37 | Заглушка для профильного

паза 10 мм, черная, упаковка

2 метра Dogus Kalip

2.3.005.10.01.01x2

31430001 | ВсеИнструменты.ру | ЕМТН.19.01.02.60.00.000.0137 | 1 | 1
38 | Уголок усиленный для

соединения профилей

Алтервиа 10 шт

A00802.104040.10

38021100 | ВсеИнструменты.ру | ЕМТН.19.01.02.60.00.000.0138 | 2 | 2
39 | Углеткань (карбон) 240 г/м2

30х100 см, плетение Twill /

саржа

1511694534 | OZON | ЕМТН.19.01.02.60.00.000.0139 | 1 | 1
40 | Углеродная ткань Карбон,

плетение Plain, 200 гр.м2,

30*100см

1287150172 | OZON | ЕМТН.19.01.02.60.00.000.0140 | 1 | 1
41 | Эпоксидная смола для
карбона "Пропитай"
CarbonShine 1,5 кг
1228645753 | OZON | ЕМТН.19.01.02.60.00.000.0141 | 2 | 2

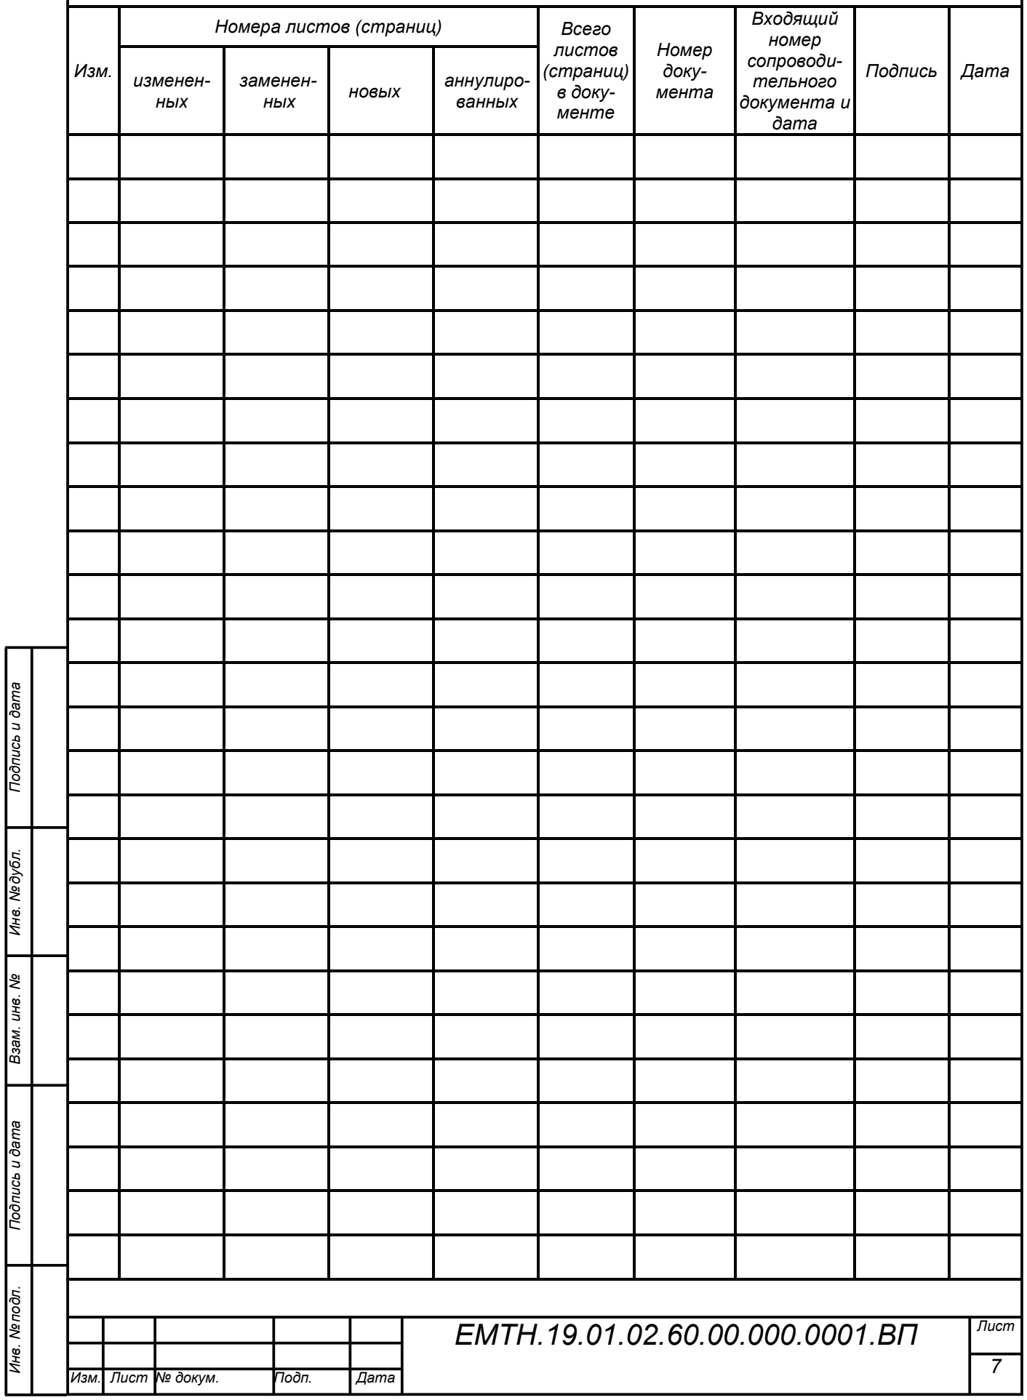
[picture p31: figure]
ЕМТН.19.01.02.60.00.000.0001.ВП; Лист; Изм.; Номера листов (страниц); Всего; листов (страниц) в доку- менте; Номер доку- мента; Входящий номер сопроводи- тельного документа и дата; Подпись; Дата; изменен- ных; заменен- ных; новых; аннулиро- ванных

Подпись и дата Взам. инв. № Инв. № дубл. Инв. № подл. Подпись и дата

Лист регистрации изменений

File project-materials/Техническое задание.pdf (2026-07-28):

# Гибридное рабочее колесо: композитно-металлическая архитектура для высоконапорных центробежных компрессоров

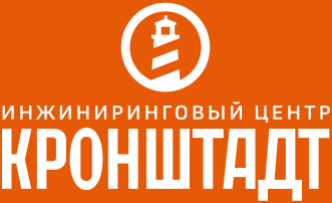
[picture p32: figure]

Неватус Иван Сергеевич,
инженер-конструктор 1 кат.

# «Соревнования конструкторских бюро: Остров инженеров»

Изготовление полуоткрытого рабочего колеса центробежного компрессора из композитных материалов и проверка его
работоспособности

По итогам мероприятия планируется получить:

- рабочее колесо компрессора из композитных материалов;
- отработать технологию
изготовления;
- стенд для испытаний.

Успешными критериями оценки является успешное прохождение:

- разгонных испытаний рабочего колеса;
- испытания рабочего колеса на работоспособность;
- валидации геометрии изготовленного колеса по отношению к исходной 3D модели.

Колесо, изготовленное из
композитных материалов, позволяет получить модельное колесо в более сжатые сроки по отношению к изделиям из классических
материалов.
Такие колеса можно использовать для валидации математической модели, а так же как ремонтное решение на ограниченный срок работы агрегата, с целью
уменьшения простоя оборудования
Цель и задачи | Описание

# результата

Критерии оценки | Ценность и новизна
01 | 02 | 03 | 04

2

# Разработка гибридной конструкции рабочего колеса центробежного компрессора из композитно-металлических материалов

## Центробежное колесо компрессора

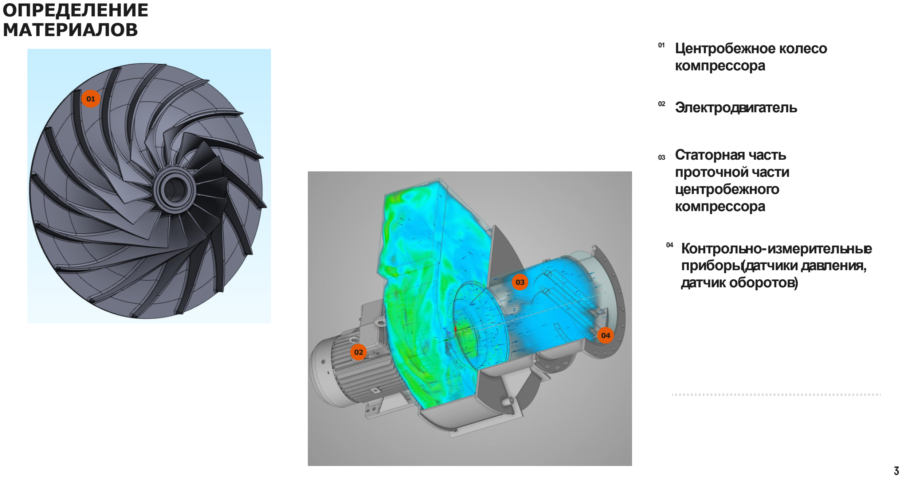
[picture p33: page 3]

## Электродвигатель

## Статорная часть проточной части центробежного компрессора

## Контрольно-измерительные

приборы(датчики давления,

## датчик оборотов)

01

04

02

03

# ОПРЕДЕЛЕНИЕ МАТЕРИАЛОВ

3

02

03

04

01

4

# Смета / Ресурсное обеспечение

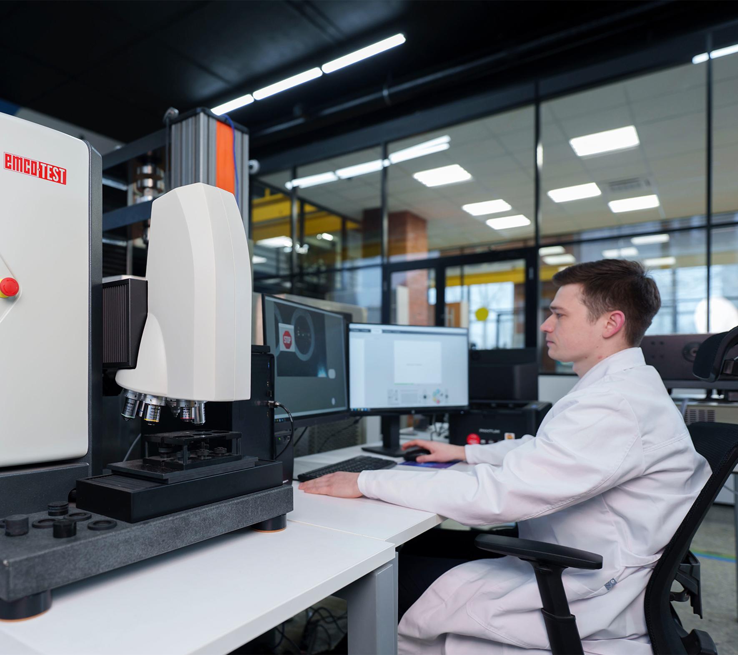
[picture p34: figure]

Материалы | Количество | Примерная стоимость
Углеткань | 20 | 50000

### Эпоксидная смола двухкомпонентная

10 | 20000

### Воск

разделительный | 2 | 2000

### Электродвигатель

+ частотный преобразователь | 1 | 50000
3D печать | - | 50000

## Geomagic Design X 2022.0

КОМПАС-3D v23 | Разработка 3д моделей

## 02 Анализ и валидация геометрии

01

# Необходимое ПО

5

Ansys Workbench | Проектирование газопроточной части компрессорного тракта
03

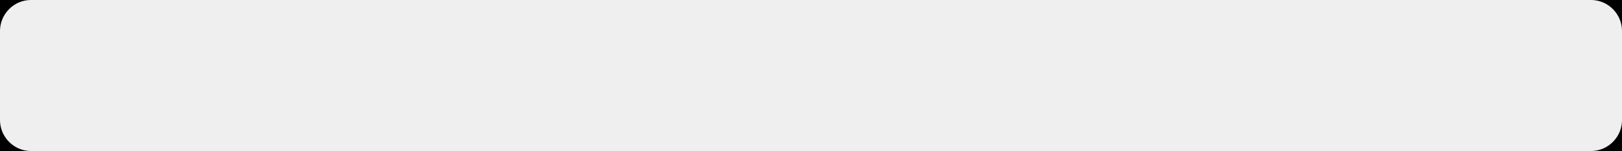
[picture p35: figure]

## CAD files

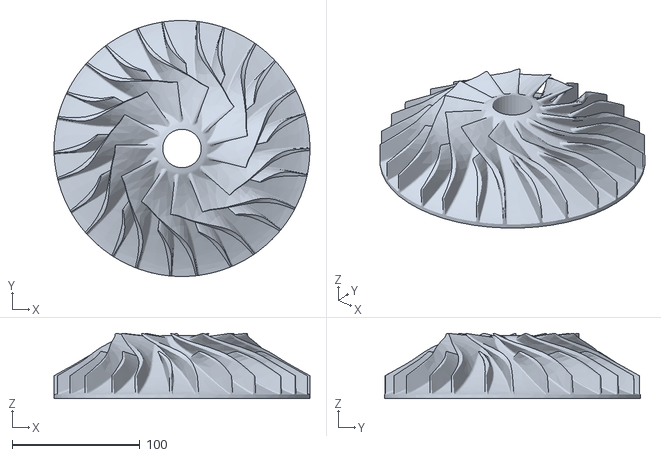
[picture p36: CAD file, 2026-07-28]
assets/models/rk-200-d.stl
200.0 x 200.0 x 51.0

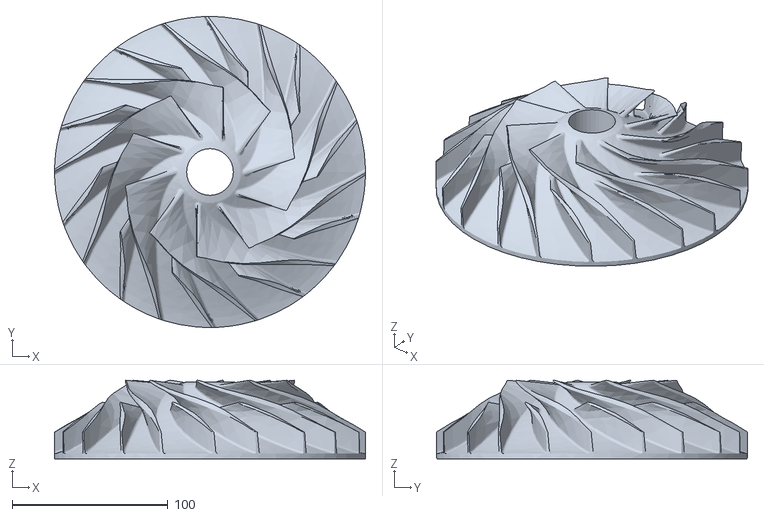
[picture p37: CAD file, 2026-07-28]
assets/models/rk-200-e.stl
200.0 x 200.0 x 50.5

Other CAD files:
drawings/Фланец_дмрв_(ABS).dwg
drawings/Правильная_крышка_корпуса_(ABS).dwg
drawings/Диффузор_(АBS).dwg

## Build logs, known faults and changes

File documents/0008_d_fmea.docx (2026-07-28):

Команда МИТК-РК

СОГЛАСОВАНО __________ | УТВЕРЖДАЮ __________

РАБОЧИЕ КОЛЁСА РК-200-Э И РК-200-Д ДИАМЕТРОМ 200 ММ

АНАЛИЗ ВИДОВ И ПОСЛЕДСТВИЙ ОТКАЗОВ

EMTH.19.01.02.59.00.000.0008 Д

2026

# 1 Методика

Предварительный FMEA конструкции и процесса использует шкалы тяжести S, вероятности O и обнаружения D от 1 до 10. S=1 означает пренебрежимо малое последствие, S=10 — возможное разрушение с угрозой безопасности; O=1 — крайне редкое событие, O=10 — ожидаемое частое; D=1 — почти гарантированное обнаружение до эксплуатации, D=10 — низкую вероятность обнаружения. RPN=S×O×D применяют только для расстановки приоритетов и не используют как самостоятельный критерий допуска. Оценки являются предварительными до документированного командного пересмотра; любой отказ с S≥9 требует отдельного инженерного решения независимо от RPN.

Таблица 1 — Реестр рисков конструкции, изготовления и испытаний

ID | Отказ | Последствие | Причина | S | O | D | RPN | Мера
F01 | Щель лопатка–ступица | Потеря жёсткости, разрушение | Ошибка CAD/булевых операций | 10 | 3 | 3 | 90 | STEP-проверка, одно твёрдое тело, сечение корня
F02 | Недостаточная толщина кромки | Недопечатка, скол | Геометрия/слайсер | 8 | 5 | 4 | 160 | Послойный просмотр, контрольный сегмент
F03 | Влажный PA12-CF10 | Поры, слабая межслойная связь | Нарушение сушки/хранения | 9 | 5 | 4 | 180 | 100 °C/10 ч, RH<20 %, журнал партии
F04 | Износ сопла | Недоэкструзия и изменение размера | Абразивное волокно | 8 | 5 | 5 | 200 | Износостойкое сопло, учёт наработки, калибровка
F05 | Расслоение Z | Отрыв лопатки | Параметры печати/дефект | 10 | 4 | 6 | 240 | Образцы Z, 100 % заполнение, визуальный контроль
F06 | Коробление диска | Биение, касание | Печать/отжиг | 9 | 4 | 3 | 108 | Плоская опора, контроль до/после отжига
F07 | Дисбаланс | Вибрация и усталость | Неравномерная печать/М2 | 10 | 6 | 3 | 180 | Статическая и динамическая балансировка
F08 | Трещина ступицы при запрессовке втулки из стали 40Х | Потеря удержания втулки | Чрезмерный натяг/удар | 10 | 4 | 4 | 160 | Кольцевой образец, пресс, запись усилия
F09 | Проворот втулки из стали 40Х | Потеря передачи момента | Слабая посадка/клей | 10 | 4 | 6 | 240 | Накатка, квалифицированный клей, контроль момента
F10 | Осевое смещение втулки | Касание/разрушение | Нет фиксации | 10 | 3 | 5 | 150 | Оснастка, контроль осевого положения по чертежу, клей
F11 | Дефект шпоночного паза | Концентрация напряжений | Обработка втулки | 9 | 3 | 4 | 108 | Размерный контроль и снятие заусенцев
F12 | Отслоение одного наружного слоя ткани М2 | Дисбаланс/попадание в поток | Низкая адгезия | 10 | 5 | 6 | 300 | Купоны адгезии, карта подготовки, контроль слоя
F13 | Асимметрия укладки М2 | Дисбаланс | Разный раскрой/масса смолы | 9 | 5 | 4 | 180 | Симметричные сегменты одного слоя, взвешивание, повторная балансировка
F14 | Смоляной наплыв | Сужение прохода | Избыток смолы | 7 | 5 | 3 | 105 | Вакуум/прикатка, шаблон прохода
F15 | Резонанс | Высокая вибрация | Совпадение собственных и возбуждающих частот | 10 | 4 | 7 | 280 | Modal, Campbell, ступенчатый разгон
F16 | Превышение частоты | Разрушение | Ошибка управления | 10 | 2 | 3 | 60 | Аппаратный предел 3 000 мин⁻¹ в текущей редакции, независимый тахометр; 12 000 мин⁻¹ — только по отдельному допуску
F17 | Касание корпуса | Удар и разрушение | Биение/малый зазор | 10 | 3 | 3 | 90 | Ручной проворот, контроль зазора
F18 | Посторонний предмет | Повреждение лопаток | Грязь во входе | 9 | 3 | 4 | 108 | Сетка/осмотр тракта, чистая сборка
F19 | Ошибка датчика давления | Неверный вывод о модели | Диапазон/ноль | 5 | 4 | 4 | 80 | Калибровка, нулевая проверка, повтор
F20 | Неуправляемая доработка | Ослабление корня/дисбаланс | Ручная обработка | 9 | 4 | 5 | 180 | Разрешённые зоны, запись массы и повторный контроль
F21 | Недостаточная прочность защитного корпуса | Выброс фрагмента, травма | Нет расчёта удержания | 10 | 2 | 7 | 140 | Расчёт энергии/удара, приёмка корпуса, дистанционный запуск
F22 | Отказ блокировки или аварийного останова | Невозможность безопасно остановить стенд | Электрический/логический отказ | 10 | 2 | 4 | 80 | Проверка перед серией, отказобезопасная схема, журнал срабатывания
F23 | Отказ вала или опор | Касание, разрушение сборки | Недопустимая частота, биение, перегрев | 10 | 3 | 5 | 150 | Подтверждение предельной частоты, контроль биения, температуры и вибрации

# 2 Приоритетные действия

Таблица 2 — Приоритетные действия и барьеры безопасности

ID | RPN | Обязательное действие | Ответственный | Статус
F12 | 300 | Купоны адгезии, карта подготовки, контроль слоя | ____________________________ | ____________________________
F15 | 280 | Modal, Campbell, ступенчатый разгон | ____________________________ | ____________________________
F05 | 240 | Образцы Z, 100 % заполнение, визуальный контроль | ____________________________ | ____________________________
F09 | 240 | Накатка, квалифицированный клей, контроль момента | ____________________________ | ____________________________
F04 | 200 | Износостойкое сопло, учёт наработки, калибровка | ____________________________ | ____________________________
F03 | 180 | 100 °C/10 ч, RH<20 %, журнал партии | ____________________________ | ____________________________
F07 | 180 | Статическая и динамическая балансировка | ____________________________ | ____________________________
F13 | 180 | Симметричные сегменты одного слоя, взвешивание, повторная балансировка | ____________________________ | ____________________________
F23 | 150 | Пределы вала/опор; контроль биения, температуры и вибрации | ________________ | ________________
F21 | 140 | Расчёт/приёмка защитного корпуса; дистанционный запуск | ________________ | ________________
F22 | 80 | Проверка блокировки и аварийного останова перед серией | ________________ | ________________

# 3 Правило закрытия риска

Риск закрывается только после выполнения меры, появления объективного доказательства и повторной оценки S/O/D. Снижение RPN без ссылки на протокол, расчёт, контроль или испытание не допускается.

EMTH.19.01.02.59.00.000.0008 Д Вер. Лист 01 3 Изм. Лист № докум. Подп. Дата Копировал Формат A4

Изм. Лист № докум. Подп. Дата Разраб. EMTH.19.01.02.59.00.000.0008 Д 01 Пров. Т. контр. Рабочие колёса РК-200-Э и РК-200-Д диаметром 200 мм Лит. Лист Листов Н. контр. 2 1 Утв. Команда МИТК-РК Копировал Формат A4

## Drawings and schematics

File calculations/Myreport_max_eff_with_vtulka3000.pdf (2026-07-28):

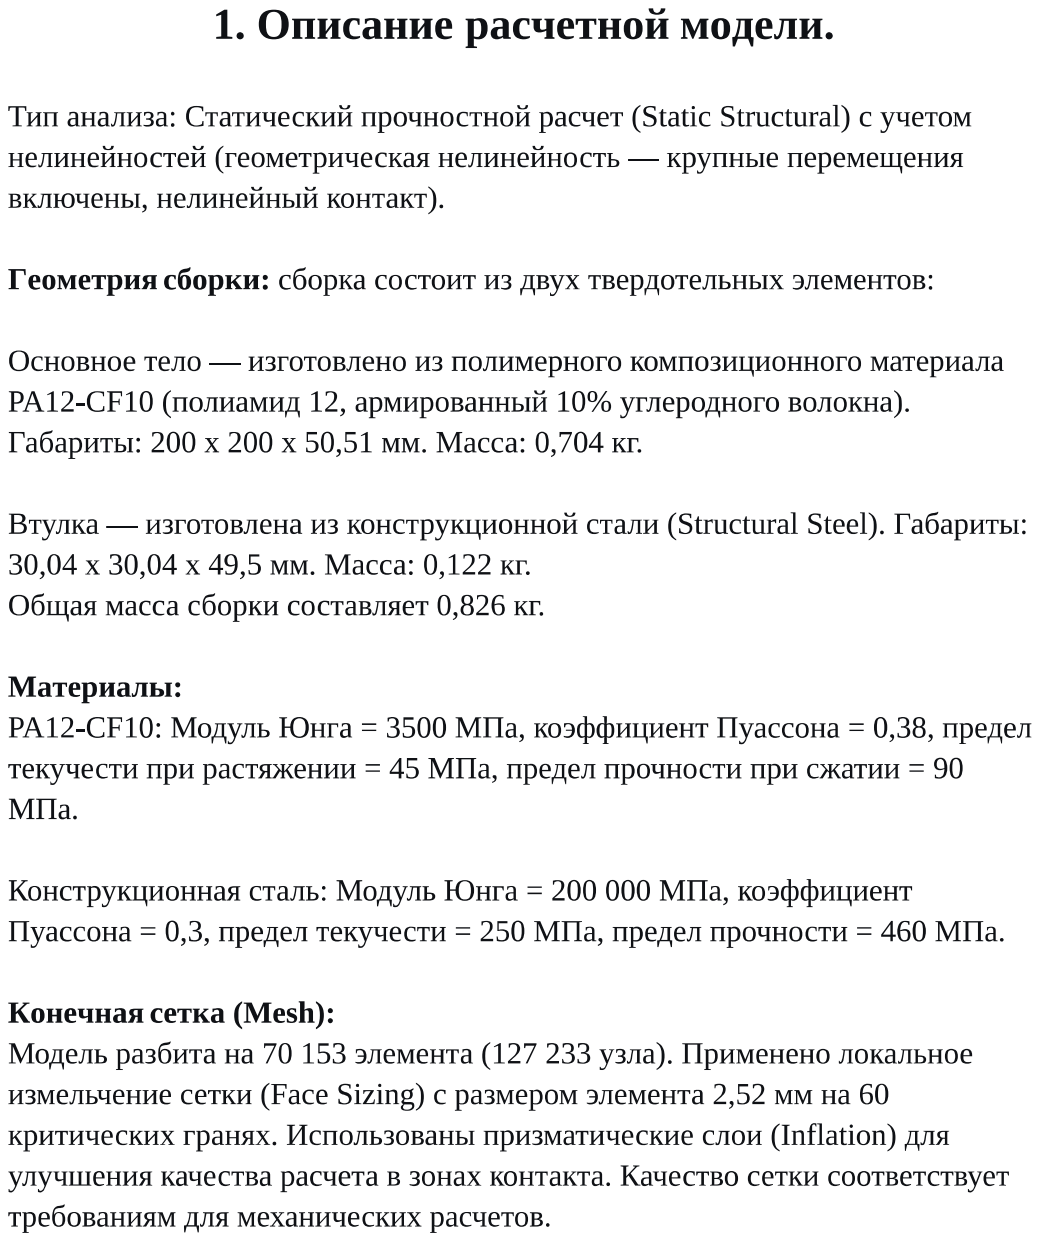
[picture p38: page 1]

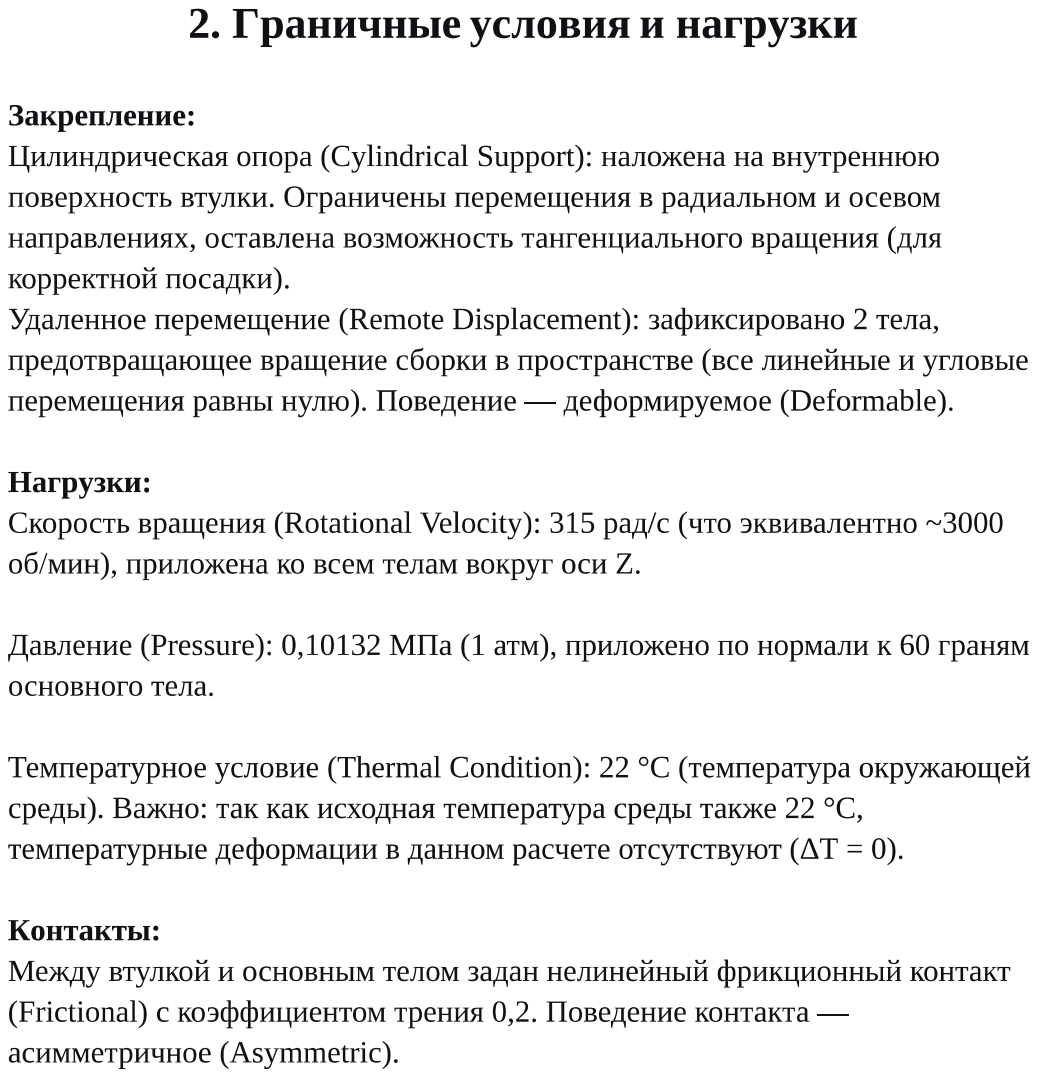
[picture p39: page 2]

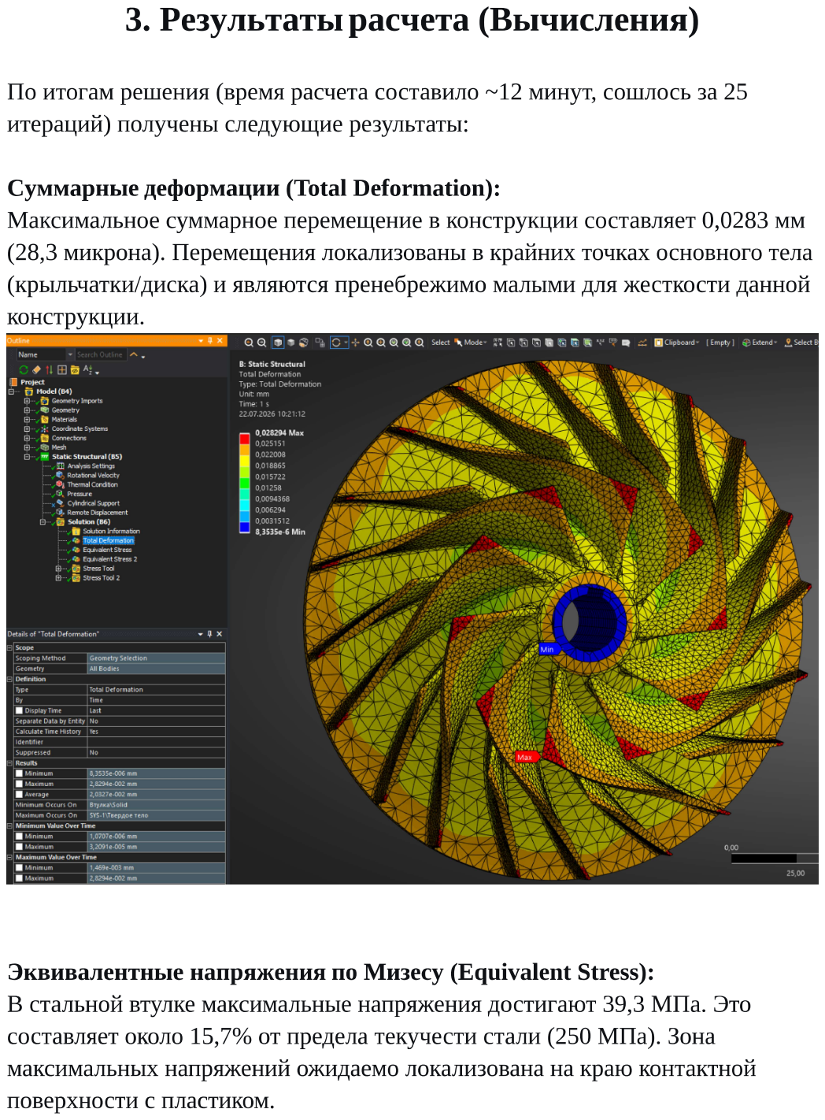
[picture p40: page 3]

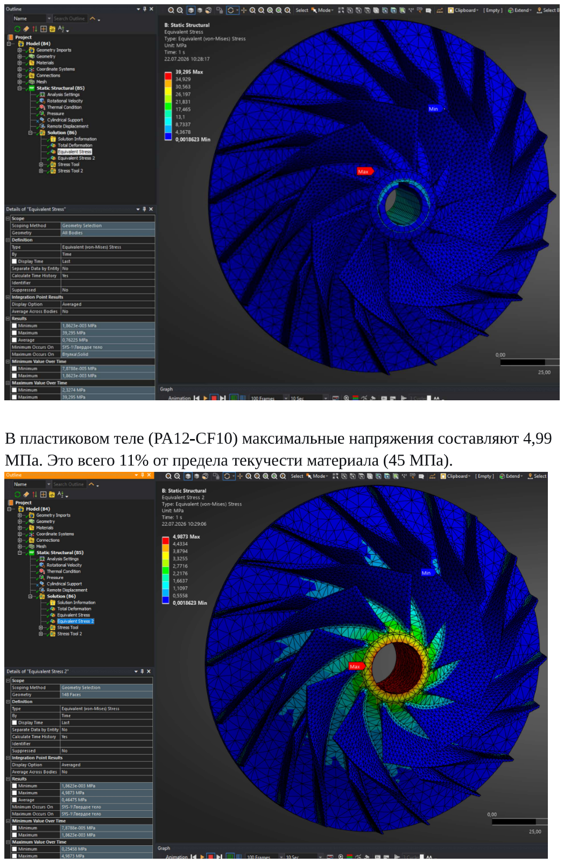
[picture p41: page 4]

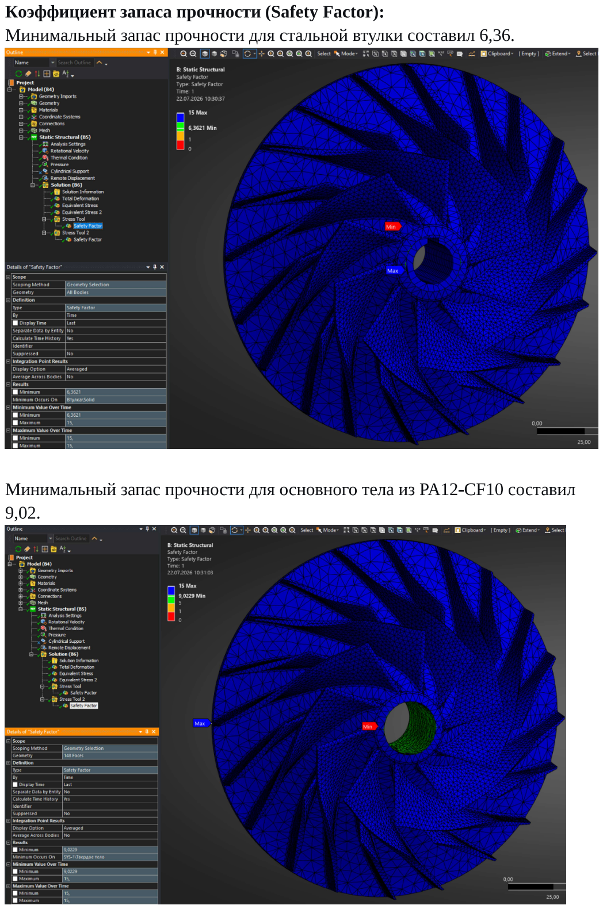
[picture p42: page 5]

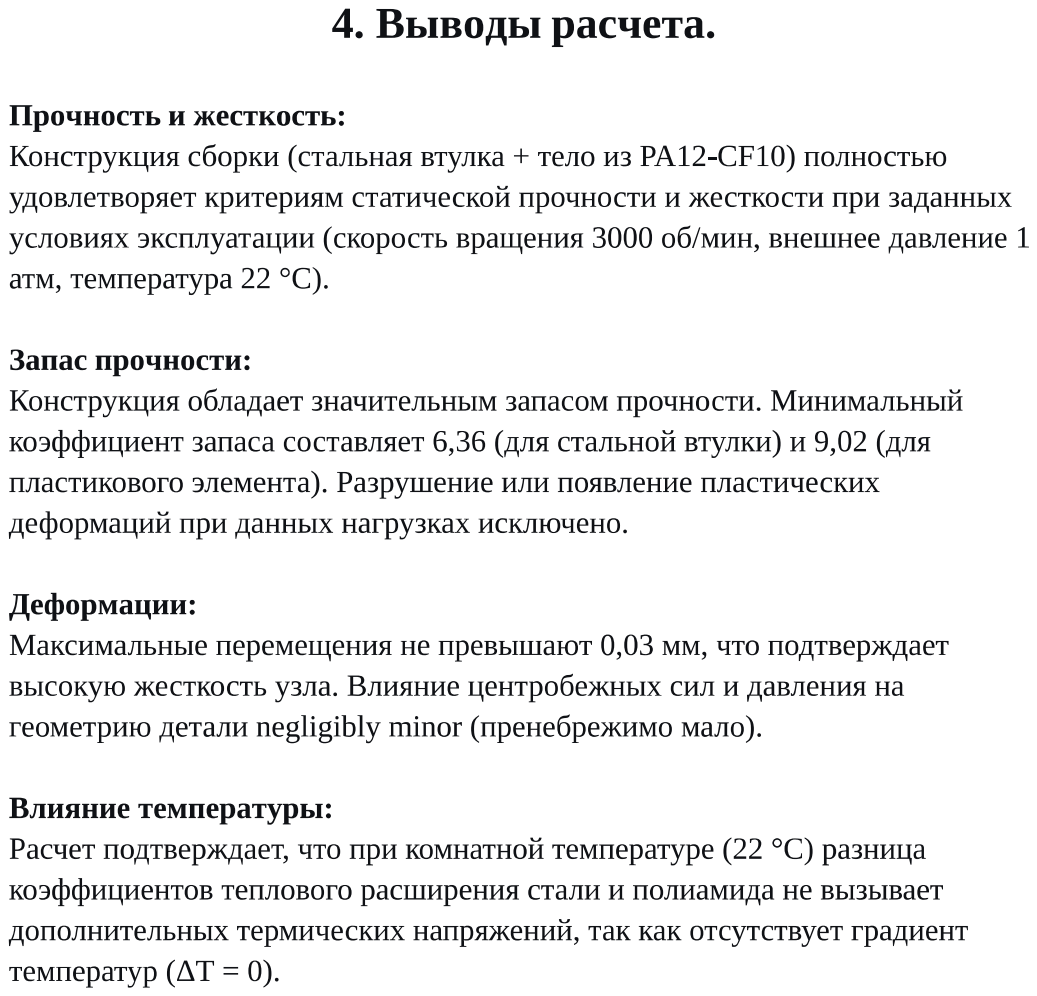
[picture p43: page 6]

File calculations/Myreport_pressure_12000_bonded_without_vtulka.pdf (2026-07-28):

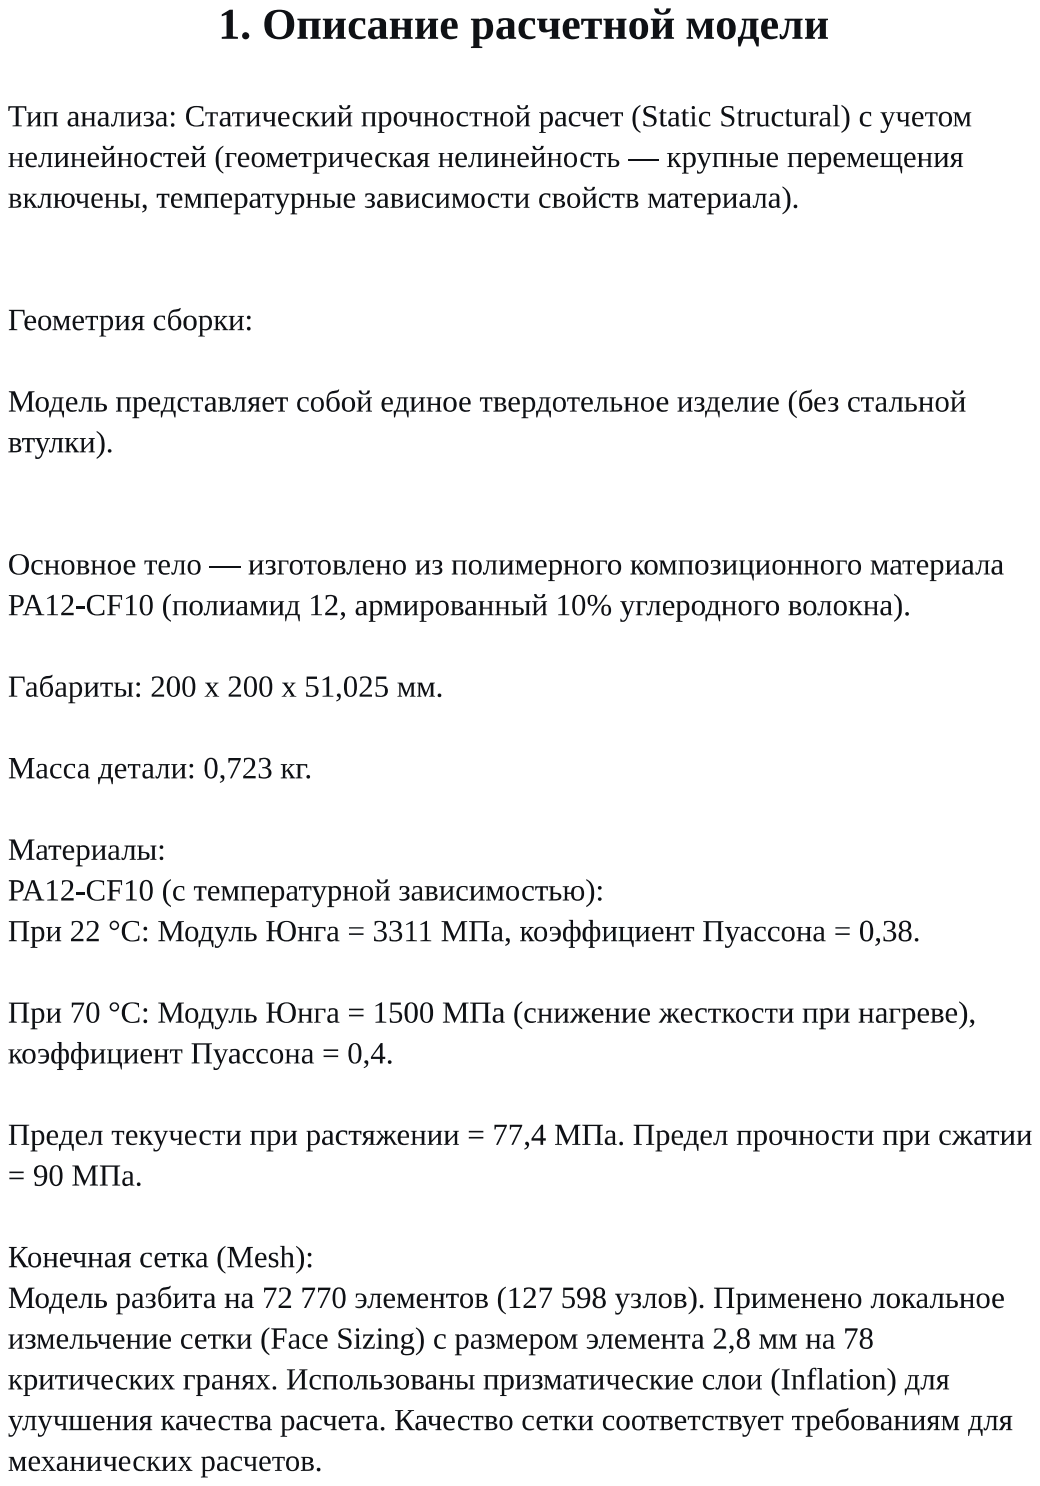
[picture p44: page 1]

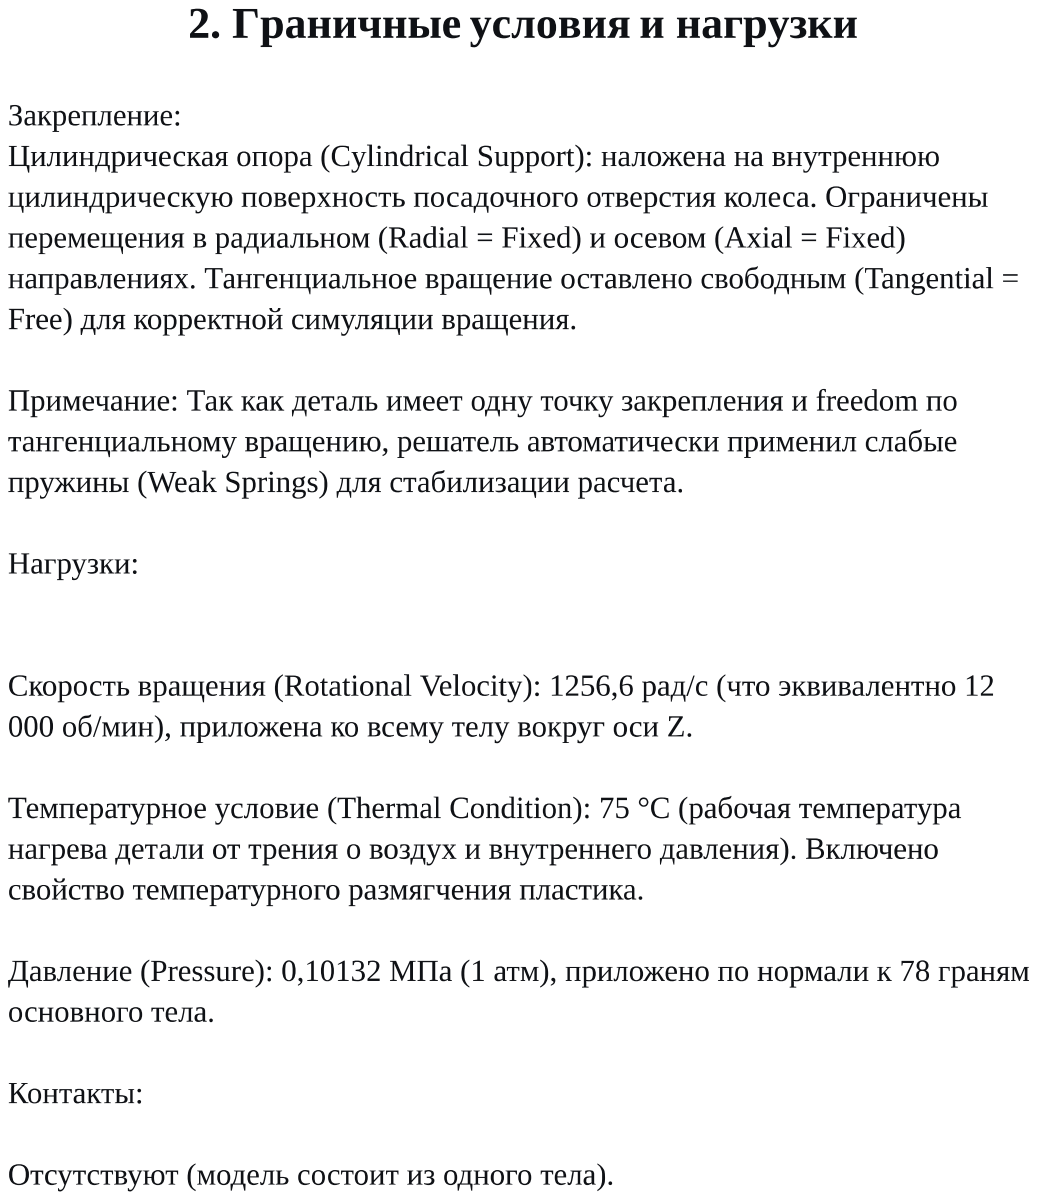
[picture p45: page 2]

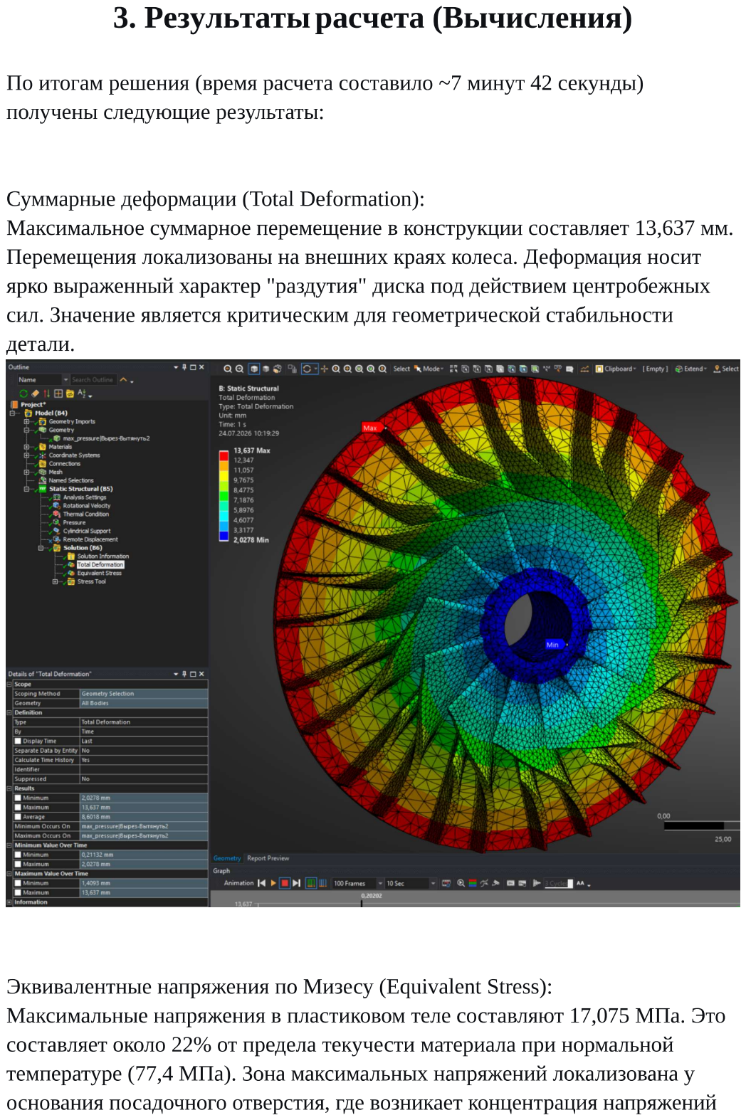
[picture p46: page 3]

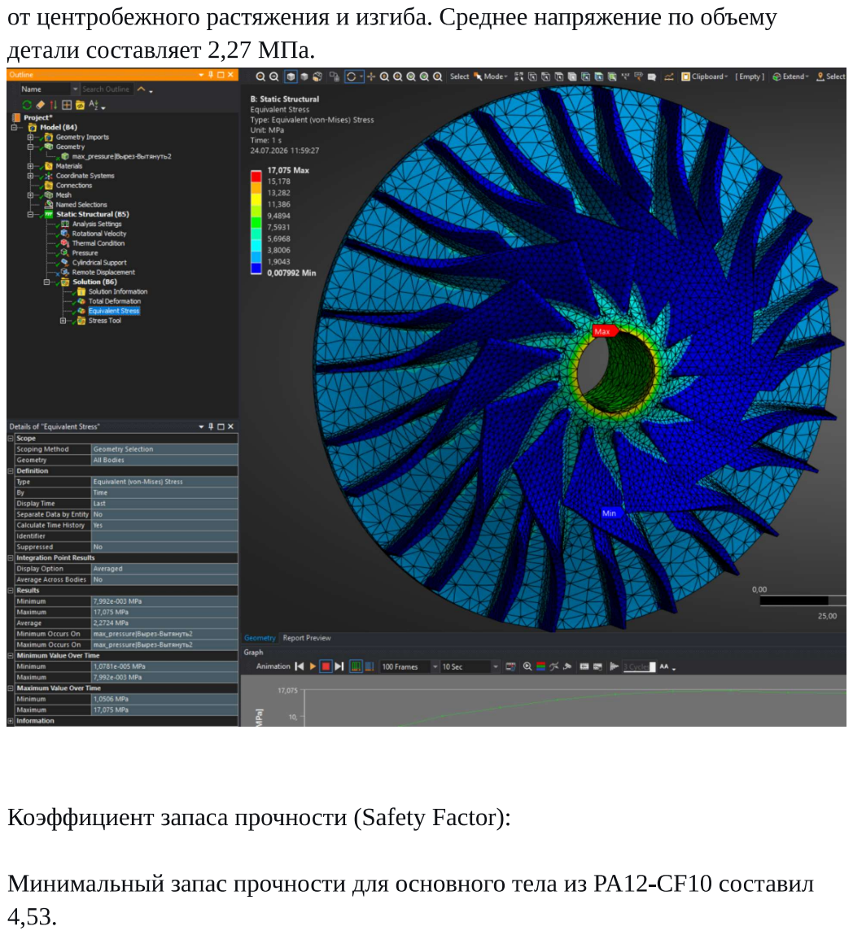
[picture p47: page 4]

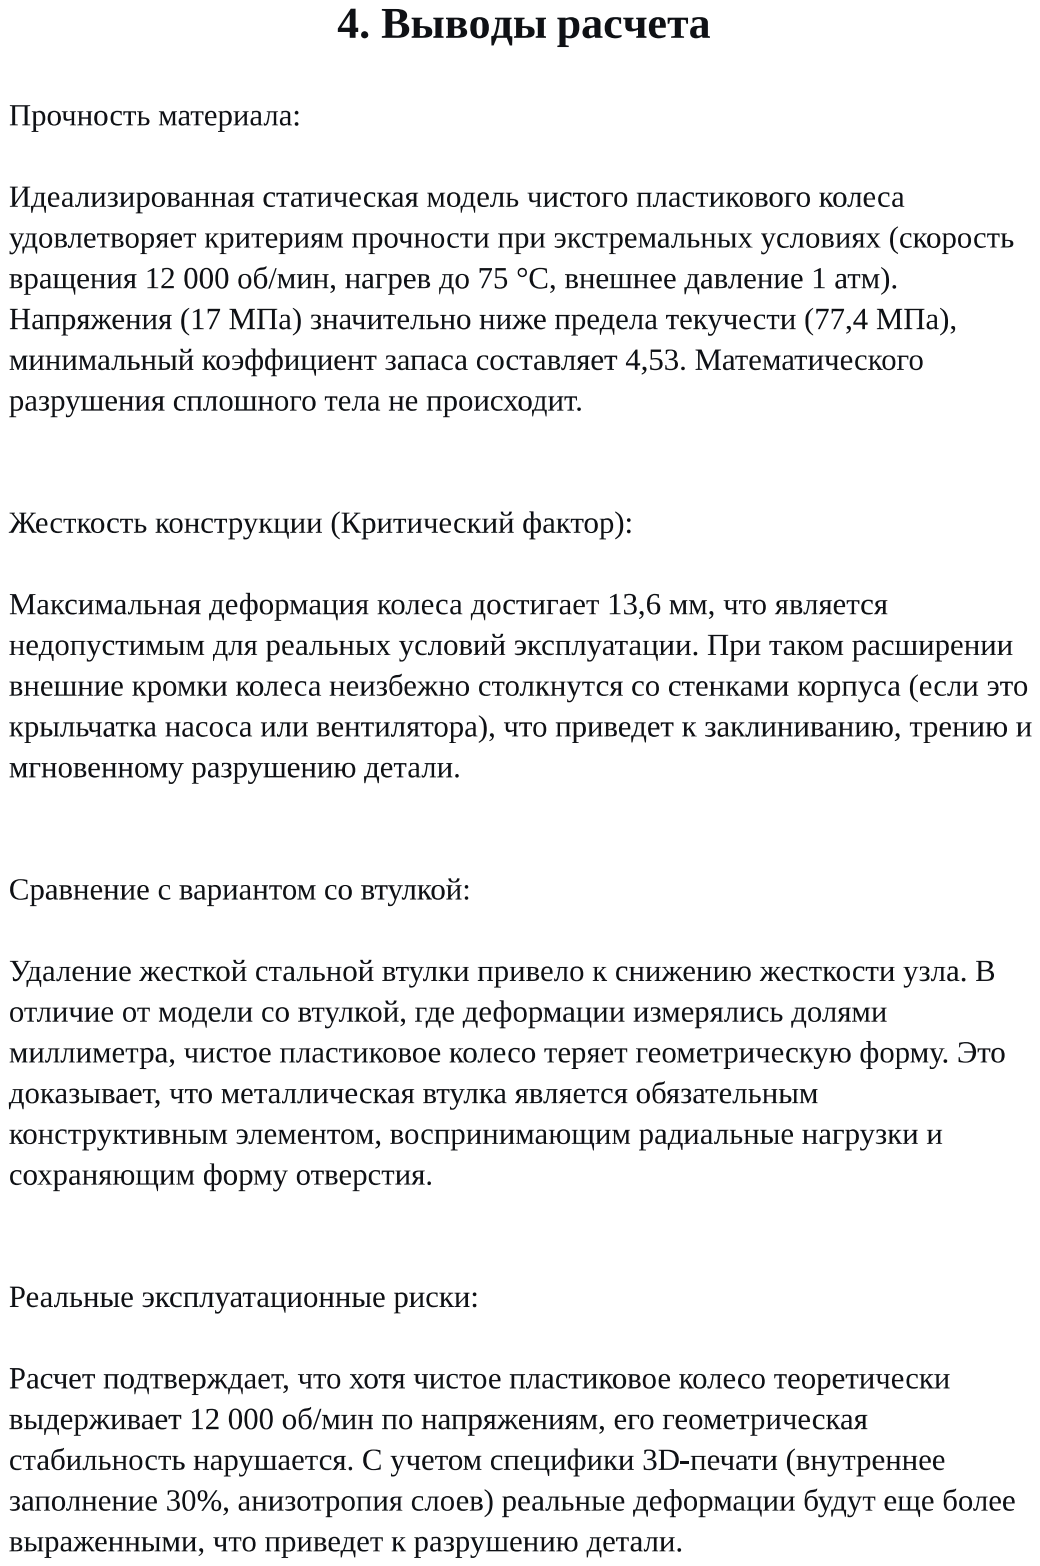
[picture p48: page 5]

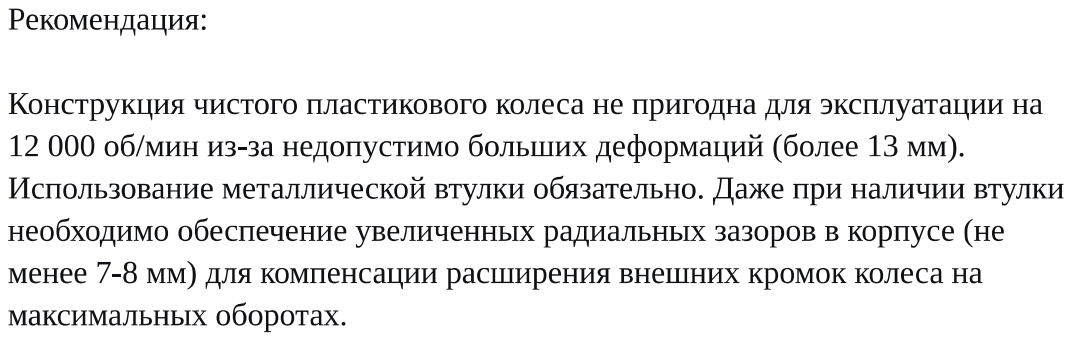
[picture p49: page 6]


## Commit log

2026-07-28 MITK-RK: initial site deploy
    [rk-200-d.stl, rk-200-e.stl, Диффузор_(АBS).dwg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]
2026-07-29 feat: этапы 1-7 — битые ссылки, CFD-изображения, фото производства, ANSYS видео, lightbox, hero-метрики, defer скриптов
2026-07-31 feat: полная галерея чертежей (13 листов), визитки, презентация, Google Drive + Miro
    [Полная ведомость лопаток (Варианты Д и Е.xlsx]
